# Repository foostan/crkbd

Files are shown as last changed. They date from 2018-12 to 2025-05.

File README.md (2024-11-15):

# Corne keyboard

The Corne keyboard is a split keyboard with 3x6 column staggered keys
and 3 thumb keys, based on [Helix](https://github.com/MakotoKurauchi/helix).
Crkbd stands for Corne Keyboard.

v4

## Latest versions
- corne-cherry: for Cherry MX compatible switches

  - v4 Hotswappable ([JP](docs/corne-cherry/v4/buildguide_jp.md)/[EN](docs/corne-cherry/v4/buildguide_en.md))
  - v4 Soldering (will be released)
- corne-chocolate: for Kailh choc v1 and v2 switches
  - v4 Hotswappable ([JP](docs/corne-chocolate/v4/buildguide_jp.md)/[EN](docs/corne-chocolate/v4/buildguide_en.md)):
  - v4 Soldering (will be released)

## Old versions

- corne-classic: for Cherry MX compatible switches 
  - v1 Soldering: ([JP](docs/corne-classic/buildguide_jp.md)/[EN](docs/corne-classic/buildguide_en.md))
- corne-cherry: for Cherry MX compatible switches
  - v2 Hotswappable: ([JP](docs/corne-cherry/v2/buildguide_jp.md)/[EN](docs/corne-cherry/v2/buildguide_en.md))
  - v2 Hotswappable tilting version: ([tilting, JP](docs/corne-cherry/v2/buildguide_tilting_tenting_plate_jp.md)/[tilting, EN](docs/corne-cherry/v2/buildguide_tilting_tenting_plate_en.md)):
  - v3 Hotswappable: ([JP](docs/corne-cherry/v3/buildguide_jp.md)/[EN](docs/corne-cherry/v3/buildguide_en.md))
- corne-chocolate: for Kailh choc v1 switches
  - v2 Hotswappable: ([JP](docs/corne-chocolate/v2/buildguide_jp.md)/[EN](docs/corne-chocolate/v2/buildguide_en.md)):
- corne-light: for easy build with a simple PCB
  - v1 Soldering: ([JP](docs/corne-light/v1/buildguide_jp.md)/[EN](docs/corne-light/v1/buildguide_en.md)):
  - v2 Soldering: ([JP](docs/corne-light/v2/buildguide_low_edition_jp.md)/[EN](docs/corne-light/v2/buildguide_low_edition_en.md)):

## Notice
There are currently reports of a bug in v4.* caused by electromagnetic interference. Depending on the environment, one or both of the left and right keyboards may stop working. It is known that this is often caused by EMI emitted by mobile phones. If you experience this kind of problem, reconnect the USB, move the EMI-generating device (probably a mobile phone) more than 30 cm away from the keyboard, and observe the situation.

For more details, please see this issue. We look forward to receiving any new information.
https://github.com/foostan/crkbd/issues/265

## Images

### Cherry
corne-cherry



### Chocolate
corne-chocolate



### Drawing
sketche

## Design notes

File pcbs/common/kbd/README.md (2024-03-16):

# KBD - for building keyboard libraries

## KiCad Footprint Libraries

This repository contains the KiCad footprint libraries for building keyboard.

**The libraries in this repository are intended to be used with KiCad version 5 or with a nightly that supports rounded rectangle and polygon pads.**

Each footprint library is stored as a directory with the `.pretty` suffix. The footprint files are `.kicad_mod` files within 

## KiCad Symbols

This repository contains the KiCad schematic symbol libraries for building keyboard.

**The libraries in this repositiory are intended for KiCad version 5.x**

Each symbol library is stored as a `.lib` and `.dcm` file pair.

## KiCad 3D Models
This repository contains 3D models for rendering and MCAD integration, for use with [KiCad EDA](http://www.kicad.org/) software.
The model needs a mechanical model source (a manually-modelled or script-generated file); its WRL counterpart file must be obtained as a conversion from the MCAD model

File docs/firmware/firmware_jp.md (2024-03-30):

# Firmware

バージョンによって使用するファームウェアのリビジョンが異なりますので下記よりお選びください。

- v1 - v3
  - [rev1](rev1/firmware_jp.md)
- v4
  - [rev4](rev4/firmware_jp.md)

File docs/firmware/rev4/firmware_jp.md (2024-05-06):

# ファームウェア
こちらは Corne v4向け(rev4) のファームウェアガイドになります。

## ファームウェアの書き込み
はじめにPCBのバージョンをご確認ください(v4.0.0 または v4.1.0)。\
そしてVIA/Vial用のファームウェアを下記からダウンロードします。

standard (3x6) v4.0.0

- [crkbd_rev4_0_standard_via.uf2](https://github.com/foostan/kbd_firmware/raw/main/keyboards/crkbd/qmk/qmk_firmware/.build/crkbd_rev4_0_standard_via.uf2)
- [crkbd_rev4_0_standard_vial.uf2](https://github.com/foostan/kbd_firmware/raw/main/keyboards/crkbd/vial-kb/vial-qmk/.build/crkbd_rev4_0_standard_vial.uf2)

mini (3x5) v4.0.0

- [crkbd_rev4_0_mini_via.uf2](https://github.com/foostan/kbd_firmware/raw/main/keyboards/crkbd/qmk/qmk_firmware/.build/crkbd_rev4_0_mini_via.uf2)
- [crkbd_rev4_0_mini_vial_mini.uf2](https://github.com/foostan/kbd_firmware/raw/main/keyboards/crkbd/vial-kb/vial-qmk/.build/crkbd_rev4_0_mini_vial_mini.uf2)

standard (3x6) v4.1.0

- [crkbd_rev4_1_standard_via.uf2](https://github.com/foostan/kbd_firmware/raw/main/keyboards/crkbd/qmk/qmk_firmware/.build/crkbd_rev4_1_standard_via.uf2)
- [crkbd_rev4_1_standard_vial.uf2](https://github.com/foostan/kbd_firmware/raw/main/keyboards/crkbd/vial-kb/vial-qmk/.build/crkbd_rev4_1_standard_vial.uf2)

mini (3x5) v4.1.0

- [crkbd_rev4_1_mini_via.uf2](https://github.com/foostan/kbd_firmware/raw/main/keyboards/crkbd/qmk/qmk_firmware/.build/crkbd_rev4_1_mini_via.uf2)
- [crkbd_rev4_1_mini_vial_mini.uf2](https://github.com/foostan/kbd_firmware/raw/main/keyboards/crkbd/vial-kb/vial-qmk/.build/crkbd_rev4_1_mini_vial_mini.uf2)

BOOTボタンを押しながらPCに接続するか、PCに接続した状態でBOOTボタンを押しながらリセットボタンを押します。
すると、RPI-PR2デバイスがマウントされます。

btn

ダウンロードしたuf2ファイルをRPI-PR2デバイスにドロップすると書き込みが完了します。

flash

片側にファームウェアの書き込みが完了したら、もう片方も同じ手順で書き込みを行います。

## (オプション) 自分でファームウェアをビルドする場合
こちらを参照してください。https://github.com/foostan/kbd_firmware

## キーマップの変更

### VIA

[VIA](https://usevia.app/) はVIA用のファームウェアを書き込むことで利用することできます。\
Corne v4を使う場合は、下記からjsonファイルをダウンロードし、VIAでロードしてください(設定画面のShow Design tabを有効にする必要があります)。

- [Corne v4](https://github.com/foostan/kbd_firmware/blob/main/keyboards/crkbd/the-via/crkbd_rev4.json)
- [Corne v4 mini](https://github.com/foostan/kbd_firmware/blob/main/keyboards/crkbd/the-via/crkbd_rev4_mini.json)

enable_design_tab
load_json
loaded_json

### Vial

[Vial](https://vial.rocks/) はVial用のファームウェアを書き込むことで利用することできます。

Vial

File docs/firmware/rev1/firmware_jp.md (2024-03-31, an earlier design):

# ファームウェア
こちらは Corne v1-v3向け(rev1) のファームウェアガイドになります。

## ファームウェアの書き込み

### [Remap](https://remap-keys.app/catalog/EfziB9K7ZcxLnIHXl5AQ/firmware) を使う
最も簡単で推奨する方法はRemapを使って crkbd:via を書き込む方法です。
Remapにアクセスし指示に従って書き込みを行ってください。
flash_by_remap

片側にファームウェアの書き込みが完了したら、もう片方も同じ手順で書き込みを行います。

### Flash the firmware by [QMK Toolbox](https://github.com/qmk/qmk_toolbox) を使う

VIA用のファームウェアを [crkbd_rev1_via.hex](https://github.com/foostan/kbd_firmware/blob/main/keyboards/crkbd/qmk/qmk_firmware/.build/crkbd_rev1_via.hex) からダウンロードします。

QMK Toolbox の 「Open」 からダウンロードしたファイルを指定します。
そしてキーボードをUSBで接続し、リセットボタンを押すとファームウェアの書き込みが始まります。
下記のように書き込みのメッセージが表示されれば完了です。

qmk_toolbox_flashed

片側にファームウェアの書き込みが完了したら、もう片方も同じ手順で書き込みを行います。

## (オプション) 自分でファームウェアをビルドする場合
こちらを参照してください。https://github.com/foostan/kbd_firmware

## キーマップの変更

[VIA](https://usevia.app/) はVIA用のファームウェアを書き込むことで利用することできます。

via_begin

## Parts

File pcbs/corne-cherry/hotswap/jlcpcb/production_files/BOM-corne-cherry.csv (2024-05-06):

Comment | Designator | Footprint | LCSC
W25Q128JVSIQ | U4,rU4 | SOIC-8_5.23x5.23mm_P1.27mm | C113767
1k | R3,R6,rR3,rR6 | R_0402_1005Metric | C11702
TRS | J2,rJ2 | PJ-398A-5A_PJ-399B-6A | C128994
TPD4E05U06DQAR | U3,rU3 | USON-10_2.5x1.0mm_P0.5mm | C138714
RB521S30T1G | ZD1,rZD1 | D_SOD-523 | C145179
NCP1117LPST33T3G | U2,rU2 | SOT-223-3_TabPin2 | C146799
100n | C10,C12,C13,C14,C15,C3,C4,C7,C9,rC10,rC12,rC13,rC14,rC15,rC3,rC4,rC7,rC9 | C_0402_1005Metric | C1525
10u | C11,C6,rC11,rC6 | C_0402_1005Metric | C15525
27p | C1,C2,rC1,rC2 | C_0402_1005Metric | C1557
RP2040 | U1,rU1 | QFN-56-1EP_7x7mm_P0.4mm_EP3.2x3.2mm | C2040
1N4148WT | D1,rD1 | D_SOD-523 | C232841
10k | R7,R9,rR7,rR9 | R_0402_1005Metric | C25744
5.1k | R1,R2,rR1,rR2 | R_0402_1005Metric | C25905
5.6k | R8,rR8 | R_0402_1005Metric | C25908
TYPE-C-31-M-13C | J1,rJ1 | TYPE-C-31-M-13C | C2848620
27 | R4,R5,rR4,rR5 | R_0402_1005Metric | C2909343
TS-1088R-02026 | SMDSW1,SMDSW2,rSMDSW1,rSMDSW2 | TS-1088R-02026 | C455280
YS-SK6812MINI-E | EXLED1,EXLED2,LED1,LED10,LED11,LED12,LED13,LED14,LED15,LED16,LED17,LED18,LED19,LED2,LED20,LED21,LED3,LED4,LED5,LED6,LED7,LED8,LED9,rEXLED1,rEXLED2,rLED1,rLED10,rLED11,rLED12,rLED13,rLED14,rLED15,rLED16,rLED17,rLED18,rLED19,rLED2,rLED20,rLED21,rLED3,rLED4,rLED5,rLED6,rLED7,rLED8,rLED9 | YS-SK6812MINI-E | C5149201
RotaryEncoder_Switch | EXSW1,EXSW2,SW1,SW10,SW11,SW12,SW13,SW14,SW15,SW16,SW17,SW18,SW19,SW2,SW20,SW21,SW3,SW4,SW5,SW6,SW7,SW8,SW9,rEXSW1,rEXSW2,rSW1,rSW10,rSW11,rSW12,rSW13,rSW14,rSW15,rSW16,rSW17,rSW18,rSW19,rSW2,rSW20,rSW21,rSW3,rSW4,rSW5,rSW6,rSW7,rSW8,rSW9 | keyswitch_cherrymx_hotswap_1u_rotary_encoder_ec12 | C5156480
1u | C16,C5,C8,rC16,rC5,rC8 | C_0402_1005Metric | C52923
12MHz 18pF | Y1,rY1 | Crystal_SMD_3225-4Pin_3.2x2.5mm | C91749

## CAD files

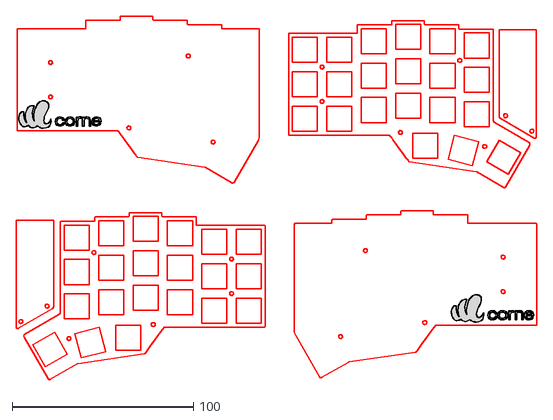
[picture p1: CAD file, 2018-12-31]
case/acrylic_plate/top-bottom.dxf
287.2 x 200.8

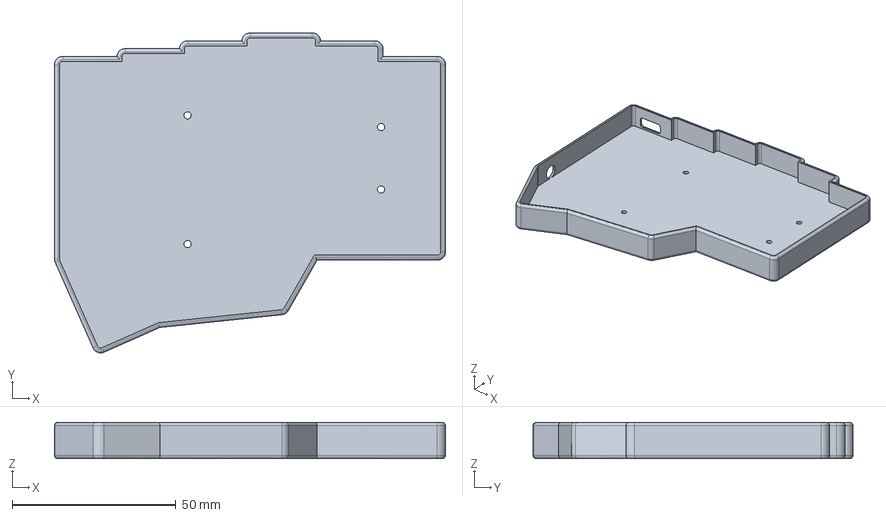
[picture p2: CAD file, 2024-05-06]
cases/3x5/right.step
119.3 x 97.6 x 11.1 mm

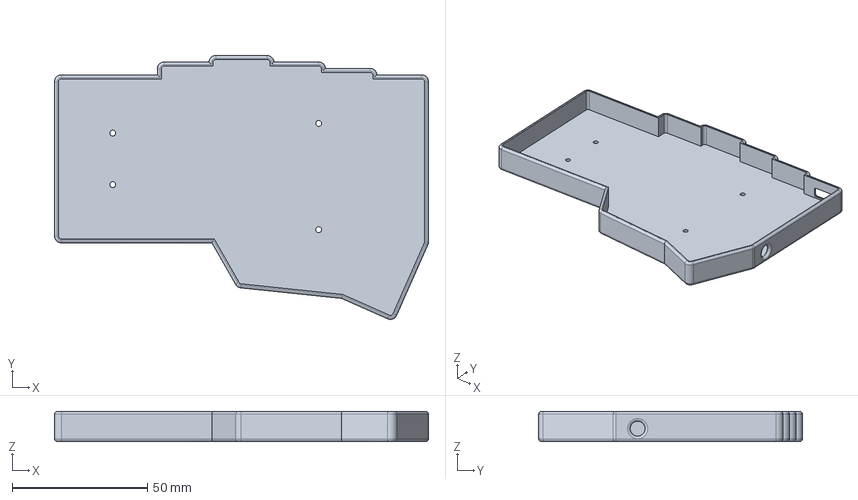
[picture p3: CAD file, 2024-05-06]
cases/3x6/left.step
138.3 x 97.6 x 11.1 mm

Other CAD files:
cases/3x5/left.step
cases/3x6/right.step

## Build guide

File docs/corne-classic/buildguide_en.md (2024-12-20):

# Build Guide

## Parts

### Required

| Name | Count | Remarks |
|:-|:-|:-|
| PCB | 2 | |
| Plate | 2 sets | |
| ProMicro | 2 | |
| TRRS Jack | 2 | |
| TRS(3 pole) cable | 1 | TRRS(4 pole) cable works too. |
| Tact switch | 2 | |
| Diode | 42 | You need SMD for low profile. |
| Key Switch | 42 | |
| Key Cap | 42 | 1u x 40,  1.5u x 2 |
| Spacer M2 7.5mm | 10 | use 3mm for low profile |
| Spacer M2 9mm or 11mm | 4 | |
| Screw M2 4mm | 28 | |
| Rubber foot | 10 | |

### Optional

| Name | Count | Remarks |
|:-|:-|:-|
| OLED Module | 1 or 2 | |
| 4x1 Pin Male Header | 2 | For OLED |
| 4x1 Pin Female Socket | 2 | For OLED |
| SK6812MINI | 54 | Front side x 42, back side x 12 |
| Addressable LED Strip | 2 | exclusive with SK6812MINI |



## Advance preparation

If you build the firmware yourself,
it will take some time to set up the environment,
so it's best to start at the beginning. \
For more information,
please see [docs/firmware/rev1](../firmware/rev1/firmware_en.md).

## Soldering

PCB is reversible; use one for the left hand side and the other for the right.

### Diodes

#### For non Low Profile keyswitches

Solder diodes as indicated in the picture.
You can place it on either side,
but front side is recommended if you implement under-glow LED.
You can use SMD diodes too.



Diode has polarity;
make sure to match the polarity with PCB silkscreen.

<- Before | After ->



#### For Low Profile Keyswitches

If you use low profile keyswitches,
you have to implement SMD diodes __on the back side__.
Otherwise, diodes will interfere with top plate.

As with normal diodes,
[SMD diodes have polarity](https://learn.sparkfun.com/tutorials/polarity/diode-and-led-polarity).
The lines on the SMD diode should be on the same side as the line on the PCB silkscreen.

### LEDs (Optional)

Implement LEDs under keyswitches (No. 7 through 27) upward facing,
and others (No. 1 through 6) on the back side(under-glow),
as indicated in the picture.



For No.7 to 27 LEDs, __Install LEDs from the back side__ as shown below.
Note the '**o**' silkscreen marking
and use them as a guide to implement LEDs in the direction.
On some versions  of the PCB (e.g. Corne-cherry v2),
the '**o**' silkscreen marking has been replaced by a white square
around one of the pads,
but the principle is still the same.



The LED has one pad that is shaped like a square.
That square should connect to the pad that has the '**o**' silkscreen marking:



There are many different techniques on how to solder the LEDs,
but [this video](https://twitter.com/foostan/status/1005656803818889216)
might give you an idea on how to do it.

For No. 1 to 6 LEDs, solder the pattern on the side of the device
(highlighted in pink on the picture) and the PCB pattern (blue on the picture).
Apply flux and take small amount of solder with a soldering iron
and press it on the edge of the patterns.



LEDs are connected in the order of the number on the picture above.
If it turns on only halfway,
it is likely that first LED that doesn't turn on
or the last LED that turns on is not implemented correctly.

__Note__ that the default Crkbd firmware has __LEDs turned off__,
so you'll have to turn them on before you can test
(see the firmware section for instructions how).

### Jumpers for OLED modules (optional)

To use OLED modules, short circuit the jumper patterns.
__Only short circuit the front side__



### TRRS socket, reset switch, OLED header sockets

Install TRRS sockets and reset switches as in the picture.
For OLEDs, also implement pin sockets.



### ProMicro

Before you start,
flash the Crkbd firmware to the ProMicros to make sure they are alright.

The ProMicro is then installed
__in the set of holes that has a white frame on the frontside of the PCB__.
Make sure you solder it in the right set of holes,
as desoldering the ProMicro is hard.
Implement pin headers in the white frame,
then install ProMicro with its __backside up__.



The picture is the right hand side, but it's the same for the left hand side -
pins into the through holes in the white frame as seen from the frontside,
placing the ProMicro with its backside up.

### OLED Module

Implement pin header onto the OLED modules,
then insert them into the pin sockets.



Adjust the height of the spacer accordingly to the height of pin header.
Most common pin header/socket and 11mm spacers are used in the picture.

### Use socket to Mount ProMicro

With using sockets for mounting ProMicro,
you can replace it easily when it breaks.
Two methods are introduced here.

#### Using Spring Loaded Header

Refer to the [Helix build guide](
https://github.com/MakotoKurauchi/helix/blob/master/Doc/buildguide_en.md#pro-micro)

ProMicro kit with spring loaded headers is available at Yusha-Kobo

<https://yushakobo.jp/shop/promicro-spring-pinheader/>

Using OLEDs available at Yusha-Kobo which come with low profile header,
together with and 9mm spacers, you can build them thin and gap-less.



#### Using Pin Sockets

Low profile pin sockets are available from Akizuki Denshi etc. Requires some work.

<http://akizukidenshi.com/catalog/g/gC-03138/>

Install a couple of 12x1 pin sockets on a breadboard.



Using male 12x1 pin headers, fixate ProMicro onto the pin sockets.



Remove plastic pin holders, solder the pins to ProMicro,
and then cut extra pins.



#### Comparison

Spring loaded headers can make the height lower.



Comparing pin-headers in the picture.
Headers come with OLED available at Yusha-Kobo are lower.



### Testing

It is recommended to test the ProMicro and OLED modules
before installing keyswitches,
because rework would be difficult after that.

First, build QMK Firmware for built for Crkbd
and install on ProMicro (if you haven't already done so).



Using the default keymap,
OLED will show information on the keyswitches being pressed.
Check the connections by short-circuiting keyswitch soldering pads
with tweezers or a bit of soldering wire.
Check all of them.

If you have OLED displays,
you can verify that all keys are responding
by looking at the log information showed there.
It will say which row and column was pressed,
e.g. `1x5` or `0x2`. Using the tweezers or wire,
connect each buttons soldering pads and make sure the display changes.
If something isn't working,
take note of the which row x column it is that isn't working,
as it can help when troubleshooting.

If you have mounted LEDs,
also make sure all of them are turned on.
As note before, the default firmware has LEDs __turned off__,
so you have to turn them on in the firmware before you test.



### Keyswitches and Top Plate

Sandwich top-plate with PCB and key-switches.



### Bottom Plate

Use 3mm spacers for low-profile,
Attach bottom plate to the PCB using 7.5mm (3mm for low-profile) spacers.
Then attach six rubber feet.



### Keycaps

Lastly install keycaps.

lrg_dsc03895

## Firmware

See below to flash the firmware to the ProMicro. \
[docs/firmware/rev1](../../firmware/rev1/firmware_en.md)

### Turning LEDS on

To turn the LEDs on, you have to edit the `rules.mk` file.
If you use the default layout,
it can be found here `keyboards/crkbd/keymaps/default/rules.mk`.
Add the following line to the top of the file:

```
RGBLIGHT_ENABLE = yes
```

Compile and flash to both sides and all LEDs should turn on
and __glow red__ if you have soldered everything correctly.
If you run the default firmware and the LEDs turn a differrent color,
the data to the LEDs is probably corrupted somewhere along the way.
Check the LED before the first one
turning a different color using the troubleshooting guide below.

## Troubleshooting

Here are some tips and tricks on how to troubleshot a board that is not working.

### No LEDs turn on

There are a number of things that might be wrong.
First of all, make sure you have __turned on LED lighting in the firmware__.
If that is the case, then chances are there might be a problem with the first LED.
Try the suggestions in the next section.

### Some LEDs not turning on

If some LEDs aren't turning on,
check the first LED not turning on __or__ the one before it.

LED numbering on the PCB

Here are some things to try out:

- Make sure the LED is soldered correctly.
  Check the pads to see if it looks like they have a proper connection.
- Check the LED orientation.
  Use the pictures above the see the correct orientation.
  Since the first LED is soldered with its back against the PCB,
  you might have to determinewhat the orientation should look like from the front
  using LEDs 7-27 (just double check that they are oriented correctly first).
- If both of the above looks good, chances are the LED was damaged during soldering.
  Either replace it directly or use the diod mode of a multimeter to test the connectivity.
  One way to do this is by simply comparing to some of the other LEDs you have soldered.
  Choose two of the LED's pads (out of the four available)
  and compare the reading to that of some of the other LEDs
  (taking care to measure the same pads with the same needles of your multimeter).
  Work your way through all combinations of pads and needles.
  If the differ, you either have a broken LED or bad connectivity.
  Or simply desolder the LED directly, might be quicker. :)

### A full row/column of keys not working

If a full row or column of keys is not working,
then the culprit is most likely the connection between the PCB and the ProMicro.
Check your soldering and make sure there's a proper connection
and that you have soldered the ProMicro in the right set of holes.
If soldering looks okay, then your ProMicro might be damaged.
You can exclude the possibility of problems with the PCB,
paths and diodes by short circuiting the pins on the ProMicro directly,
using a bit of wire.
Connecting one row pin with one column pin should result in the corresponding key.
Some PCBs have silkscreen print indicating which pin is which row or column,
to make this process easier.

### Random key(s) not working

If it is not a full row or column of keys that are not working,
the issue is most likely that there's no connection between the key and the ProMicro.
There are multiple places where the connection can get interupted:

- between keyswitch and PCB (if you have installed the switches)
- between keyswitch and hotswap socket (if you use them)
- between hotswap socket and PCB (again, if you use hotswap sockets)
- in the diodes between the key and the ProMicro
- in the paths inside the PCB

If you have installed the keyswitches already,
then check the soldering on the keyswitch.
if you use hotswap sockets,
check that you didn't accidentally bend one of the legs of the switch
when inserting into the socket and that the socket soldering is alright.

Next, visually inspect the PCB.
If it looks scratched or damaged anywhere along the path
from ProMicro to diode to keyswitch, the path might be interrupted.
If you find a spot that looks damaged,
you can use some wire to bypass the section that is damaged
(e.g. connecting the ProMicro directly to the first pad of the diode).
If this fixes the key, then you can either opt to keep the wire permanently,
or you can try to repair the path.
The path can be repaired by carefully scraping off the paint
from a section of the path that is okay on either side of the damaged part
(use a small flat head screwdriver intended for electronics).
Then clean carefully with alcohol and solder a new connection.
Youtube might have some guides on how to do this.

If the PCB looks okay, then the diode would be the next thing to check.
Begin by checking the soldering.
If it looks okay, then the diode itself might be damaged.
If you have a multimeter, use it to check the diode.
The reading should be the same as for diodes connected to keys that are working
(when measuring, remember that diodes have polarity).
You can also use tweezers or a bit of soldering wire
to connect the soldering pads on each side of the diode if you don't have a multimeter.
Pressing the key (or short circuiting the pads where the key would go)
after connecting the pads should make a key press being registered.
If this is the case, or if you used the multimeter
and got a different reading from the diode,
then check your soldering and replace the diode if necessary.

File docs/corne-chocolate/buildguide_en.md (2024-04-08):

# Build Guide

This is the Corne Chocolate build guide.
The build guide differs depending on the version of your board,
so please choose your own from the following.

- [v2 build guide](https://github.com/foostan/crkbd/blob/main/docs/corne-chocolate/v2/buildguide_en.md)
- [v4 build guide](https://github.com/foostan/crkbd/blob/main/docs/corne-chocolate/v4/buildguide_en.md)

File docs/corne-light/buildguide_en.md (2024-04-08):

# Build Guide

This is the Corne Light build guide.
The build guide differs depending on the version of your board,
so please choose your own from the following.

- [v1 build guide](https://github.com/foostan/crkbd/blob/main/docs/corne-light/v1/buildguide_en.md)
- [v2 low-edition build guide](https://github.com/foostan/crkbd/blob/main/docs/corne-light/v2/buildguide_low_edition_en.md)

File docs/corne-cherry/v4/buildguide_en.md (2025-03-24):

# Build Guide
This is the build guide for Corne Cherry v4.

corne-v4-cherry

## Parts

### Required

| Name | Count | Remarks |
|:---|:---|:---|
| PCB | 1 set | |
| Case | 1 set | |
| Switch plate | 1 set | FR4 1.6mm thick |
| Key switches | 42 - 46 | Only Cherry MX compatible |
| Keycaps | 42 - 46 | 1u 40 pcs, 1.5u 2 pcs |
| Spacer M2 | 8 | 7.5 mm For Case assembly |
| Screw M2 | 16 | 5 mm For Case assembly |
| Rubber cushion | 8 | |
| TRRS (4 poles) cable | 1 | v4.0.0: TRS (3 poles) cable is not compatible<br/>v4.1.0: TRS (3 poles) cable is compatible |
| Type-C cable | 1 | |

### Optional

| Name | Count | Remarks |
|:---|:---|:---|
| Rotary Encoder | 0 - 4 pieces | compatible product of the rotary encoder EC12 |

## Firmware preparation
please see [docs/firmware/rev4](../../firmware/rev4/firmware_en.md).

## Build
This is the build guide for the left hand side. The right side is the same procedure.

### 1: Attach switches to PCB
plate
plate-side

### Option: Solder rotary encoders instead of switches
If a rotary encoder is used, it can be attached instead of a switch at the position shown in the figure below. In that case, soldering from the back side is required.

rotary-encoder

### 2: Attach spacers to Case
case

### 3: Mount 1 to 2
switch+case

### 4: Attach rubber cushions
rubber-cushion

### 5: Attach keycaps
keycap

## Note
If the TRRS cable is plugged or unplugged while the USB cable is connected, the keyboard's microcontroller may be damaged.  
Before plugging or unplugging the TRRS cable, always ensure that the USB cable is disconnected.

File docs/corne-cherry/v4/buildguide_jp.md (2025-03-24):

# Build Guide
こちらは Corne Cherry v4 のビルドガイドになります。

corne-v4-cherry

## Parts

### Required

| Name | Count | Remarks |
|:---|:---|:---|
| PCB | 1 set | |
| Case | 1 set | |
| Switch plate | 1 set | FR4 厚さ 1.6mm |
| Key switches | 42 - 46 | Cherry MX 互換のみ |
| Keycaps | 42 - 46 | 1u 40 pcs, 1.5u 2 pcs |
| Spacer M2 | 8 | 長さ 7.5 mm |
| Screw M2 | 16 | 長さ 5 mm |
| Rubber cushion | 8 | |
| TRRS (4 poles) cable | 1 | v4.0.0: TRS (3 poles) は非対応<br/> v4.1.0: TRS (3 poles) に対応 |
| Type-C cable | 1 | |

### Optional

| Name | Count | Remarks |
|:---|:---|:---|
| Rotary Encoder | 0 - 4 pieces | EC12互換  |

## Firmware preparation
[docs/firmware/rev4](../../firmware/rev4/firmware_jp.md) を参照してください。

## Build
これは左手側のビルドガイドですが、右手側も手順は同じです。

### 1: キースイッチを取り付ける
plate
plate-side

### オプション: キースイッチの代わりにロータリーエンコーダをはんだ付けする
ロータリーエンコーダを使う場合、下記の図の位置にキースイッチの代わりにロータリーエンコーダを付けることができます。その場合は、裏側からはんだ付けが必要です。

rotary-encoder

### 2: ケースにスペーサーを付ける
case

### 3: 1と2を組み合わせる
switch+case

### 4: ラバークッションを取り付ける
rubber-cushion

### 5: キーキャップを取り付ける
keycap

## 注意
USBケーブルが刺さっている状態でTRRSケーブルの抜き差しが行われると、キーボードのマイコンが破壊されることがあります。  
TRRSケーブルを抜き差しする際は、USBケーブルが外れていることを確認してから行うようにしてください。

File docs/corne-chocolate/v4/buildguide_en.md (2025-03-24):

# Build Guide
This is the build guide for Corne Chocolate v4.

corne-v4-chocolate

## Parts

### Required

| Name | Count | Remarks |
|:---|:---|:---|
| PCB | 1 set | |
| Case | 1 set | |
| Switch plate | 1 set | FR4 1.6mm thick |
| Key switches | 42 - 46 | Only Kailh choc v1 and v2 switches |
| Keycaps | 42 - 46 | 1u 40 pcs, 1.5u 2 pcs |
| Spacer M2 | 8 | 5 mm For Case assembly |
| Screw M2 | 16 | 4.5 mm For Case assembly |
| Rubber cushion | 8 | |
| TRRS (4 poles) cable | 1 | TRS (3 poles) cable is not compatible |
| Type-C cable | 1 | |

### Optional

| Name | Count | Remarks |
|:---|:---|:---|
| Rotary Encoder | 0 - 4 pieces | compatible product of the rotary encoder EC12 |

## Firmware preparation
please see [docs/firmware/rev4](../../firmware/rev4/firmware_en.md).

## Build
This is the build guide for the left hand side. The right side is the same procedure.

### 1: Attach switches to PCB
plate
plate-side

### 2: Attach spacers to Case
case

### 3: Mount 1 to 2
switch+case

### 4: Attach rubber cushions
rubber-cushion

### 5: Attach keycaps
keycap

## Note
If the TRRS cable is plugged or unplugged while the USB cable is connected, the keyboard's microcontroller may be damaged.  
Before plugging or unplugging the TRRS cable, always ensure that the USB cable is disconnected.

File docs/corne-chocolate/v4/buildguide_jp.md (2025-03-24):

# Build Guide
こちらは Corne Chocolate v4 のビルドガイドになります。

corne-v4-chocolate

## Parts

### Required

| Name | Count | Remarks |
|:---|:---|:---|
| PCB | 1 set | |
| Case | 1 set | |
| Switch plate | 1 set | FR4 厚さ 1.6mm |
| Key switches | 42 - 46 | Kailh choc v1 and v2 スイッチのみ |
| Keycaps | 42 - 46 | 1u 40 pcs, 1.5u 2 pcs |
| Spacer M2 | 8 | 長さ 5.5 mm |
| Screw M2 | 16 | 長さ 4.5 mm |
| Rubber cushion | 8 | |
| TRRS (4 poles) cable | 1 | TRS (3 poles) は非対応 |
| Type-C cable | 1 | |

### Optional

| Name | Count | Remarks |
|:---|:---|:---|
| Rotary Encoder | 0 - 4 pieces | EC12互換  |

## Firmware preparation
[docs/firmware/rev4](../../firmware/rev4/firmware_jp.md) を参照してください。

## Build
これは左手側のビルドガイドですが、右手側も手順は同じです。

### 1: キースイッチを取り付ける
plate
plate-side

### 2: ケースにスペーサーを付ける
case

### 3: 1と2を組み合わせる
switch+case

### 4: ラバークッションを取り付ける
rubber-cushion

### 5: キーキャップを取り付ける
keycap

## 注意
USBケーブルが刺さっている状態でTRRSケーブルの抜き差しが行われると、キーボードのマイコンが破壊されることがあります。  
TRRSケーブルを抜き差しする際は、USBケーブルが外れていることを確認してから行うようにしてください。

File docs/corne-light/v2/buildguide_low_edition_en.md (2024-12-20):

# Build Guide

This is the build guide for Corne Light v2 Low edition.

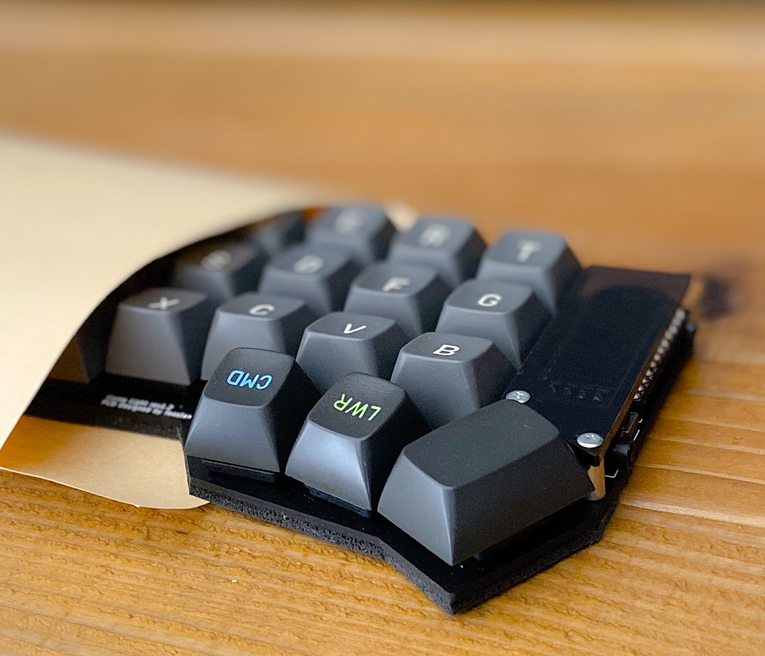
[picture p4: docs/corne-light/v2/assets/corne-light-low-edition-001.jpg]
corne-light-low-edition-001

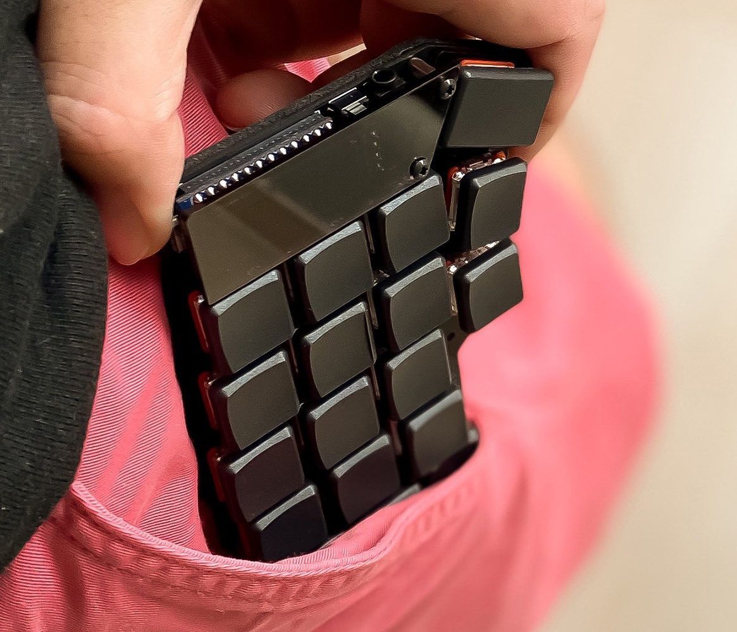
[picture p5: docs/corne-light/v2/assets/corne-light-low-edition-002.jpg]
corne-light-low-edition-002

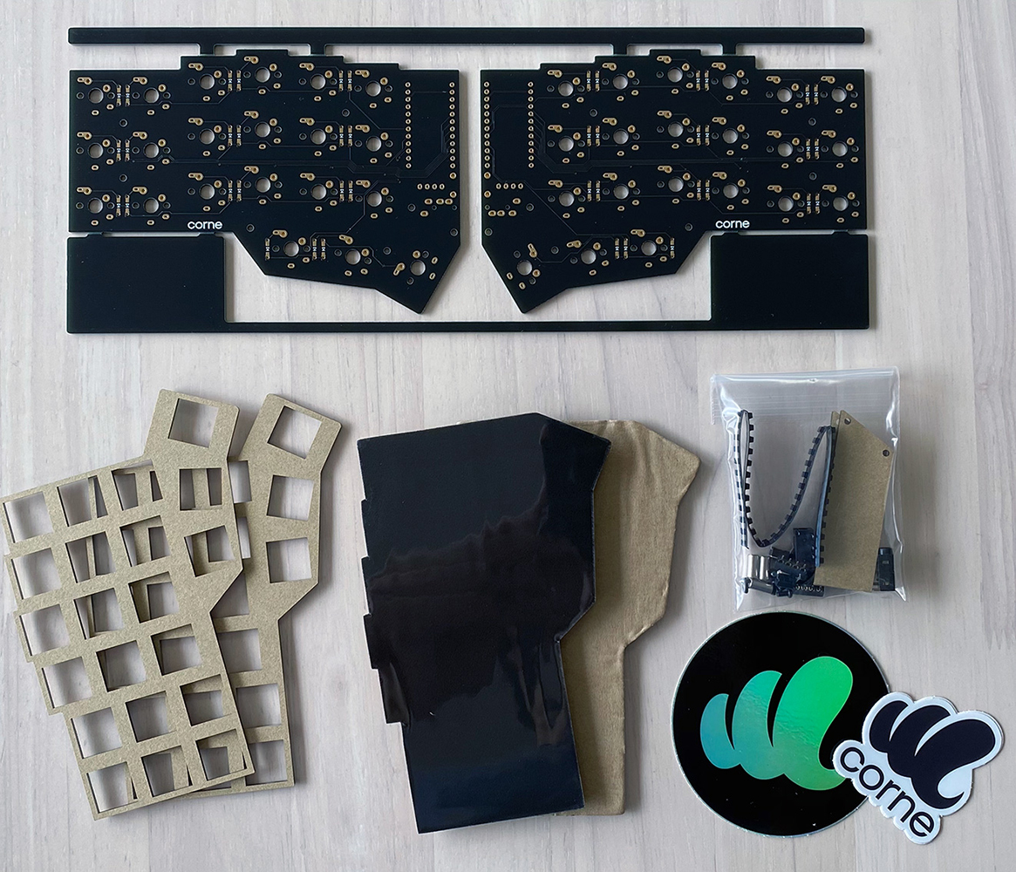
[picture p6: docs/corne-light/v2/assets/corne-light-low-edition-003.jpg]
corne-light-low-edition-003


## Parts

### Required

| Name | Count | Remarks |
|:-|:-|:-|
| PCB | 1 set | |
| Top plate (acrylic) 2mm | 2 sheets | |
| Bottom foam | 2 sheets | Special foam is cut out with a special mold |
| OLED protective plate | 2 sheets | |
| ProMicro | 2 sheets | |
| TRRS jack | 2 | |
| Tact switch | 2 | |
| Diodes | 42 | Recommended SMD Parts |
| Key switches | 42 | Kailh Choc v1 or v2 recommended |
| Keycaps | 42 pcs | 1u 40 pcs, 1.5u 2 pcs |
| Spacer M2 9mm | 4 pieces | |
| Screw M2 4mm | 8 screws | |
| TRRS (4 poles) cable | 1 | TRS (3 poles) cable is also acceptable |
| Micro USB cable | 1 | |

### Optional

| Name | Count | Remarks |
|:-|:-|:-|
| OLED module | 2 sheets | |
| Pin header for OLED module 4 series 1.5mm | 2 | |
| 4 pin sockets for OLED module 2.5mm | 2 | |

## Advance preparation

If you build the firmware yourself,
it takes time to prepare the environment,
so it is recommended to start first. \
See [docs/firmware/rev1](../../firmware/rev1/firmware_en.md)
for more information.

## Verification

The PCB for Corne Light v2 is as follows.
Make sure it is the same as your PCB.

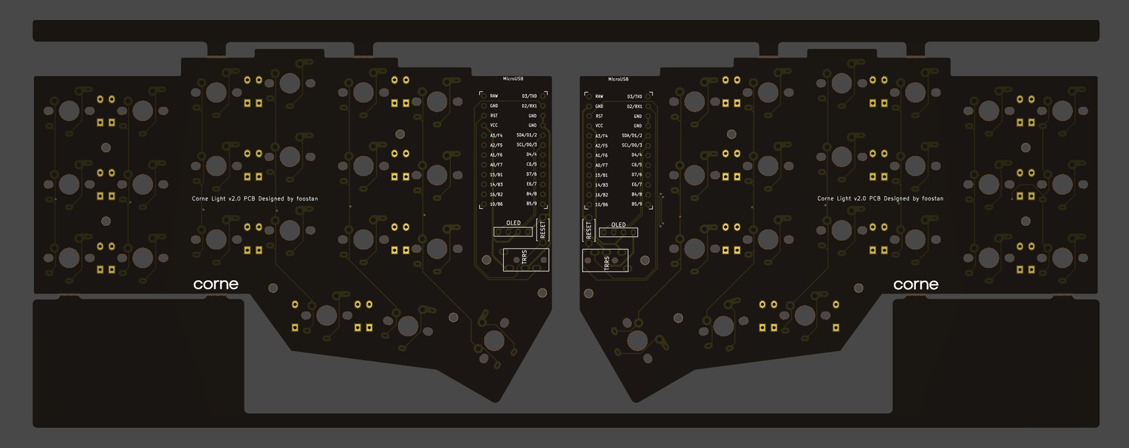
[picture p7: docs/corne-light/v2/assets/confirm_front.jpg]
confirm_front


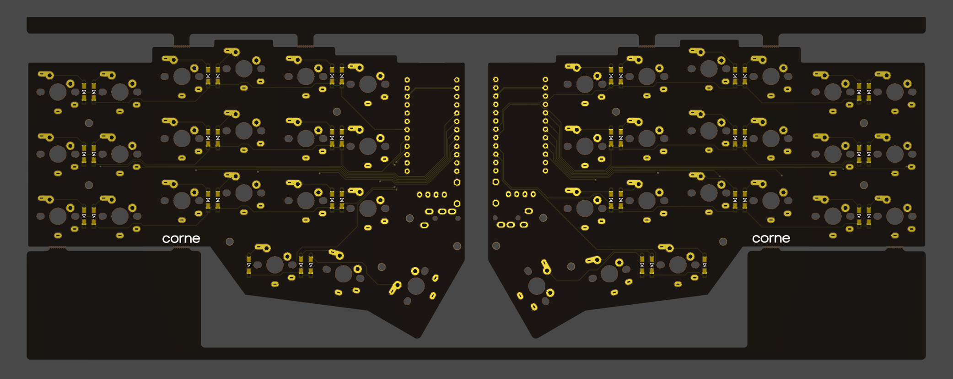
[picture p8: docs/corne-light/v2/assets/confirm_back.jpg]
confirm_back


The PCB comes with a frame for manufacturing reasons.
You can fold it by hand to remove it, but if it is difficult,
make a cut in the joint \* with a cutter or similar,
to make it easier to remove.
In addition, the joint can be cleaned with a file.

\* *Joint part: There are a total of 8 parts,
which are marked in red in the image below.*

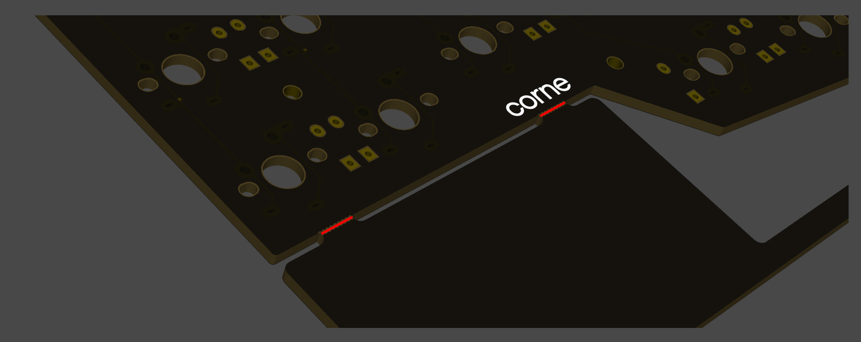
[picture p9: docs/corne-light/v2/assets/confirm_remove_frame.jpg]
confirm_remove_frame


## Assembly

### Diodes

Solder diodes for SMD components.
Since SMD parts are very small,
it is convenient to have tweezers and counter-acting tweezers.

**The diode has a fixed mounting direction**,
so solder it so that the "|" mark on the part faces the "|" on the diode mark "|◁".
In addition, Corne's PCB has all the same diode mounting orientations.

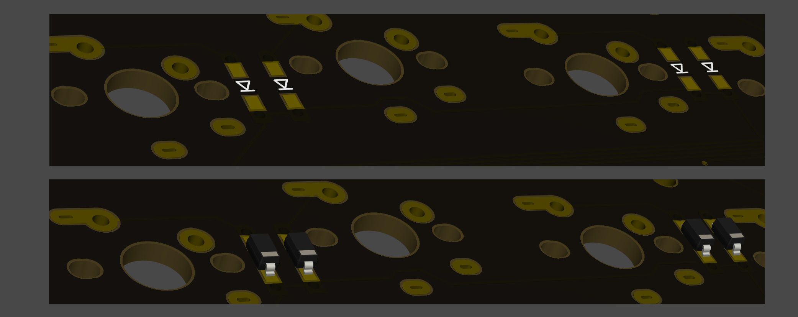
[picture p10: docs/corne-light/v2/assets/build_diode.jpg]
build_diode


<details>
<summary>TIPS: Tips for installing SMD parts</summary>

The trick is to attach the SMD parts, but first, as a spare solder,
put the solder on only one side of the pad.

tips_building_smd_01

Next, solder one leg of the diode so that the spare solder melts.
At this time, it is recommended to use reverse-action tweezers,
because you can hold the chip parts firmly without exerting force
and you can concentrate on alignment and soldering.
Also, if the soldering iron is too hot or the solder is touched too much,
the flux contained in the solder may evaporate and form a clean pile of solder,
but it can be repaired later,
so at this point you should only care about attaching parts.
It's okay.

tips_building_smd_02

It is okay if the diode does not float when viewed from the side
when one foot is attached.
If it floats, press the diode with tweezers or your fingers
and reheat the soldered part with a soldering iron to clean it.

tips_building_smd_03

Then solder the other one.
Be careful not to apply too much,
as a small amount of solder is sufficient.
If you apply too much, you can remove it with a blotting wire
or by scooping it with a soldering iron.

If the amount of solder on the preliminary solder side is small,
additional soldering is performed, and if it is a mountain,
apply flux from above and heat it to clean it.

tips_building_smd_04

</details>

The diode is completed by soldering 42 pieces in total on the left and right.

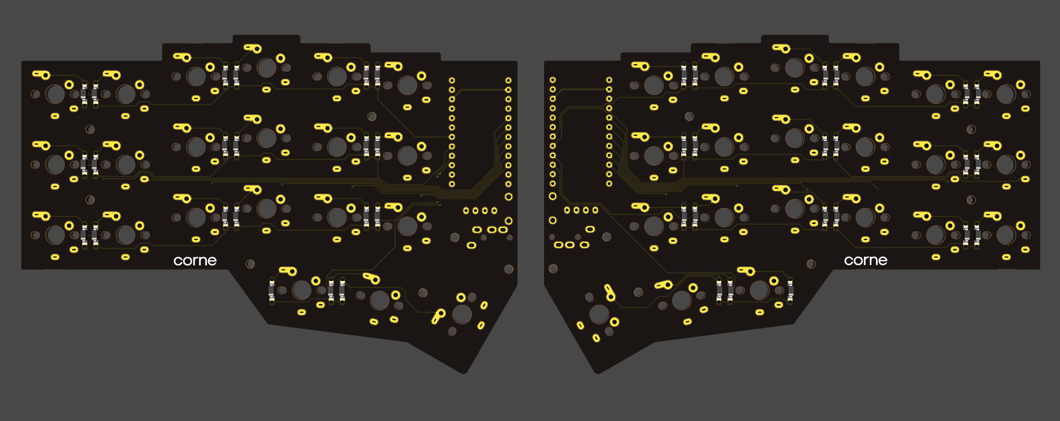
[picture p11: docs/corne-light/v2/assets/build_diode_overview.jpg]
build_diode_overview


### TRRS jack, reset switch, pin socket for OLED

Solder the TRRS jack, reset switch (tact switch),
and OLED pin socket as shown in the picture below.

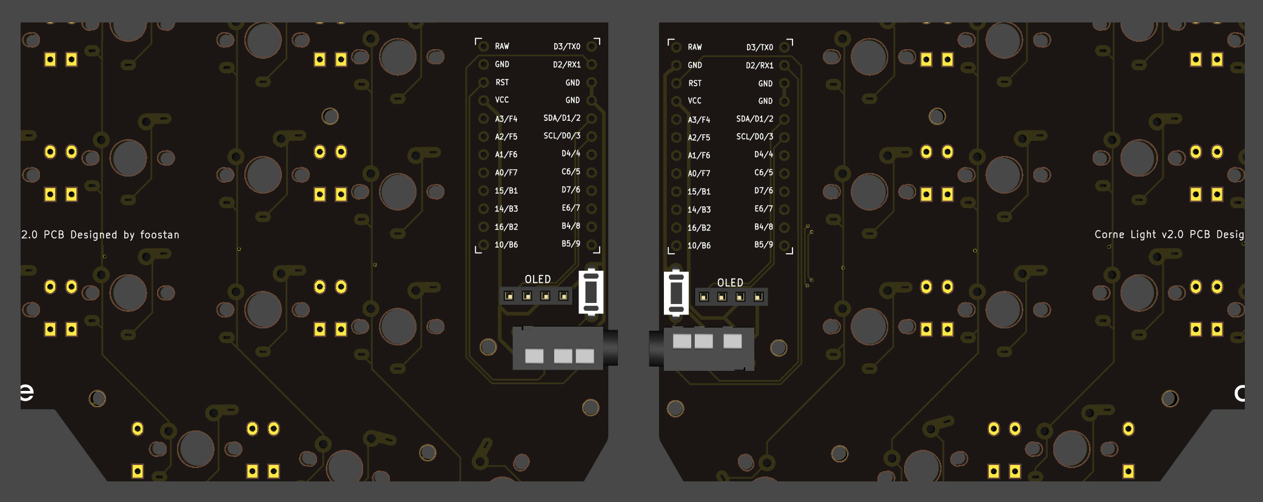
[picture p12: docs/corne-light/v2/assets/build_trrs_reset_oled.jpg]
build_trrs_reset_oled


Since it is a part that easily slips off,
you can solder it while holding the part by hand,
or fix it with masking tape and then solder it.

### ProMicro

Solder ProMicro in the following orientation

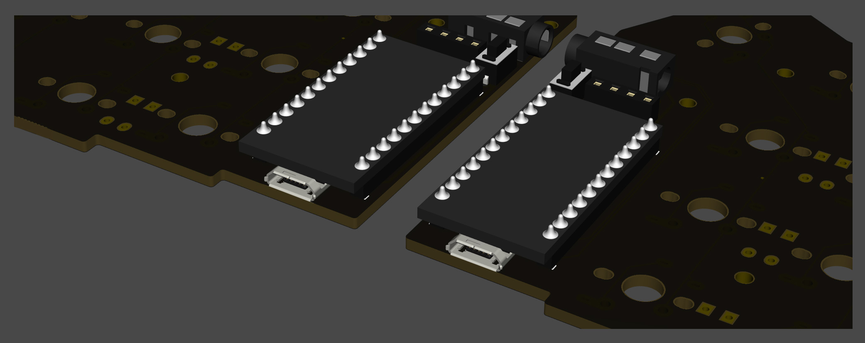
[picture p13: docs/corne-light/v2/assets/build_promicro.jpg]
build_promicro


If you use spring-loaded pin headers (e.g. Conthrough),
you do not need to solder the back side.
Please refer to the [Helix Build Guide](
https://github.com/MakotoKurauchi/helix/blob/master/Doc/buildguide_en.md#pro-micro)
for details on how to use spring-loaded pin headers.

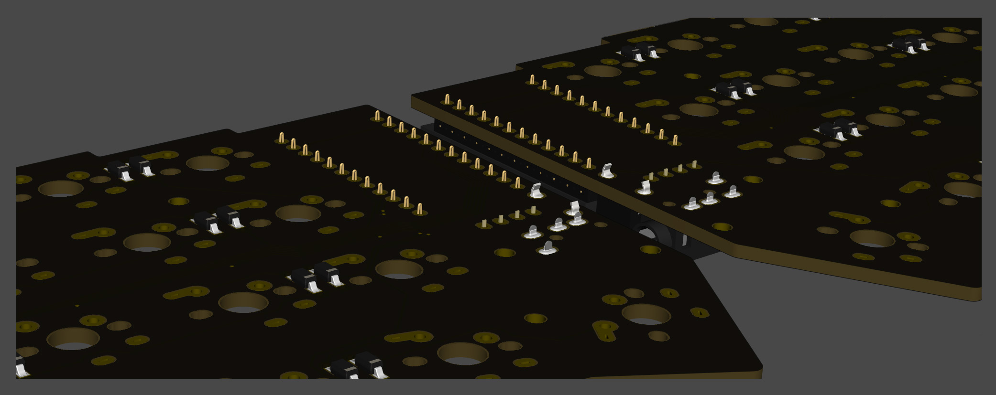
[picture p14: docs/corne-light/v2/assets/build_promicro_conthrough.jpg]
build_promicro_conthrough


### OLED module

Insert the pin header into the pin socket for OLED first,
and then solder the pin header and OLED module.
At this time, the OLED module is easy to float,
so be careful not to float it while pressing it with your finger.

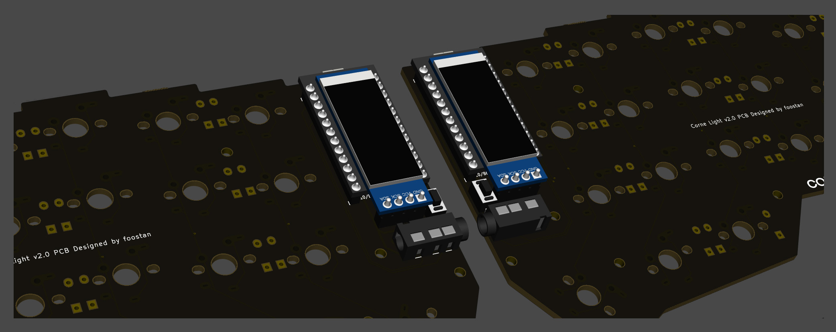
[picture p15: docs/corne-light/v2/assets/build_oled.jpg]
build_oled


### Firmware

Write the firmware to ProMicro by referring to the following. \
[docs/firmware/rev1](../../firmware/rev1/firmware_en.md)

### Operation check

We recommend that you check the operation when the ProMicro and OLED module are attached.
If you do it at the very end, it will be difficult to isolate the problem.

To check the operation,
connect the left hand side to the PC with MicroUSB,
and connect the left hand side and the right hand side with the TRRS cable.
Since there may be defects such as jacks,
be sure to connect the left and right instead of one by one
before checking the operation.
If it is done correctly so far,
if you short the pad to attach the PCB socket with tweezers etc.,
the key pressed on the OLED module will be displayed.

### Top plate, switch

After attaching the key switch to the top plate, solder the key switch.
If you attach all the key switches to the top plate first,
it will be more difficult to attach the switches to the board,
so it is easier to attach only the end key switches first.
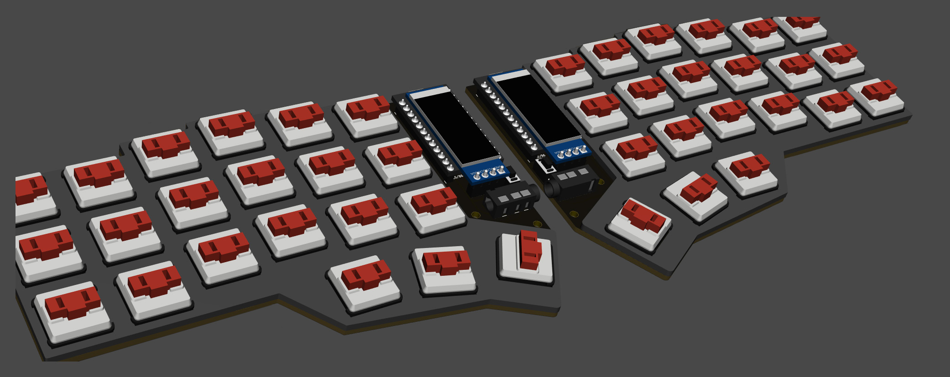
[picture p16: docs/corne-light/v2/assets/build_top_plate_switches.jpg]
build_top_plate_switches


### OLED protective plate

Attach the OLED protective plate with M2 9mm spacers and M2 screws.

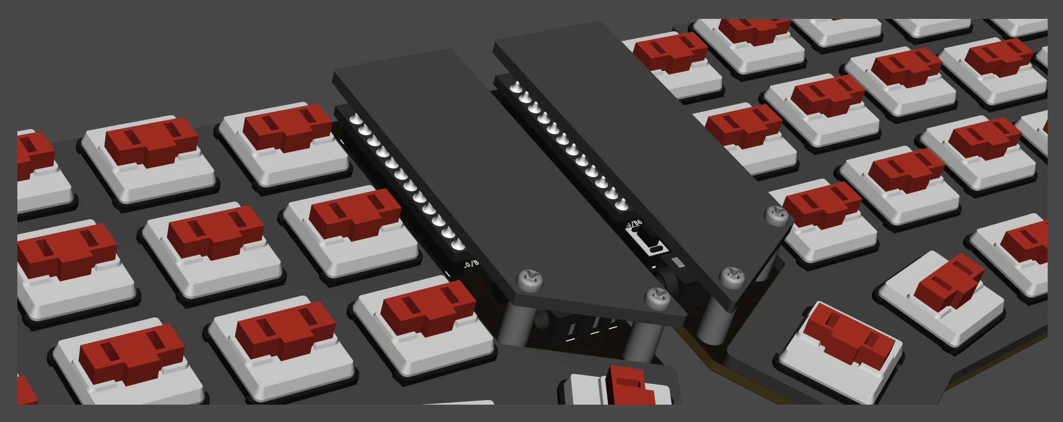
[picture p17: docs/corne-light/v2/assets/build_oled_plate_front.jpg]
build_oled_plate_front

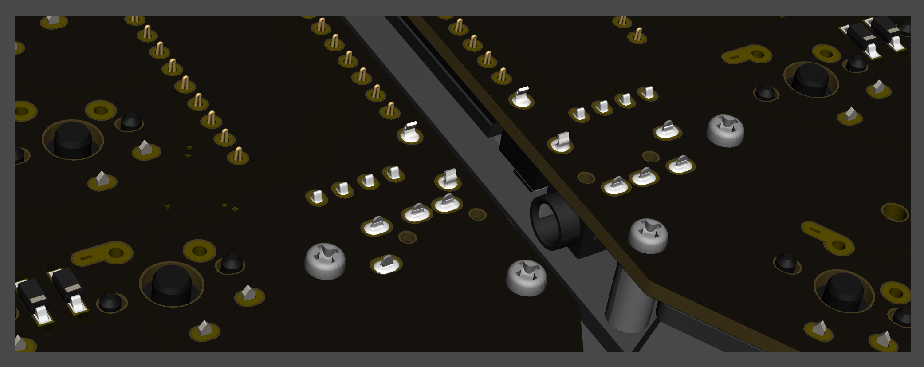
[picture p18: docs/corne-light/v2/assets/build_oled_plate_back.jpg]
build_oled_plate_back


Especially for the screws on the back side,
tighten them firmly to attach the bottom foam after this.

### Bottom form

Finally, paste the bottom form.
This foam has an adhesive surface on one side
and a non-slip surface on the other side.
Stick the adhesive side firmly to the PCB.

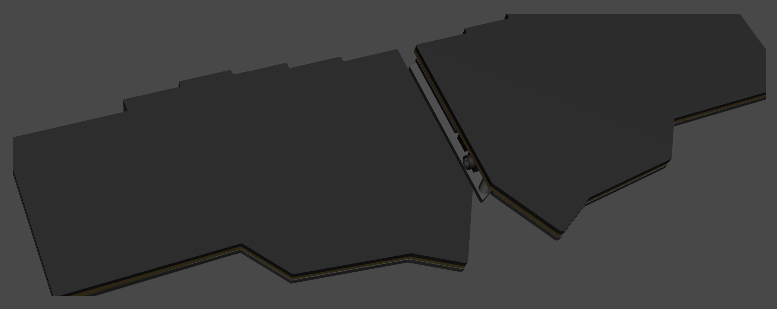
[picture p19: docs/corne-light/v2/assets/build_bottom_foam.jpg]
build_bottom_foam


That's it.

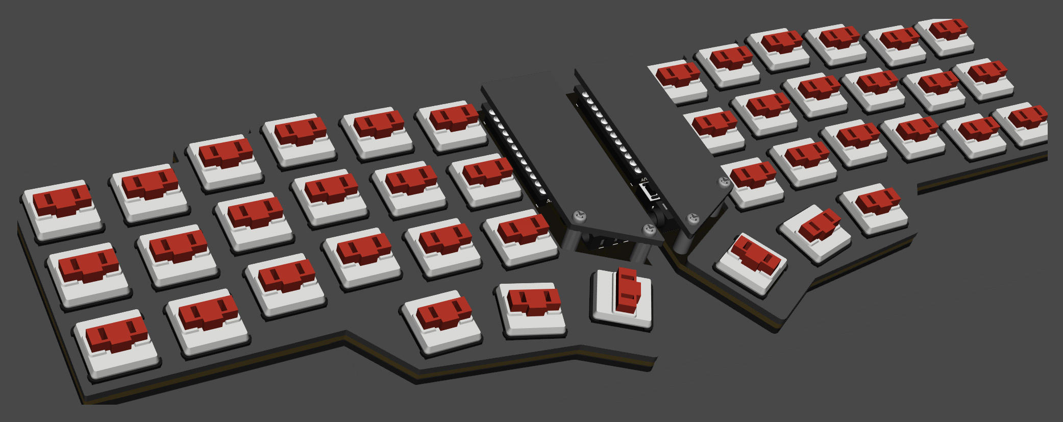
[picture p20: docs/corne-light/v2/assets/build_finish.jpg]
build_finish


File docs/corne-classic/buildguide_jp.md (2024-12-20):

# Build Guide

## 部品

### 必須

| 名前 | 数 | 備考 |
|:-|:-|:-|
| PCB | 2枚 | |
| プレート | 2セット | |
| ProMicro | 2枚 | |
| TRRSジャック | 2個 | |
| TRS(3極)ケーブル | 1本 | TRRS(4極)ケーブルでも可 |
| タクトスイッチ | 2個 | |
| ダイオード | 42本 | ロープロの場合は表面実装のみ可 |
| キースイッチ | 42個 | |
| キーキャップ | 42個 | 1u 40個、1.5u 2個 |
| スペーサー M2 7.5mm | 10本 | ロープロの場合は 4.5mm |
| スペーサー M2 9mm or 11mm | 4本 | |
| ネジ M2 | 28本 | |
| クッションゴム | 10個 | |

### オプション

| 名前 | 数 | 備考 |
|:-|:-|:-|
| OLEDモジュール | 1 ~ 2枚 | |
| ピンヘッダ 4連 | 2つ | OLEDモジュールを使用する場合 |
| ピンソケット4連 | 2つ | OLEDモジュールを使用する場合 |
| SK6812MINI | 54個 | 上向き実装 42個、下向き実装 12個 |
| シリアルLEDテープ | 2本 | SK6812MINI との併用は想定していません |



## 事前準備

ファームウェアを自分でビルドする場合は環境を整備するのに時間がかかるのではじめに取り掛かっておくことをおすすめします。\
詳しくは [docs/firmware/rev1](../firmware/rev1/firmware_jp.md) を参照してください。

## 実装

PCBはリバーシブルになっているので、最初にどちらを左用/右用にするか決めます。

### ダイオード

#### ロープロファイルのキースイッチを使わない場合

写真の位置にダイオードを実装します。
どちらの面に実装するかは好みですが、Undergrow LEDを実装する場合は、干渉をさけるため表面に実装することをおすすめします。
なお、ロープロファイルのキースイッチを使う場合と同様に表面実装タイプを利用しても問題ありません。



ダイオードには向きがあるので注意してください。

<- 実装前 | 実装後 ->



#### ロープロファイルのキースイッチを使う場合

ロープロファイルスイッチを利用する場合は、表面実装タイプのダイオードを利用し、必ず __裏面に実装してください__ 。表面に実装してしまうとトッププレートがダイオードと干渉してしまいます。

### LED(オプション)

キースイッチ裏のLED(7 ~ 27)は表面側が光るように実装し、その他(1 ~ 6)は裏面側が光るようにします。
下記がLEDを実装する位置です。



下記のように __裏面から各LEDを実装します__ 。○印を基準としLEDの向きに注意して実装してください。



1 ~ 6のLEDは側面のわずかに出ているパターン(写真上のピンク色)とPCBのパターン(写真上の青色)をはんだ付けします。
フラックスを塗った上で少量のはんだを半田ごてで取ってパターンの境目に押し付けるとうまくいきます。



LEDの点灯チェックを行う場合は、上記写真の番号どおりにつながっているため、途中までしか点灯しない場合は点灯しないLEDか、その一つ手前のLEDの実装ミスの可能性が高いので確認してみてください。

### OLEDモジュールのためのジャンパ(オプション)

OLEDモジュールを利用する場合は下記のようにジャンパします。
なお __表面のみジャンパしてください__ 。



### TRRSジャック、リセットスイッチ、OLEDピンソケット(オプション)

下記の写真通りにTRRSジャック、リセットスイッチを実装します。
またOLEDモジュールを使用する場合は、ピンソケットを実装します。



### ProMicro

ピンヘッダを白い枠に当てはめるように実装し、そこにProMicroの裏面を上にして実装します。
なお下記の写真は右手用ですが、左手用も同様に白枠にピンヘッダを実装し、ProMicroの裏面を上にして実装します。



### OLEDモジュール

OLEDモジュールにピンヘッダを実装し、ピンソケットに差し込みます。



ピンソケットとピンヘッダの高さによって利用するスペーサーの高さを調節してください。
写真では電子部品店で入手可能な一般的なピンソケットとピンヘッダと11mmのスペーサーを利用した例となります。

### ProMicroのソケット化

ProMicroをソケット化をすることでProMicroが故障してしまった場合に容易に取り替えが可能になります。
2パターンのソケット化を紹介します。

#### スプリングヘッダを利用したソケット化

ソケット化を可能とする特殊なピンヘッダを利用する方法です。
利用方法はHelixのビルドガイドを参考にしてください。
<https://github.com/MakotoKurauchi/helix/blob/master/Doc/buildguide_jp.md#pro-micro>

スプリングヘッダとProMicroのセットは遊舎工房にて購入することが可能です。

<https://yushakobo.jp/shop/promicro-spring-pinheader/>

同じく遊舎工房で購入可能なOLEDについてくるピンヘッダを利用すると以下のように隙間なくきれいに収まります。また9mmのスペーサーを利用することができるのでより薄い仕上がりとなります。



#### ピンソケットを利用したソケット化

秋月電子等で購入可能な背の低いピンソケットを利用した方法です。
多少の工作が必要となります。

<http://akizukidenshi.com/catalog/g/gC-03138/>

12個連結ピンソケット2つ用意し、ブレッドボード等に固定します。



ProMicroに付属しているピンヘッダProMicroを挟むようにして上からしっかりと差し込みます。



ピンヘッダとProMicroをはんだ付けした後に余分なピンヘッダを切り取れば完了です。



#### 比較

下記はスプリングヘッダを利用した場合とピンソケットを利用した場合の比較になります。
スプリングヘッダを利用したほうが高さを抑えることができます。



下記はOLEDに利用するピンヘッダの比較となります。遊舎工房で購入可能なOLEDは左のように若干低くなっています。



### 動作確認

キースイッチを付けると何か問題があった場合に修正が難しくなるため、ProMicroとOLEDモジュールを付けた段階で動作確認をすることをおすすめします。

動作確認をする場合は先に下記の「ファームウェア」の章を参考にしてcrkbd用のファームウェアをProMicroに入れてください。



デフォルトのキーマップを適用するとOLEDに押したキーに関する情報が表示されます。ピンセット等でスイッチ部分をショートさせることで動作確認ができます。

LEDを実装した場合はすべて点灯することを確認します。



### キースイッチおよびトッププレート

キースイッチとPCBの間にトッププレートを挟んで表面に実装します。



### ボトムプレート

ロープロの場合は4.5mmのスペーサー、それ以外は7.5mmのスペーサーを取り付けたあとにボトムプレートを取り付けます。
またクッションゴムを6つ付けます。



### キーキャップ

最後にキーキャップを付けて実装は完了です。

lrg_dsc03895

## ファームウェア

下記を参照しファームウェアをProMicroに書き込みます。\
[docs/firmware/rev1](../../firmware/rev1/firmware_jp.md)

以上で完成です。

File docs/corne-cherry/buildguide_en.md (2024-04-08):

# Build Guide

This is the Corne Cherry build guide.
The build guide differs depending on the version of your board,
so please choose your own from the following.

- [v2 build guide](https://github.com/foostan/crkbd/blob/main/docs/corne-cherry/v2/buildguide_en.md)
- [v3 build guide](https://github.com/foostan/crkbd/blob/main/docs/corne-cherry/v3/buildguide_en.md)
- [v4 build guide](https://github.com/foostan/crkbd/blob/main/docs/corne-cherry/v4/buildguide_en.md)

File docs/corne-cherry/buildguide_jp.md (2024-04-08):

# Build Guide

こちらは Corne Cherry のビルドガイドになります。
バージョンによってビルドガイドは異なりますので、以下よりご自身のものをお選びください。

- [v2 のビルドガイドはこちら](https://github.com/foostan/crkbd/blob/main/docs/corne-cherry/v2/buildguide_jp.md)
- [v3 のビルドガイドはこちら](https://github.com/foostan/crkbd/blob/main/docs/corne-cherry/v3/buildguide_jp.md)
- [v4 のビルドガイドはこちら](https://github.com/foostan/crkbd/blob/main/docs/corne-cherry/v4/buildguide_jp.md)

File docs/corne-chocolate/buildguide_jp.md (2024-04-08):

# Build Guide

こちらは Corne Chocolate のビルドガイドになります。
バージョンによってビルドガイドは異なりますので、以下よりご自身のものをお選びください。

- [v2 のビルドガイドはこちら](https://github.com/foostan/crkbd/blob/main/docs/corne-chocolate/v2/buildguide_jp.md)
- [v4 のビルドガイドはこちら](https://github.com/foostan/crkbd/blob/main/docs/corne-chocolate/v4/buildguide_jp.md)

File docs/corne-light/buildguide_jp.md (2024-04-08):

# Build Guide

こちらは Corne Light のビルドガイドになります。
バージョンによってビルドガイドは異なりますので、以下よりご自身のものをお選びください。

- [v1 のビルドガイドはこちら](https://github.com/foostan/crkbd/blob/main/docs/corne-light/v1/buildguide_jp.md)
- [v2 low-edition のビルドガイドはこちら](https://github.com/foostan/crkbd/blob/main/docs/corne-light/v2/buildguide_low_edition_jp.md)

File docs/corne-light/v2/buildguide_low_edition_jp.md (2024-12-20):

# Build Guide

こちらは Corne Light v2 Low edition のビルドガイドになります。

corne-light-low-edition-001
corne-light-low-edition-002
corne-light-low-edition-003

## 部品

### 必須

| 名前 | 数 | 備考 |
|:-|:-|:-|
| PCB | 1セット | |
| トッププレート(アクリル) 2mm | 2枚 | |
| ボトムフォーム | 2枚 | 特殊なフォームを専用の型で切り出しています |
| OLED保護プレート | 2枚 | |
| ProMicro | 2枚 | |
| TRRSジャック | 2個 | |
| タクトスイッチ | 2個 | |
| ダイオード | 42本 | SMD部品推奨 |
| キースイッチ | 42個 | Kailh Choc v1 or v2 推奨 |
| キーキャップ | 42個 | 1u 40個、1.5u 2個 |
| スペーサー M2 9mm | 4本 | |
| ネジ M2 4mm | 8本 | |
| TRRS(4極)ケーブル | 1本 | TRS(3極)ケーブルでも可 |
| Micro USBケーブル | 1本 | |

### オプション

| 名前 | 数 | 備考 |
|:-|:-|:-|
| OLEDモジュール | 2枚 | |
| OLEDモジュール用ピンヘッダ 4連 1.5mm | 2つ | |
| OLEDモジュール用ピンソケット 4連 2.5mm | 2つ | |

## 事前準備

ファームウェアを自分でビルドする場合は環境を整備するのに時間がかかるのではじめに取り掛かっておくことをおすすめします。\
詳しくは [docs/firmware/rev1](../../firmware/rev1/firmware_jp.md) を参照してください。

## 確認

Corne Light v2 のPCBは以下のものになります。お手持ちのPCBと同一のものかご確認ください。

confirm_front

confirm_back

PCBは製造の都合上フレームが付いた状態となっています。
手で折って外すことができますが、難しい場合は接合部分※にカッター等で切り込みを入れると外しやすくなります。
また、接合部分はヤスリ等できれいにすることができます。

※ 接合部分: 下記画像の赤で記した部分のこと、計8箇所あります

confirm_remove_frame

## 組み立て

### ダイオード

SMD部品のダイオードのはんだづけを行います。
SMD部品は非常に小さいためピンセット及び逆作用ピンセットがあると便利です。

**ダイオードは取り付ける向きが決まっていて**、部品の「|」印が、ダイオードマーク「|◁」の「|」の方に向けるようにはんだづけを行います。
なお、Corne の PCB はダイオードの取り付け向きがすべて統一されています。

build_diode

<details>
<summary>TIPS: SMD部品を取り付けるコツ</summary>

SMD部品を取り付けるコツですが、まずは予備ハンダとしてパットの片側のみにハンダを盛ります。

tips_building_smd_01

次に予備ハンダを溶かすようにしてダイオードの片足をはんだ付けします。
このとき、逆作用ピンセットを利用すると力を入れずともチップ部品をしっかりと持つことができ、位置合わせとはんだづけに集中できるのでおすすめです。
またはんだごてがあつすぎたり、はんだを触りすぎたりするとはんだに含まれるフラックスが気化してきれいにはんだの山ができることがありますが、あとで修復できるのでこの時点ではパーツを付けることだけを意識すれば大丈夫です。

tips_building_smd_02

片足をつけた段階で横から見てダイオードが浮いていなければ大丈夫です。浮いてしまった場合はダイオードをピンセットや指で押さえつけながらはんだごてではんだづけした部分を再度熱すればきれいになります。

tips_building_smd_03

次にもう片方をはんだづけします。少量のはんだで十分なのでつけすぎに注意します。
つけすぎてしまった場合は吸い取り線で取るか、はんだごてですくうようにすれば取れます。

また予備はんだ側のはんだの量が少ない場合は追加ではんだづけを重ねて行い、山になっている場合はフラックスを上から塗って熱すればきれいになります。

tips_building_smd_04

</details>

左右合わせて42個をはんだづけしてダイオードは完了です。

build_diode_overview

### TRRSジャック、リセットスイッチ、OLED用ピンソケット

下記の写真通りにTRRSジャック、リセットスイッチ(タクトスイッチ)、OLED用ピンソケットをはんだづけします。

build_trrs_reset_oled

ずれやすい部品なので、手で部品を抑えながらはんだづけするか、マスキングテープ等で固定してからはんだづけするときれいに付きます。

### ProMicro

ProMicroを下記のような向きではんだ付けします

build_promicro

なお、コンスルーを利用する場合は裏側のはんだ付けをする必要はありません。
コンスルーの詳しい利用方法は [Helix のビルドガイド](https://github.com/MakotoKurauchi/helix/blob/master/Doc/buildguide_jp.md#pro-micro)をご参照ください。

build_promicro_conthrough

### OLEDモジュール

OLED用のピンソケットにピンヘッダを先に差し込み、その後からピンヘッダとOLEDモジュールをはんだづけします。
このときOLEDモジュールが浮きやすいので指で押さえつけながら浮かないように気をつけます。

build_oled

### ファームウェア

下記を参照しファームウェアをProMicroに書き込みます。\
[docs/firmware/rev1](../../firmware/rev1/firmware_jp.md)

### 動作確認

ProMicroとOLEDモジュールを付けた段階で動作確認をすることをおすすめします。
一番最後にやると問題の切り分けが難しくなります。

動作確認は左手側はMicroUSBでPCとつなぎ、左手側と右手側をTRRSケーブルで接続させて行います。ジャック等の不良等もありえるので、片方ずつではなく必ず左右を接続させてから動作確認をしてください。ここまで正しくできていれば、PCBソケットを取り付けるパットをピンセット等でショートさせるとOLEDモジュールに押されたキーが表示されます。

### トッププレート、スイッチ

トッププレートにキースイッチに取り付けた後、キースイッチをはんだ付けします。
先にすべてのキースイッチをトッププレートに取り付けてしまうと、スイッチを基板にはめる難易度が上がってしまうため、先に端のキースイッチのみを取り付ける方が簡単です。
build_top_plate_switches

### OLED保護プレート

M2 9mm のスペーサーと M2 ネジで OLED 保護プレートを取り付けます。

build_oled_plate_front
build_oled_plate_back

特に裏側のネジについては、このあとボトムフォームを貼り付けるためしっかりと締めてください。

### ボトムフォーム

最後にボトムフォームを貼り付けます。
このフォームは片側が粘着面、もう片側が滑り止め面になっています。
粘着面をPCBにしっかいと貼り付けてください。

build_bottom_foam

以上で完成です。

build_finish

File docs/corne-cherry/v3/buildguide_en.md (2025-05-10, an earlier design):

# Build Guide

This is the build guide for Corne Cherry v3.
[Click here for the Corne Cherry v2 build guide](
https://github.com/foostan/crkbd/blob/master/docs/corne-cherry/v2/buildguide_en.md).

## Parts

### Required

| Name | Count | Remarks |
|:-|:-|:-|
| PCB | 1 set | |
| Top plate | 2 sheets | 1.5mm-3mm thick |
| Bottom plate | 2 sheets | |
| OLED cover | 2 sheets | |
| ProMicro | 2 | Alternative: [Elite-C](https://deskthority.net/wiki/Elite-C) |
| TRRS jack | 2 | |
| Reset switch | 2 | |
| Diodes | 42 | SMD Only (SOD-123 Package) |
| PCB sockets | 42 | Compatible with Kailh and Gateron |
| Key switches | 42 | Only compatible with MX style |
| Keycaps | 42 pieces | 1u 40 pcs, 1.5u 2 pcs |
| Spacer M2 7.5mm | 10 pieces | For Case assembly |
| Spacer M2 9mm | 4 pieces | For OLED cover |
| Screw M2 4mm | 28 screws | |
| Rubber feet | 8 pieces | |
| TRRS (4 poles) cable | 1 | TRS (3 poles) cable is also compatible |
| Micro USB cable | 1 | Avoid charge-only cables |

### Optional

| Name | Count | Remarks |
|:-|:-|:-|
| OLED module | 2 | |
| SK6812MINI-E | 42 | LEDs for Backlight |
| WS2812B | 12 | LEDs for Underglow |
| [Microcontroller/OLED Sockets](https://www.digikey.com/en/products/detail/315-43-112-41-003000/ED4764-12-ND/4455232) | 1 | Alternative: [2.54 1row femal sliv](https://www.aliexpress.com/item/4001122376295.html) option |
| [Microcontroller Pins](https://www.digikey.com/en/products/detail/mill-max-manufacturing-corp/3320-0-00-15-00-00-03-0/4147392) | 48 | Alternative: Diode/Resistor legs |
| [OLED Headers](https://www.digikey.com/en/products/detail/mill-max-manufacturing-corp/350-10-164-00-006000/357045) | 1 | Soldered to OLED module |

## Firmware preparation

If you build the firmware yourself, it will take some time to set up the environment,
so it's best to start at the beginning.\
It is recommended to flash ProMicro's prior to soldering.\
For more information,
please see [docs/firmware/rev1](../../firmware/rev1/firmware_en.md).

## Verification

The PCB for Corne Cherry v3 is as follows.
Make sure it is the same as your PCB.

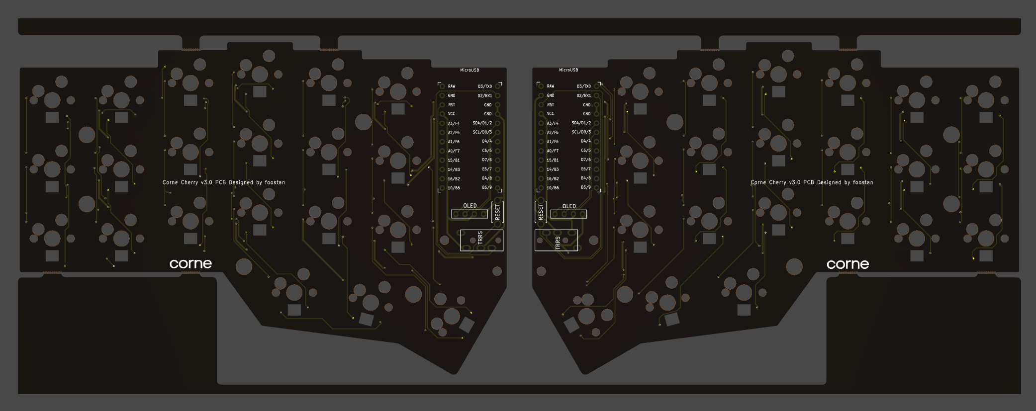
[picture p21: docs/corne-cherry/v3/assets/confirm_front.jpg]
confirm_front


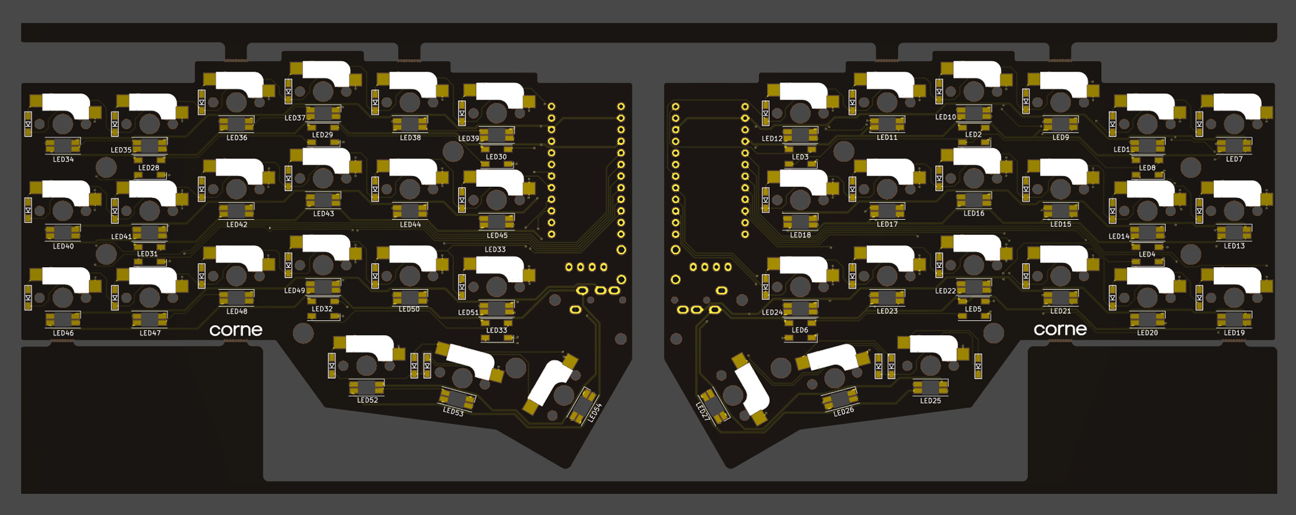
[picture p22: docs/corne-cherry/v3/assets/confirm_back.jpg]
confirm_back


The PCB comes with a frame for manufacturing reasons.
You can fold it by hand to remove it, but if it is difficult,
make a cut in the joint\* with a cutter or similar,
to make it easier to remove.
In addition, the joint can be cleaned with a file.

\**Joint part: There are a total of 8 parts,
which are marked in red in the image below.*

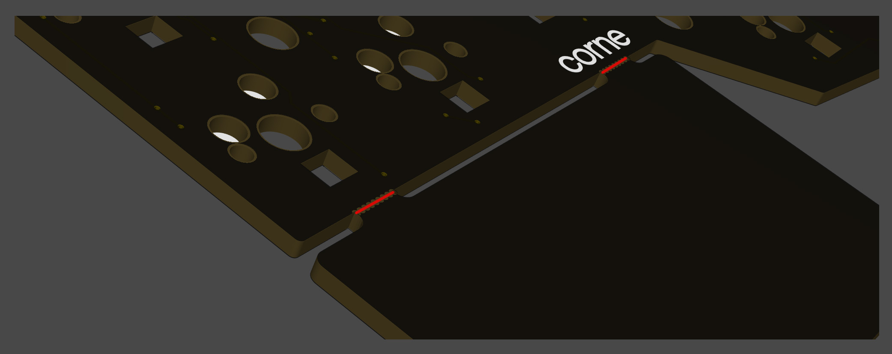
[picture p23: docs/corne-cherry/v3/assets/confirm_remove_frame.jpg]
confirm_remove_frame


## Assembly

### Diodes

Since SMD parts are very small, fine-tip/reverse-action tweezers are recommended.

**The diodes have a specific orientation**, so install with "|" marking on the diode
facing the "|" on the PCB marking: "|◁"

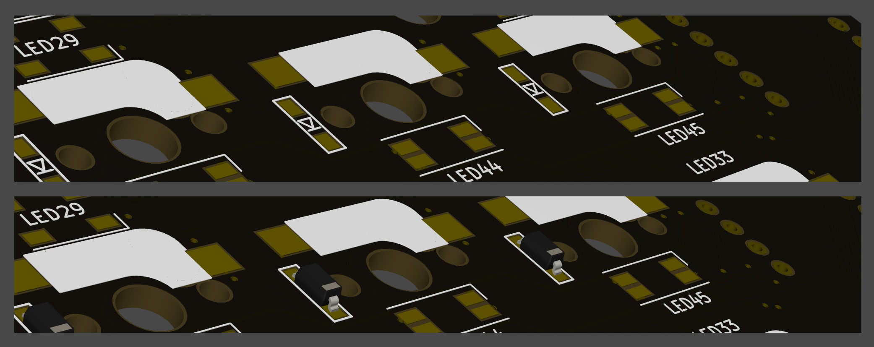
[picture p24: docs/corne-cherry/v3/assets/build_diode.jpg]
build_diode


<details>
<summary>TIPS: Tips for installing SMD parts</summary>

Begin with applying solder to only one pad.

tips_building_smd_01

Next, place SMD component while heating solder. At this time,
it is recommended to use [reverse-action tweezers](https://www.alimed.com/_resources/cache/images/product/70895A_850x480-pad.jpg),
so that you can hold the SMD part firmly without applying force,
and concentrate on alignment and soldering instead.
Also, if the soldering iron is too hot or the solder is touched too long,
the flux contained in the solder may evaporate and form a poor solder joint,
but it can be repaired later,
so at this point you should only care about attaching parts.
It's okay.

tips_building_smd_02

It is okay if the SMD component is not flush with the PCB when viewed from the side.
If it is floating, press the SMD component down with tweezers or your finger and reheat the solder.

tips_building_smd_03

Then solder the other contacts.
Be careful not to apply too much solder,
as a small amount is sufficient.
If you have applied too much,
you can remove it with a suction pump, solder wick,
or by picking it up with a soldering iron.

If the amount of solder on the preliminary solder side is small,
additional soldering is performed, and if it is a heap,
apply flux from above and heat it to clean it.

tips_building_smd_04

</details>

The diode is completed by soldering 42 pieces in total on the left and right.

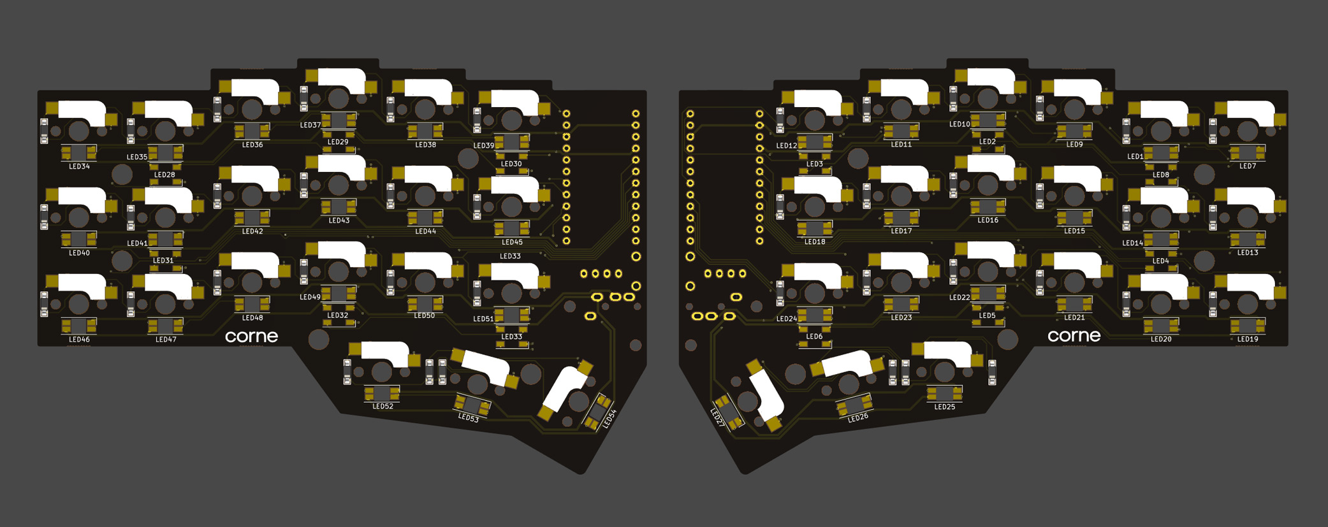
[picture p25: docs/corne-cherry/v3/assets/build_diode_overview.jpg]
build_diode_overview


### LED (optional)

Solder the SK6812MINI-E and WS2812B.

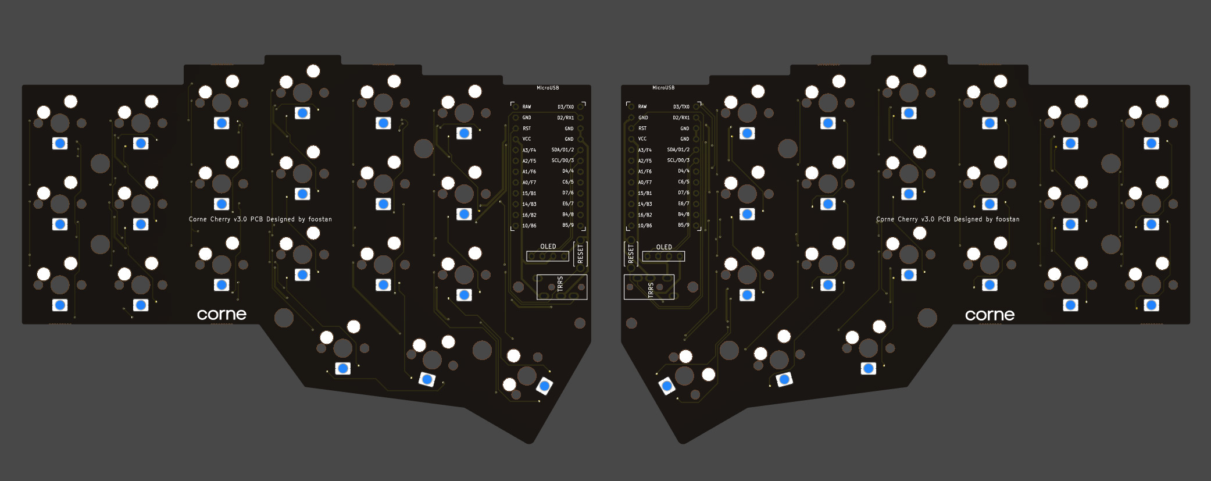
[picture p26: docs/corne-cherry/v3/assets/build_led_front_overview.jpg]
build_led_front_overview


All soldering is done from the back side, but the SK6812MINI-E is for Backlight
(the front side is shining) and the WS2812B is for Underglow (the back side is shining).

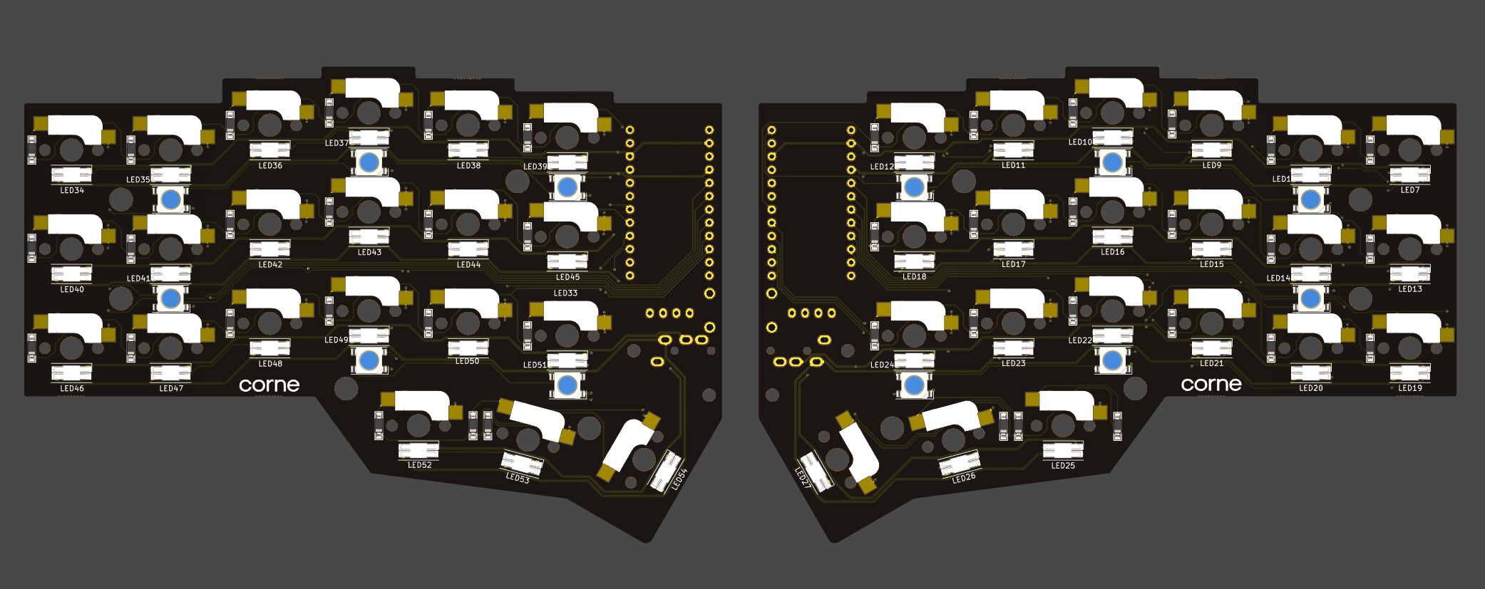
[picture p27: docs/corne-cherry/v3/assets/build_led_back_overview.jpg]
build_led_back_overview


#### WS2812B (Underglow)

First, solder the WS2812B.

Match recessed corner of the LED with marked corner on the PCB as shown below.
Refer to **TIPS: Tips for installing SMD parts** section above as similar soldering
procedure is followed. 

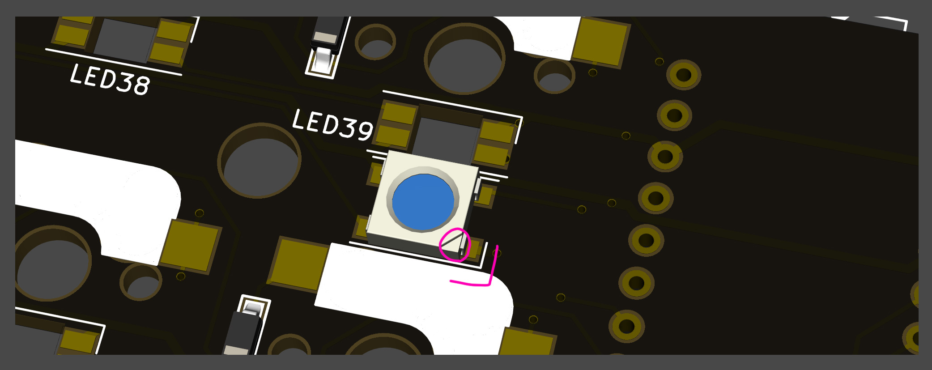
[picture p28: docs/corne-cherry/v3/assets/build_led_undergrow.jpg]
build_led_undergrow


WS2812B LED soldering is completed after 12 are installed on left and right.

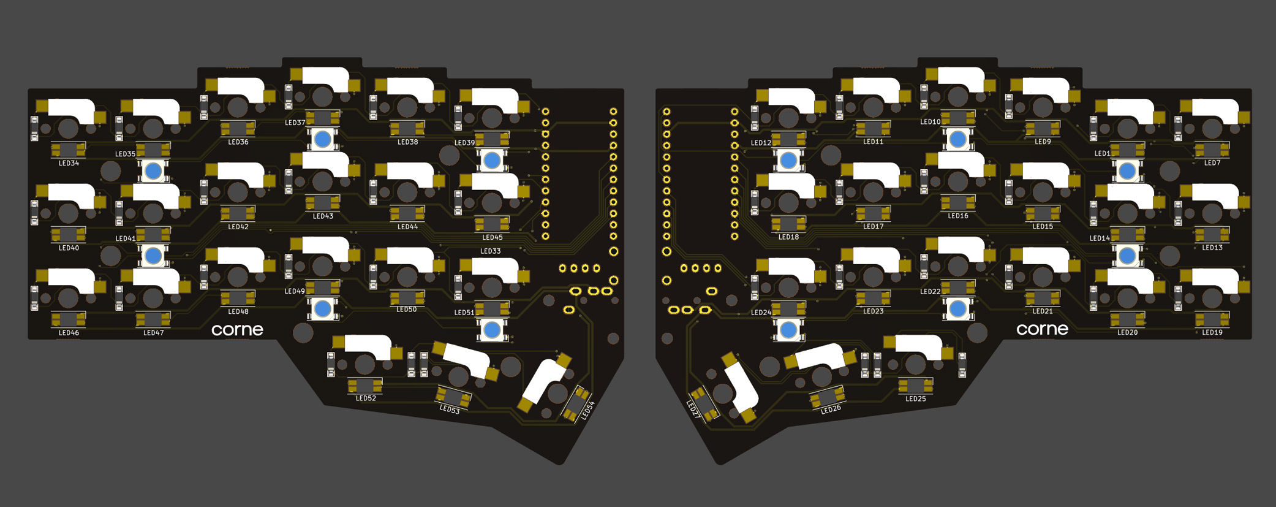
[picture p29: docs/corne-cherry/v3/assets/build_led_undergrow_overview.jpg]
build_led_undergrow_overview


#### SK6812MINI-E (Backlight)

Then solder the SK6812MINI-E.

Match the notched corner of the LED with the marked corner on the PCB as show below.
Refer to **TIPS: Tips for installing SMD parts** section above as similar soldering
procedure is followed. 
These are more resilient than the SK6812MINI LEDs,
but still may be damaged if directly exposed to the heat of a soldering iron.
~320°C seems to be an ok temperature, evne if all four legs are soldered 
one after another.

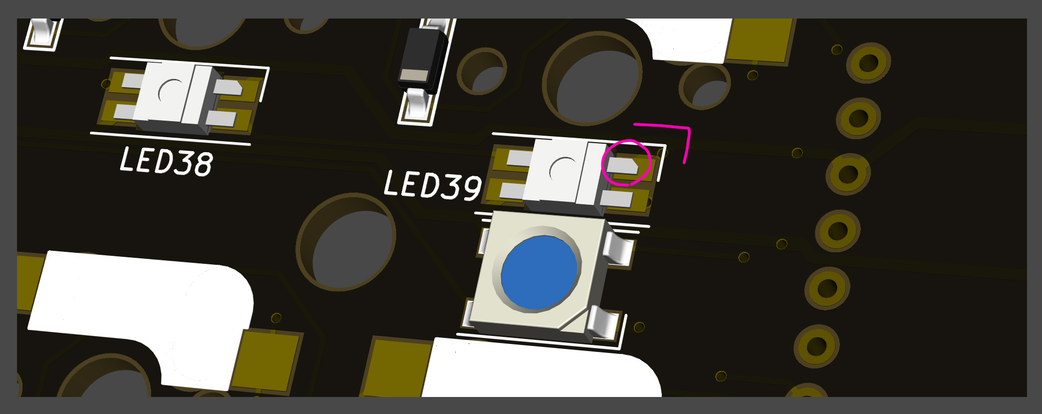
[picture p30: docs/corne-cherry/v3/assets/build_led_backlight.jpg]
build_led_backlight


SK6812MINI-E LED soldering is completed after 42 are installed on left and right.

build_led_back_overview

### TRRS jack, reset switch, pin socket for OLED

Solder the TRRS jack, reset switch (tact switch),
and OLED pin socket as shown in the picture below.

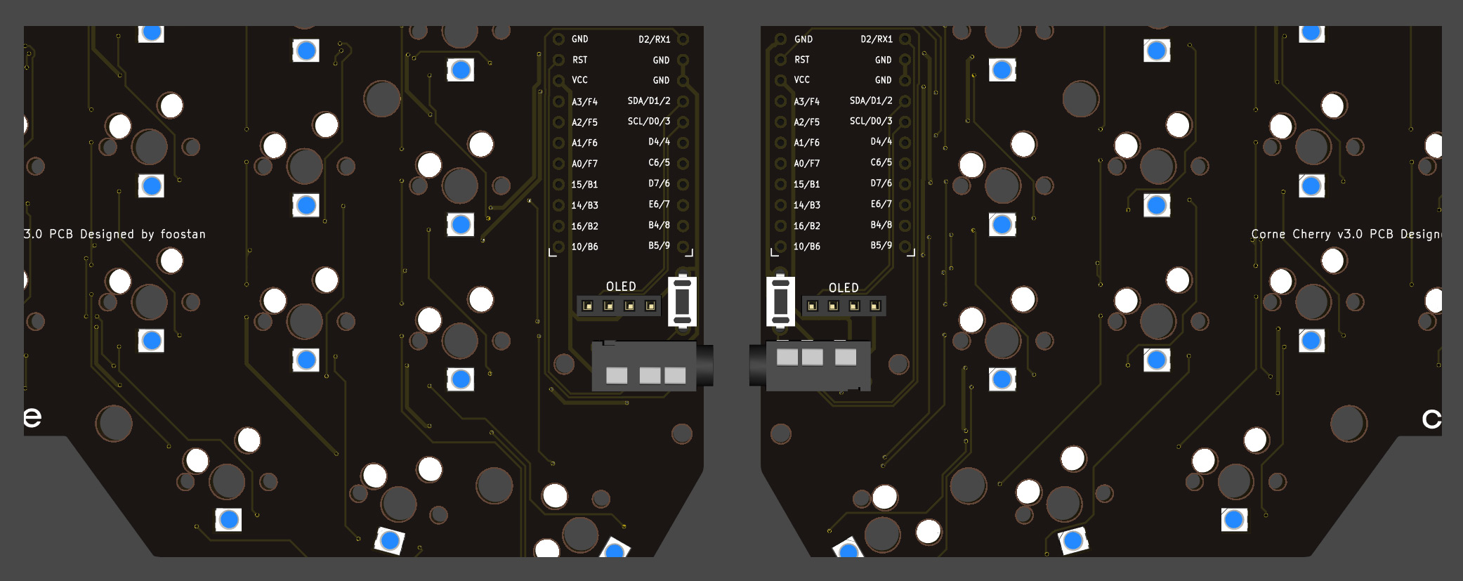
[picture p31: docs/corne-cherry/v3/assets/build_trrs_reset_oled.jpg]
build_trrs_reset_oled


Since these parts may fall off when soldering, you can affix them with masking tape.

### ProMicro

Solder headers to PCB. Then solder ProMicro to headers, with components facing PCB as shown below.

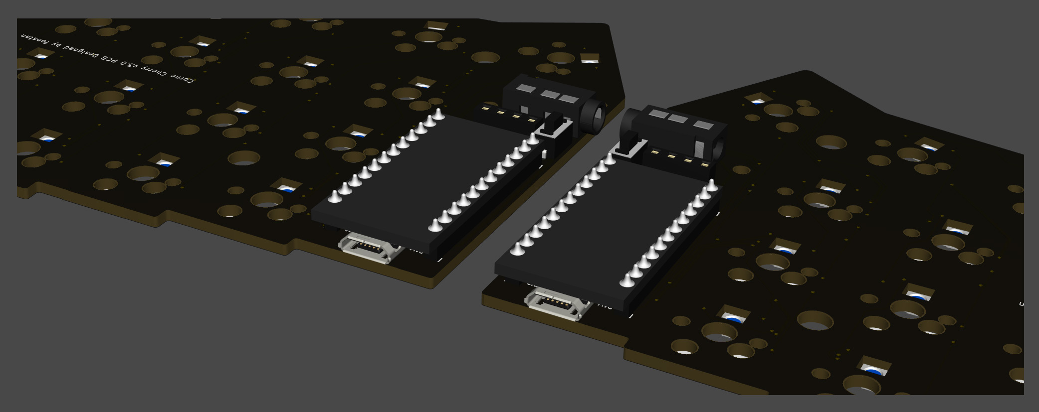
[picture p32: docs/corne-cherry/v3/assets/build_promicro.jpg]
build_promicro


If you use [spring-loaded pin headers](https://shop.yushakobo.jp/collections/all-keyboard-parts/products/31),
you do not need to solder the back side.
Please refer to the [Helix Build Guide](
https://github.com/MakotoKurauchi/helix/blob/master/Doc/buildguide_en.md#pro-micro)
for details on how to use spring-loaded pin headers.

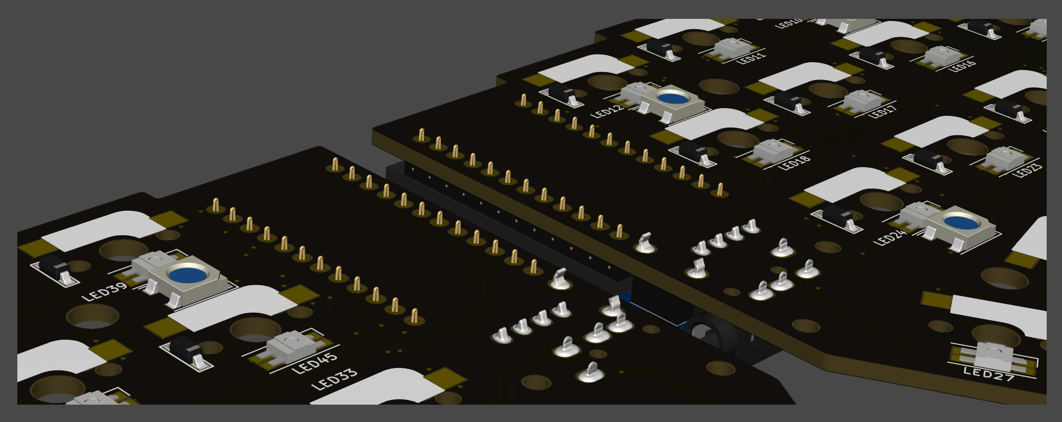
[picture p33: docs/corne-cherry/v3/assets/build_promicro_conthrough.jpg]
build_promicro_conthrough


### OLED module

Insert the pin header into the socket first, then solder the OLED module
to the pin header.
Note: Solder one pin to OLED module, then reheat solder to confirm OLED module is level,
then solder remaining pins.

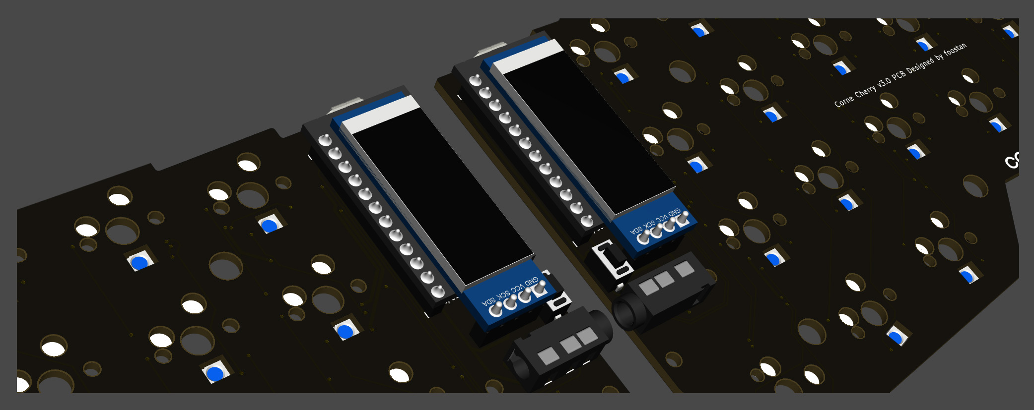
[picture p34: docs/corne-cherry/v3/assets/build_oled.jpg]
build_oled


### Operation check

Now is a good time to test your keyboard to help isolate potential problems.

To check the operation, connect left and right sides with TRRS cable,
then connect left side to the computer with USB cable.
If it is done correctly so far, shorting a hotswap socket pad with tweezers will 
output out a keypress and it will be displayed on the OLED module.

### Switch Sockets

Solder hotswap sockets according to mark on PCB as shown below.
Refer to **TIPS: Tips for installing SMD parts** section above as similar soldering
procedure is followed. 

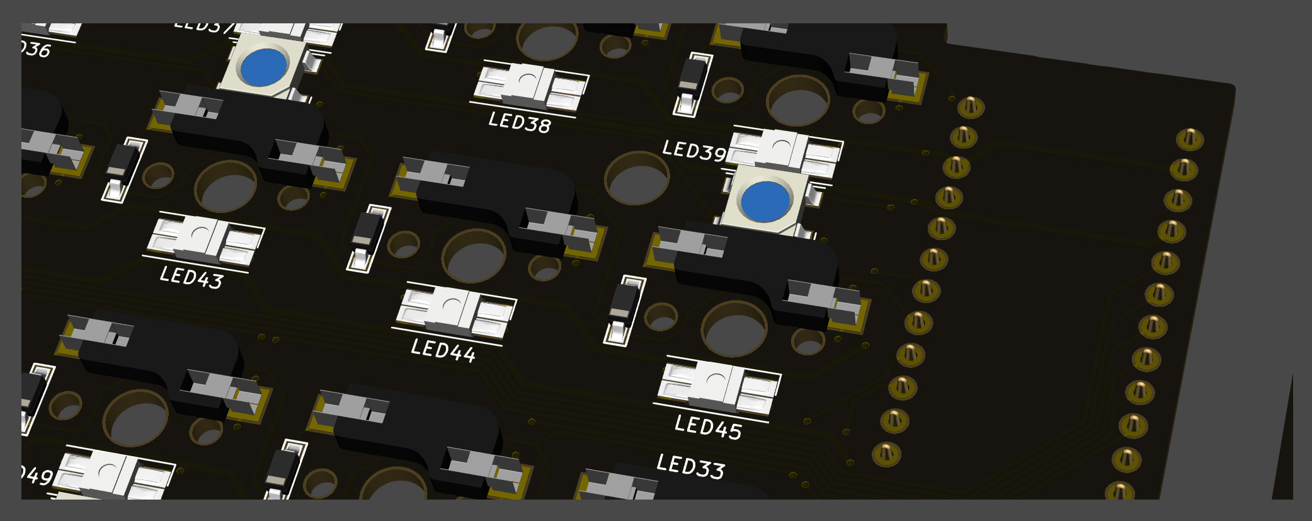
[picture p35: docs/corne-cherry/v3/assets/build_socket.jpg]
build_socket


Switch Socket soldering is completed after 42 are installed on left and right.

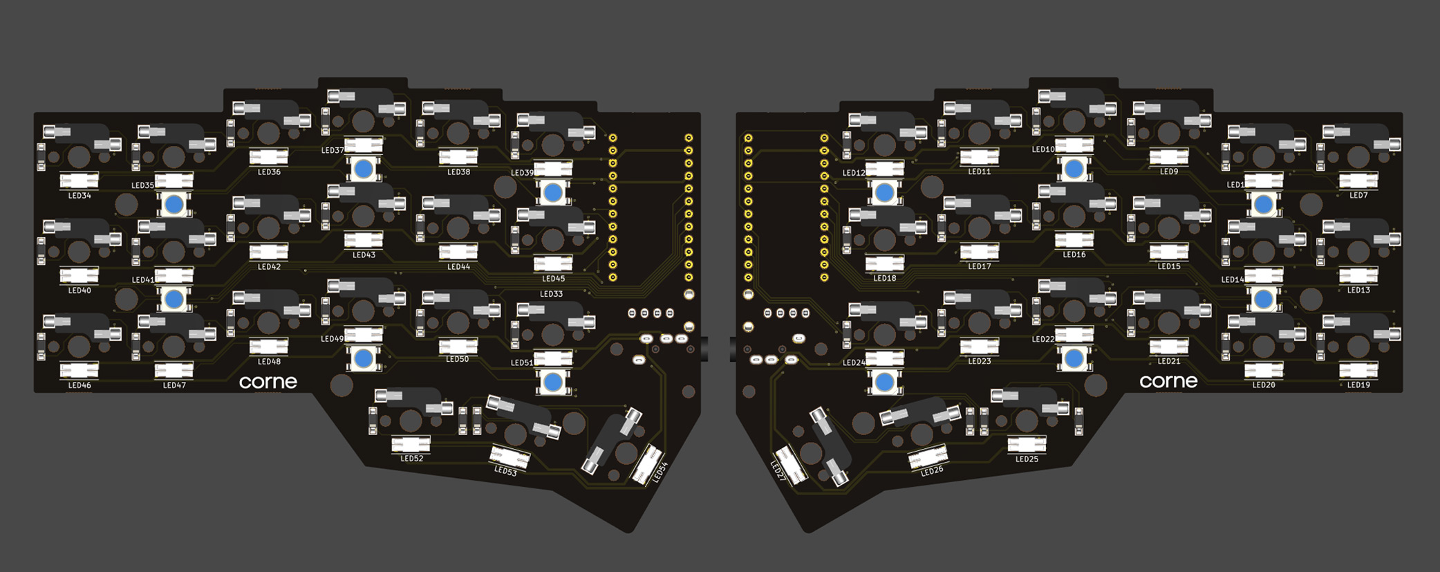
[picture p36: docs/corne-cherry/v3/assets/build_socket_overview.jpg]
build_socket_overview


### OLED protective cover

Attach the OLED protective cover with M2 9mm spacers and M2 screws.

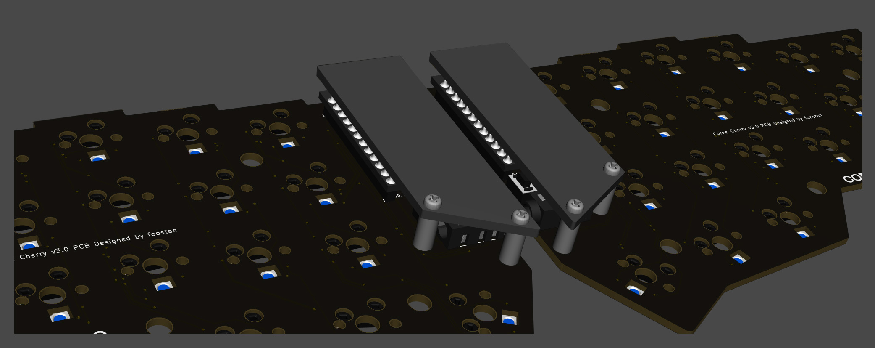
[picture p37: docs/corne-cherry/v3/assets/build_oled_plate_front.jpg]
build_oled_plate_front

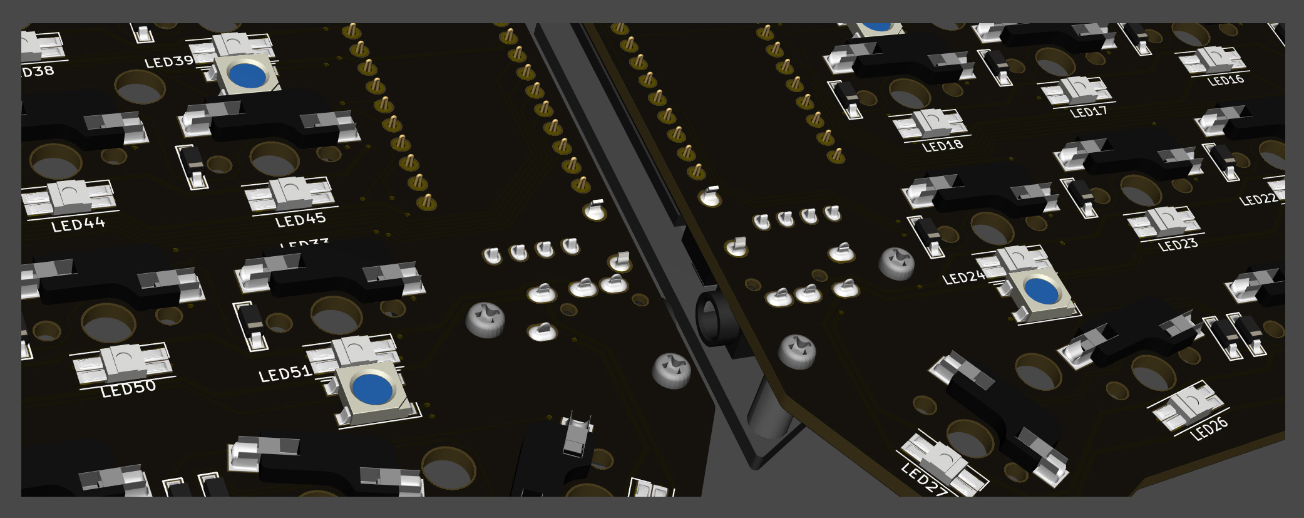
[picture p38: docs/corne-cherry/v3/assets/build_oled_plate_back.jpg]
build_oled_plate_back


### Plates & Switches

Place a few key switches into the top plate, then line up and press into PCB socket.
If you attach all the key switches to the top plate first,
it will be more difficult to fit them in the PCB sockets all at once.
So it is recommended to do a few to begin with. 

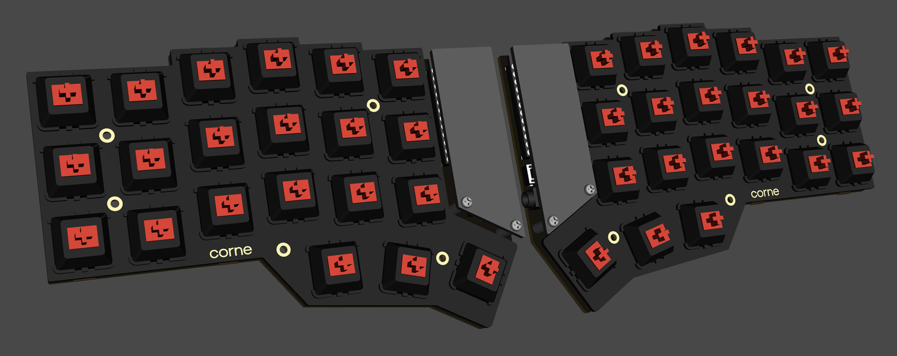
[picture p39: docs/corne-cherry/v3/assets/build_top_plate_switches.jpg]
build_top_plate_switches


Install the M2 7.5mm spacer and M2 screws on the top plate.

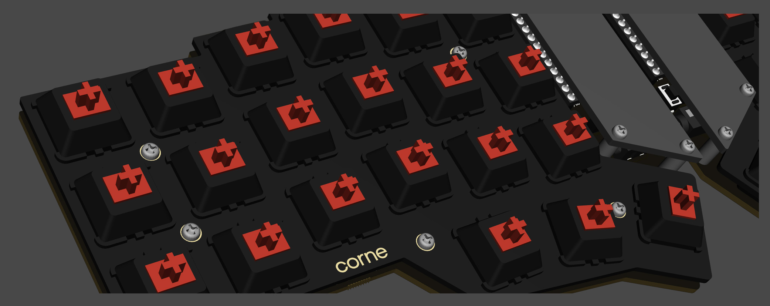
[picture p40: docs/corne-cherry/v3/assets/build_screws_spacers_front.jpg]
build_screws_spacers_front


It is easy to screw the spacer in after inserting it into the hole from the back side.

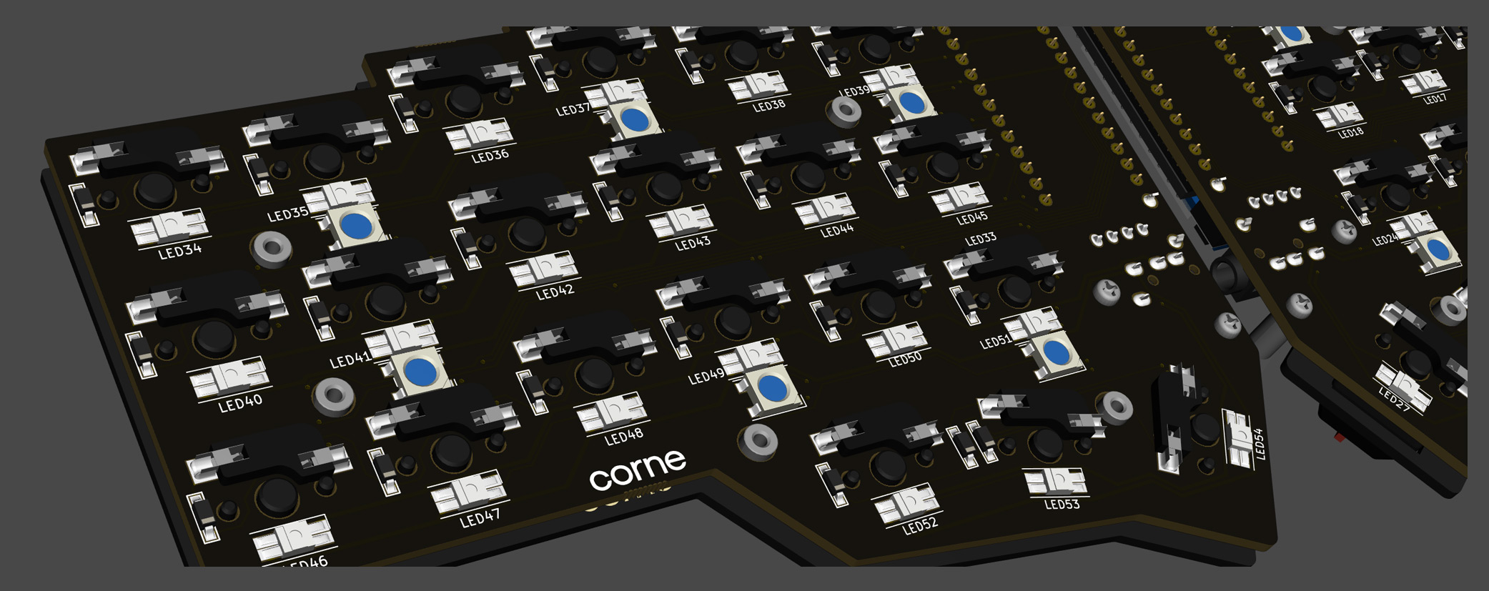
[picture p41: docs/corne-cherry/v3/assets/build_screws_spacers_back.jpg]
build_screws_spacers_back


Attach the bottom plate with M2 screws.

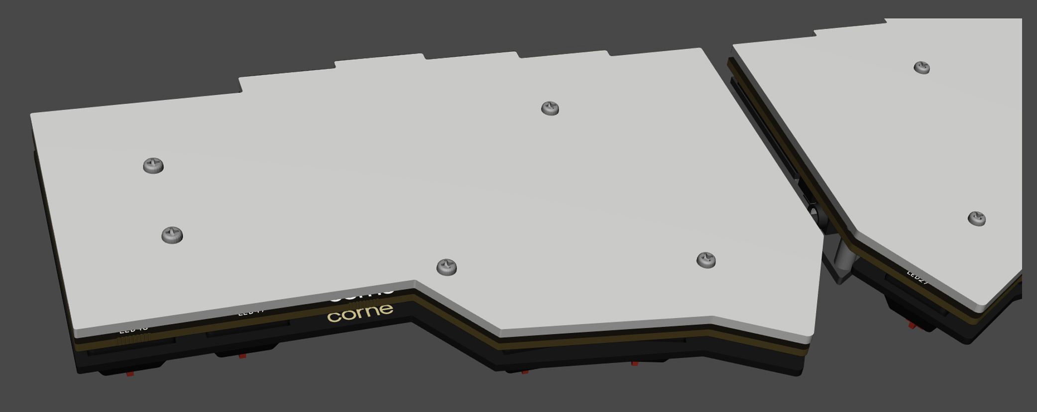
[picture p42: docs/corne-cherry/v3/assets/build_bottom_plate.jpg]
build_bottom_plate


Install the rubber feet in the following positions.

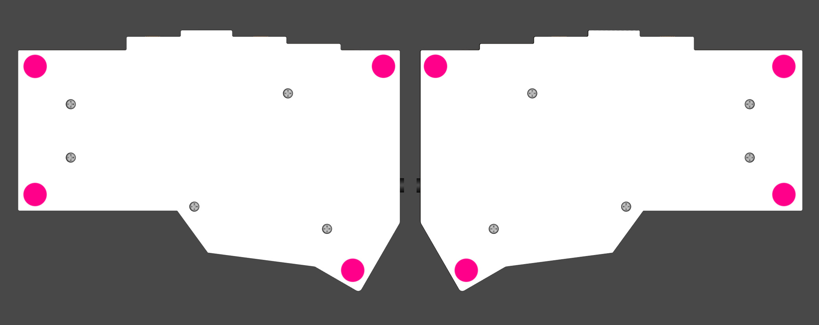
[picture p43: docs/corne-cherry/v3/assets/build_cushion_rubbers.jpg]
build_cushion_rubbers


That's it!

build_finish

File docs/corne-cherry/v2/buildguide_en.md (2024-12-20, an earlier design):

# Build Guide

This is the build guide for Corne Cherry v2.
[Click here for the Corne Cherry v3 build guide](
https://github.com/foostan/crkbd/blob/master/docs/corne-cherry/v3/buildguide_en.md).

## Parts

### Required

| Name | Count | Remarks |
|:-|:-|:-|
| PCB | 2 sheets | |
| Top plate | 2 sheets | |
| Bottom plate | 2 sheets | PCB type and acrylic type can be selected |
| ProMicro protective plate | 2 sheets | |
| ProMicro | 2 sheets | |
| TRRS jack | 2 | |
| Tact switch | 2 | |
| Diodes | 42 | Only chip parts |
| Kailh PCB Sockets | 42 | |
| Key switches | 42 | Only compatible with CherryMX |
| Keycaps | 42 pcs | 1u 40 pcs, 1.5u 2 pcs |
| OLED module | 2 sheets | |
| 4 pin headers | 2 | |
| 4 pin sockets | 2 | |
| Spacer M2 7.5mm | 10 pieces | |
| Spacer M2 9mm | 4 pieces | |
| Screw M2 4mm | 28 screws | |
| Cushion rubber | 8 pieces | |
| TRS (3-pole) cable | 1 | TRRS (4-pole) cable is also acceptable |
| Micro USB cable | 1 | |

### Optional

| Name | Count | Remarks |
|:-|:-|:-|
| SK6812MINI | 54 pcs | Upward mounting 42 pcs, Downward mounting 12 pcs |



## Advance preparation

If you build the firmware yourself,
it takes time to prepare the environment,
so it is recommended to start first. \
See [docs/firmware/rev1](../../firmware/rev1/firmware_en.md)
for more information.

## Implementation

The PCB is reversible, so first decide which one to use,
left or right.



### Diodes

Solder the diode of the chip part.
You can attach it to either side, but in this build guide,
we will attach it to the back side.
When using [Tilting / Tenting plate](
https://github.com/foostan/crkbd/blob/master/docs/corne-cherry/v2/buildguide_tilting_tenting_plate_en.md),
be sure to attach it to the back side \_\_.

Since the chip parts are very small,
it is easier to work with tweezers and counter-acting tweezers.
**The diode is installed in a fixed direction **,
so if you arrange the diode in the same row and row as shown in the photo below,
it will proceed smoothly.



The orientation of the diode is as follows:
Install so that the "|||" mark on the chip part faces the "|" of the diode mark "|◁".



The trick is to attach the chip parts, but first, as a spare solder,
put the solder only on the right side of the pad.



Next, solder one leg of the diode so that the spare solder melts.
At this time, it is recommended to use reverse-action tweezers,
because you can hold the chip parts firmly without exerting force
and you can concentrate on alignment and soldering.
Also, if the soldering iron is too hot or the solder is touched too much,
the flux contained in the solder may evaporate and form a clean pile of solder,
but it can be repaired later,
so at this point you should only care about attaching parts.
It's okay.



It is okay if the diode does not float when viewed from the side
when one foot is attached.
If it floats, press the diode with tweezers or your fingers
and reheat the soldered part with a soldering iron to clean it.



Then solder the other one.
Be careful not to apply too much,
as a small amount of solder is sufficient.
If you apply too much, you can remove it with a blotting wire
or by scooping it with a soldering iron.

If the amount of solder on the preliminary solder side is small,
additional soldering is performed, and if it is a mountain,
apply flux from above and heat it to clean it.



### TRRS jack, reset switch

Solder the TRRS jack and reset switch to the surface of the PCB
as shown in the picture below.
In this build guide, the diode is attached to the back side,
so it is the opposite side.



### Jumpers and pin sockets for OLED modules

When using the OLED module, jumper as shown below.
Please note that **only the surface should be jumpered**.

Solder the pin socket to the same surface.



If the jumper doesn't work, the amount of solder is probably too low
or the flux in the solder has vaporized.
In that case, you can fix a jumper by using a large amount of solder
or applying a separate flux.

### ProMicro

Solder the pin header so that it fits into the white frame,
and then solder it with the back side of the Pro Micro facing up.




If you want to use spring-loaded pin headers,
please refer to the [Helix Build Guide](
https://github.com/MakotoKurauchi/helix/blob/master/Doc/buildguide_en.md#pro-micro).

### OLED module

Insert the pin header into the pin socket for OLED first,
and then solder the pin header and OLED module.
At this time, the OLED module is easy to float,
so be careful not to float it while pressing it with your finger.




### Operation check

It is recommended to check the operation when ProMicro and OLED module are attached
(it will be difficult to isolate the problem if you do it at the very end).

To check the operation, first insert the firmware for crkbd into ProMicro
by referring to the "Firmware" chapter below (be sure to insert it on both sides).

To check the operation,
connect the left hand side to the PC with MicroUSB,
and connect the left hand side and the right hand side with the TRS cable.
Since there may be defects such as jacks,
be sure to connect the left and right instead of one by one
before checking the operation.
If it is done correctly so far,
if you short the pad to attach the PCB socket with tweezers etc.,
the key pressed on the OLED module will be displayed.



### Kailh PCB Socket

Fill the pads on both sides of the back with solder.
It is difficult to add it later, so please add more in advance.



Insert the socket and attach it by melting the solder you have.
At this time, hold it down with tweezers or your fingers
so that the socket does not float.



Soldering is now complete.
If you want to add an LED as an option,
refer to the "LED" chapter below
(it can be attached even after installing the socket).



### Plates, switches

First, insert the switch into the top plate.
It's okay to do it later, but it's easier to put it in first,
because it's necessary to insert the switch from a little bit.



Finally, attach the spacers with screws so that the top plate, PCB,
and bottom plate are in that order,
and attach the cushion rubber to the four corners to complete the process.



## Firmware

Write the firmware to ProMicro by referring to the following. \
[docs/firmware/rev1](../../firmware/rev1/firmware_en.md)

## LED (optional)

I will install the SK6812 MINI.

The SK6812MINI is extremely heat sensitive and breaks easily.
We recommend using a soldering iron with a temperature control function
and working at a temperature of 220°C to 270°C.
Even if the temperature is adjusted,
it will be damaged if the iron is applied to the LED for a long time,
so try to solder as quickly as possible.
The LEDs are soldered four by four,
but it is recommended that you do not do four at a time,
but two at a time to prevent the LED temperature from rising,
as it will be less likely to break.

First, check the mounting position.

Solder 1 to 6 so that the back side (Undergrow) shines,
and 7 to 27 so that the front side (Backlight) shines.
Below is the position to install the LED.




Solder 1 to 6 so that the black part circled as shown below is on the bottom
and the silk mark indicated by the arrow is on the top.
Please note that the orientation changes between 1 ~ 3 and 4 ~ 5.



Solder 7 to 27 so that the largest pad circled
and the silk mark indicated by the arrow are adjacent to each other,
as shown below.



If everything can be soldered normally, it will shine as shown below.
If it shines only halfway, the LEDs are connected in numerical order,
so suspect that the LED that does not shine
or the LED in front of it is soldered incorrectly or that the LED is damaged.



That's all there is to it.



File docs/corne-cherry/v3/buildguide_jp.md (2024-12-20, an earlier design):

# Build Guide

こちらは Corne Cherry v3 のビルドガイドになります。
[Corne Cherry v2 はこちら](https://github.com/foostan/crkbd/blob/master/docs/corne-cherry/v2/buildguide_jp.md)。

## 部品

### 必須

| 名前 | 数 | 備考 |
|:-|:-|:-|
| PCB | 1セット | |
| トッププレート | 2枚 | |
| ボトムプレート | 2枚 | |
| OLED保護プレート | 2枚 | |
| ProMicro | 2枚 | |
| TRRSジャック | 2個 | |
| タクトスイッチ | 2個 | |
| ダイオード | 42本 | SMD部品のみ対応 |
| PCBソケット | 42個 | Kailh および Gateron に対応 |
| キースイッチ | 42個 | CherryMX互換のみ対応 |
| キーキャップ | 42個 | 1u 40個、1.5u 2個 |
| スペーサー M2 7.5mm | 10本 | |
| スペーサー M2 9mm | 4本 | |
| ネジ M2 4mm | 28本 | |
| クッションゴム | 8個 | |
| TRRS(4極)ケーブル | 1本 | TRS(3極)ケーブルでも可 |
| Micro USBケーブル | 1本 | |

### オプション

| 名前 | 数 | 備考 |
|:-|:-|:-|
| OLEDモジュール | 2枚 | |
| OLEDモジュール用ピンヘッダ 4連 1.5mm | 2つ | |
| OLEDモジュール用ピンソケット 4連 2.5mm | 2つ | |
| SK6812MINI-E | 42個 | Back light用 LEDs |
| WS2812B | 12個 | Undergrow 用 LEDs |

## 事前準備

ファームウェアを自分でビルドする場合は環境を整備するのに時間がかかるのではじめに取り掛かっておくことをおすすめします。\
詳しくは [docs/firmware/rev1](../../firmware/rev1/firmware_jp.md) を参照してください。

## 確認

Corne Cherry v3 のPCBは以下のものになります。お手持ちのPCBと同一のものかご確認ください。

confirm_front

confirm_back

PCBは製造の都合上フレームが付いた状態となっています。
手で折って外すことができますが、難しい場合は接合部分※にカッター等で切り込みを入れると外しやすくなります。
また、接合部分はヤスリ等できれいにすることができます。

※ 接合部分: 下記画像の赤で記した部分のこと、計8箇所あります

confirm_remove_frame

## 組み立て

### ダイオード

SMD部品のダイオードのはんだづけを行います。
SMD部品は非常に小さいためピンセット及び逆作用ピンセットがあると便利です。

**ダイオードは取り付ける向きが決まっていて**、部品の「|」印が、ダイオードマーク「|◁」の「|」の方に向けるようにはんだづけを行います。
なお、Corne の PCB はダイオードの取り付け向きがすべて統一されています。

build_diode

<details>
<summary>TIPS: SMD部品を取り付けるコツ</summary>

SMD部品を取り付けるコツですが、まずは予備ハンダとしてパットの片側のみにハンダを盛ります。

tips_building_smd_01

次に予備ハンダを溶かすようにしてダイオードの片足をはんだ付けします。
このとき、逆作用ピンセットを利用すると力を入れずともチップ部品をしっかりと持つことができ、位置合わせとはんだづけに集中できるのでおすすめです。
またはんだごてがあつすぎたり、はんだを触りすぎたりするとはんだに含まれるフラックスが気化してきれいにはんだの山ができることがありますが、あとで修復できるのでこの時点ではパーツを付けることだけを意識すれば大丈夫です。

tips_building_smd_02

片足をつけた段階で横から見てダイオードが浮いていなければ大丈夫です。浮いてしまった場合はダイオードをピンセットや指で押さえつけながらはんだごてではんだづけした部分を再度熱すればきれいになります。

tips_building_smd_03

次にもう片方をはんだづけします。少量のはんだで十分なのでつけすぎに注意します。
つけすぎてしまった場合は吸い取り線で取るか、はんだごてですくうようにすれば取れます。

また予備はんだ側のはんだの量が少ない場合は追加ではんだづけを重ねて行い、山になっている場合はフラックスを上から塗って熱すればきれいになります。

tips_building_smd_04

</details>

左右合わせて42個をはんだづけしてダイオードは完了です。

build_diode_overview

### LED（オプション）

SK6812MINI-E と WS2812B をはんだづけします。

先に取り付け後の様子を確認しておきます。

build_led_front_overview

はんだづけはすべて裏側から行いますが、SK6812MINI-E は Backlight (表側を光らせる)用、WS2812B は Undergrow (裏側を光らせる)用になっています。
build_led_back_overview

#### WS2812B (Undergrow)

まずは WS2812B をはんだづけします。

下記のように WS2812B の凹みの角とPCBの角印が合う向きにしてはんだづけを行います。
__TIPS: SMD部品を取り付けるコツ__ で紹介したように、予備ハンダをするとうまくつけられると思います。

なお、Corne の PCB は WS2812B の取り付け向きがすべて統一されています。

build_led_undergrow

左右合わせて計12個はんだづけして WS2812B は完了です。

build_led_undergrow_overview

#### SK6812MINI-E (Backlight)

続いて SK6812MINI-E をはんだづけします。

下記のように SK6812MINI-E の角が欠けた足とPCBの角印が合う向きにしてはんだづけを行います。
__TIPS: SMD部品を取り付けるコツ__ で紹介したように、予備ハンダをするとうまくつけられると思います。
SK6812MINI に比べて壊れにくいですが、はんだごての熱を直接受けると破損する可能性があります。温調機能のついたはんだごてで 320℃ ほどであれば、4つの足を連続にはんだづけしても問題なさそうでした。

なお、Corne の PCB は SK6812MINI-E の取り付け向きがすべて統一されています。

build_led_backlight

左右合わせて計42個はんだづけして SK6812MINI-E は完了です。

build_led_back_overview

### TRRSジャック、リセットスイッチ、OLED用ピンソケット

下記の写真通りにTRRSジャック、リセットスイッチ(タクトスイッチ)、OLED用ピンソケットをはんだづけします。

build_trrs_reset_oled

ずれやすい部品なので、手で部品を抑えながらはんだづけするか、マスキングテープ等で固定してからはんだづけするときれいに付きます。

### ProMicro

ProMicroを下記のような向きではんだ付けします

build_promicro

なお、コンスルーを利用する場合は裏側のはんだ付けをする必要はありません。
コンスルーの詳しい利用方法は [Helix のビルドガイド](https://github.com/MakotoKurauchi/helix/blob/master/Doc/buildguide_jp.md#pro-micro)をご参照ください。

build_promicro_conthrough

### OLEDモジュール

OLED用のピンソケットにピンヘッダを先に差し込み、その後からピンヘッダとOLEDモジュールをはんだづけします。
このときOLEDモジュールが浮きやすいので指で押さえつけながら浮かないように気をつけます。

build_oled

## ファームウェア

下記を参照しファームウェアをProMicroに書き込みます。\
[docs/firmware/rev1](../../firmware/rev1/firmware_jp.md)

### 動作確認

ProMicroとOLEDモジュールを付けた段階で動作確認をすることをおすすめします。
一番最後にやると問題の切り分けが難しくなります。

動作確認は左手側はMicroUSBでPCとつなぎ、左手側と右手側をTRRSケーブルで接続させて行います。ジャック等の不良等もありえるので、片方ずつではなく必ず左右を接続させてから動作確認をしてください。ここまで正しくできていれば、PCBソケットを取り付けるパットをピンセット等でショートさせるとOLEDモジュールに押されたキーが表示されます。

### PCBソケット

PCBソケットを下記のようにマークに合わせてはんだづけします。
下記ではすべてのPCBソケットが並んでいますが、しっかりハマるものではないので、1つずつ付けてください。
__TIPS: SMD部品を取り付けるコツ__ で紹介したように、予備ハンダをするとうまくつけられると思います。

build_socket

左右合わせて計42個はんだづけしてPCBソケットは完了です。

build_socket_overview

### OLED保護プレート

M2 9mm のスペーサーと M2 ネジで OLED 保護プレートを取り付けます。

build_oled_plate_front
build_oled_plate_back

### プレート、スイッチ

トッププレートにキースイッチに取り付けた後、キースイッチをソケットにはめ込みます。
先にすべてのキースイッチをトッププレートに取り付けてしまうと、ソケットにはめ込む難易度が上がってしまうため、先に端のキースイッチのみを取り付ける方が簡単です。
build_top_plate_switches

M2 7.5mm のスペーサーと M2 ネジ をトッププレートに取り付けます。

build_screws_spacers_front

裏側からスペーサーを穴に入れた後、ネジ止めをすると簡単です。

build_screws_spacers_back

ボトムプレートを M2 ネジで取り付けます。

build_bottom_plate

クッションゴムを以下の位置に取り付けます。

build_cushion_rubbers

以上で完成です。

build_finish

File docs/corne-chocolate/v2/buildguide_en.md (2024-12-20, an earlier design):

# Build Guide

This is the build guide for Corne Chocolate.
[Click here for the Corne Cherry build guide](
https://github.com/foostan/crkbd/blob/master/docs/corne-cherry/v2/buildguide_en.md).

## Parts

### Required

| Name | Count | Remarks |
|:-|:-|:-|
| PCB | 2 pieces | |
| Top plate | 2 pieces | |
| Bottom plate | Two pieces | PCB type and acrylic type are available |
| Pro Micro protection plate | 2 pieces | |
| Pro Micro | 2 | |
| TRRS Jack | 2 | |
| Tactile switch | 2 pieces | |
| Diode | 42 pieces | Compatible with chip components only
| Kailh PCB Socket (for Choc) | 42 | |
| Key switch | 42 pieces | Compatible with Choc (low profile) only |
| Key-caps | 42 | 1u 40, 1.5u 2 |
| OLED module | 2 pieces | |
| 4 pin headers | 2 | |
| 4 pin sockets | 2 | |
| Spacer M2 4.5mm | 10 | |
| Spacer M2 9mm | Four | |
| Screw M2 4mm | 28 | |
| Cushion rubber | 8 pieces | |
| TRS (3 pole) cable | 1 | TRRS (4 pole) cable also available |
| Micro USB Cable | 1 | |

### Optional

| Name | Count | Remarks |
|:-|:-|:-|
| SK6812MINI | 54 | 42 for backlight, 12 for under-glow |

## Advance preparation

If you build the firmware yourself,
it will take some time to set up the environment,
so it's best to start at the beginning. \
For more information,
please see [docs/firmware/rev1](../../firmware/rev1/firmware_en.md).

## Building

Since the PCB is reversible,
you first have to decide which one to use for the left side.



### Diodes

Solder the diodes to the PCB.

On Corne Cherry, it is up to you to choose which side to attach,
but with Corne Chocolate you must **be sure to attach it to the back**.
Mounting on the front will interfere with the top plate.

Since the diodes are very small,
it is easier to work with tweezers and inverted tweezers.
Since the **mounting orientation of the diode is crucial**,
it is possible to proceed smoothly
if you arrange the columns and rows to be mounted in advance,
as shown in the following photo.



The orientation of the diode is as follows.
Attach the chip component so that the "|||" mark on the diode is facing the "|"
of the diode mark "|◁" on the PCB (image from Corne Cherry).



Tip for soldering on SMD parts:
First put solder only on the right side of the pad.



Next, solder one of the diodes by melting the solder you already put on the board.
At this time,
it is recommended to use [reverse-action tweezers](https://www.alimed.com/_resources/cache/images/product/70895A_850x480-pad.jpg),
so that you can hold the SMD part firmly without applying force,
and concentrate on alignment and soldering instead.
Also, if the soldering iron is too hot or the solder is touched too long,
the flux contained in the solder may evaporate and form an undesirable pile solder,
but since it can be repaired later,
so at this point you should only care about attaching parts.
It's okay.



Then solder the other pin.
Be careful not to apply too much solder,
as a small amount is sufficient.
If you have applied too much,
you can remove it with a suction pump, blotting wire
or by scooping it with a soldering iron.



If the amount of solder on the pre-soldering side is too small,
add more soldering,
and if it is pilled up,
apply flux from above and heat to clean.



### TRRS jack, reset switch, pin socket



Solder the TRRS jack, reset switch and pin socket to the **front of the PCB**
as shown in the picture below.
Since the diode is attached on the back side,
it will be on the opposite side.



### Jumpers for OLED modules

When using an OLED module, use solder as jumpers (4 times per side) as follows.
**Please jumper only on the surface**.



If the jumper doesn't work,
you probably have a small amount of solder,
or the flux has vaporized.
If so, you can fix the jumper by applying more solder or separate flux.

### Pro Micro



Solder the pin headers to the white frame
and solder the Pro Micro with back side up.




When using the spring-loaded pin headers,
please refer to the [Helix Build Guide](
https://github.com/MakotoKurauchi/helix/blob/master/Doc/buildguide_en.md#pro-micro).

### OLED module



Insert the pin header into the OLED pin socket first,
then solder the pin header and the OLED module.
At this time,
make sure that the OLED module sits tightly on the socket
while holding it down with your finger,
because it tends to stick out easily.




### Operation check

We recommend that you check the operation at the stage
where the Pro Micro and OLED modules are attached
(it is difficult to isolate the problem at the end).

Before checking the correct operation,
flash the crkbd firmware to the Pro Micro
by referring to the [Firmware](#firmware) section below
(be sure to insert it on both sides).

Operation confirmation is performed
by connecting the left hand side to a PC with Micro USB
and connecting the left hand side and the right hand side with a TRS cable.
Since there may be a defect such as a jack,
make sure to connect the left and right
instead of one by one before checking the operation.
If you have done this correctly,
short-circuit the pad to attach the PCB socket with tweezers,
and the key pressed on the OLED module will be displayed.



## LED (optional)



I will install SK6812MINI.
The LED can be mounted even after completion,
so if you are worried about mounting it,
we recommend that you skip this chapter and complete it first.

SK6812MINI is very heat sensitive and breaks easily.
We recommend using a soldering iron with a temperature control function
and operating at a temperature of about 220°C to 270°C.
Even if the temperature is set that low,
the LED will be damaged if the iron is left on it for a long time,
so try to solder as quickly as possible.
Solder four LEDs at a time,
but we recommend soldering two at a time instead of four at a time
to prevent the LED temperature from rising,
as this will make it less likely to overheat.

First, check the mounting position.

Solder 1 - 6 so that the back side (under-glow) shines,
7 - 27 so that the front side (back-light) shines.
Below is the location to attach the LED (image from Corne Cherry).




For LEDs 1 to 6,
solder the part so that the black part circled below is on the bottom
and the silk mark indicated by the arrow is on the top.
Note that the direction changes between 1 - 3 and 4 - 5.



For 7 - 27,
perform soldering so that the largest pad surrounded by a circle
and the silk mark indicated by an arrow are adjacent to each other,
as shown below.



If everything was successfully soldered,
it will glow as follows.
If the LED lights only halfway,
the LEDs are connected in the order of the numbers.
Therefore, it is likely that the LED that does not emit light
or the previous LED are incorrectly soldered or damaged.





### Kailh PCB Socket



Apply solder to the pads on both sides on the back.
It is difficult to add it later,
so please fill it up beforehand.



Insert the socket and melt the solder.
At this time,
hold the socket with tweezers or your fingers so that the socket sticks to the board.



The soldering is now complete.




### Plate, switch



Use 4.5mm spacers for the top and bottom plates
and 9mm spacers for the OLED.



In addition,
it is recommended to paint the side of the plate with a black marker
because it looks better.



## Firmware

See below to flash the firmware to the ProMicro. \
[docs/firmware/rev1](../../firmware/rev1/firmware_en.md)

This is the end.



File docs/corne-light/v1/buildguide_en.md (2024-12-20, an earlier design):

# Build Guide

This is the Corne Light v1 build guide.

## Parts

<table>
<thead>
  <tr> <td width = "30%"> Name </td> <td width = "15%"> Count </td> <td> Remarks </td> </tr>
</header>
<tbody>
  <tr>
    <td> PCB </td>
    <td> 1 set </td>
    <td>
      PCB
    </td>
  </tr>
  <tr>
    <td> Top plate </td>
    <td> 2 sheets </td>
    <td>
      top-plates
    </td>
  </tr>
  <tr>
    <td> Bottom plate </td>
    <td> 2 sheets </td>
    <td rowspan = "2">
      bottom-plates
    </td>
  </tr>
  <tr>
    <td> ProMicro protective plate </td>
    <td> 2 sheets </td>
  </tr>
  <tr>
    <td> diode </td>
    <td> 42 </td>
    <td>
      diodes
    </td>
  </tr>
  <tr>
    <td> Spacer M2 7.5mm </td>
    <td> 10 </td>
    <td rowspan = "3">
      screws
    </td>
  </tr>
  <tr>
    <td> Spacer M2 9mm </td>
    <td> 4 </td>
  </tr>
  <tr>
    <td> Screw M2 4mm </td>
    <td> 28 </td>
  </tr>
  <tr>
    <td> TRRS jack </td>
    <td> 2 </td>
    <td rowspan = "3">
      jacks
    </td>
  </tr>
  <tr>
    <td> Reset switch </td>
    <td> 2 </td>
  </tr>
  <tr>
    <td> Rubber feet </td>
    <td> 8 </td>
  </tr>
  <tr>
    <td> ProMicro (with conthrough) </td>
    <td> 2 </td>
    <td>
      <a href="https://yushakobo.jp/shop/promicro-spring-pinheader/"> https://yushakobo.jp/shop/promicro-spring-pinheader/ </a>
    </td>
  </tr>
  <tr>
    <td> OLED module (with pin socket) </td>
    <td> 2 </td>
    <td>
      <a href="https://yushakobo.jp/shop/oled/"> https://yushakobo.jp/shop/oled/ </a>
    </td>
  </tr>
  <tr>
    <td> key switch </td>
    <td> 42 </td>
    <td> </td>
  </tr>
  <tr>
    <td> keycap </td>
    <td> 42 </td>
    <td> </td>
  </tr>
  <tr>
    <td> TRRS cable </td>
    <td> 1 </td>
    <td> TRS cable is also acceptable </td>
  </tr>
  <tr>
    <td> USB cable </td>
    <td> 1 </td>
    <td> </td>
  </tr>
</tbody>
</table>

## Advance preparation

If you build the firmware yourself,
it takes time to prepare the environment,
so it is recommended to start first. \
See [docs/firmware/rev1](../../firmware/rev1/firmware_en.md)
for more information.

## Implementation

### PCB disconnection

Check the front and back and separate the left and right PCBs
(the photo is the front).

assembly-pcb

This is a jig for bending the legs of a diode.
Separate it if necessary.

assembly-tool-of-diodes

* Some versions do not have a jig.

### Diodes

First, bend the legs of the reed type diode.

* You can clean it by bending it one by one as shown in the picture,
  but it is more efficient to bend multiple pieces at the same time
  while connected to the tape.

assembly-diodes-1

Attach the diode with the bent leg to the specified position.

assembly-diodes-2

The diode has an orientation and is installed as shown in the photo.

* All the diodes to be attached are in the same orientation.

assembly-diodes-3

You can attach it neatly by fixing it with masking tape.

assembly-diodes-4

Solder from the back side.

assembly-diodes-5

If you are fixing with masking tape,
cutting your legs to the limit like this will make soldering easier.

assembly-diodes-6

With 21 one-handed and two-handed he installs 42 diodes.

assembly-diodes-7

### TRRS jack, reset switch, pin socket

Install in the specified position.

* Install the right hand side in the same position
  (be careful of mistakes on the front and back).

assembly-jacks-resets-pinsockets-1

### ProMicro, OLED module

Install his ProMicro and his OLED module by referring to the [Helix Build Guide](
https://github.com/MakotoKurauchi/helix/blob/master/Doc/buildguide_en.md#pro-micro).

assembly-promicro-oled

### Firmware

Write the firmware to ProMicro by referring to the following. \
[docs/firmware/rev1](../../firmware/rev1/firmware_en.md)

### Operation check

To check the operation,
connect the left hand side to the PC with a USB cable,
and connect the left hand side and the right hand side with the TRRS cable.
Since there may be defects such as jacks,
be sure to connect the left and right instead of one by one
before checking the operation.

* Since the switch is not attached,
  check the operation with tweezers as shown in the photo.

check

### Top plate, key switch

Attach the key switch to the top plate as shown in the picture.

* Be careful of the direction of the key switch.

assembly-keyswitches-1

We recommend using a 3-pin key switch.

* Even when using 5 pins, the plastic legs can be separated to make 3 pins.

assembly-keyswitches-2

Solder so that there is no gap between the switch and the PCB.

assembly-keyswitches-3
assembly-keyswitches-4

### ProMicro Protective Plate, Bottom Plate

Attach his ProMicro protective plate using an M2 9mm spacer.

assembly-plates-1

Install the bottom plate using the M2 7.5mm spacer.

assembly-plates-2

Attach the rubber feet to the four corners.

assembly-plates-3

## Complete

Attach the keycap and you're done.

assembly-finished-1
assembly-finished-2

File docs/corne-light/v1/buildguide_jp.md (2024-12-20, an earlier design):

# Build Guide

こちらは Corne Light のビルドガイドになります。

## 部品

<table>
<thead>
  <tr><td width="30%">名前</td><td width="15%">数</td><td>備考</td></tr>
</thead>
<tbody>
  <tr>
    <td>PCB</td>
    <td>1セット</td>
    <td>
      PCB
    </td>
  </tr>
  <tr>
    <td>トッププレート</td>
    <td>2枚</td>
    <td>
      top-plates
    </td>
  </tr>
  <tr>
    <td>ボトムプレート</td>
    <td>2枚</td>
    <td rowspan="2">
      bottom-plates
    </td>
  </tr>
  <tr>
    <td>ProMicro保護プレート</td>
    <td>2枚</td>
  </tr>
  <tr>
    <td>ダイオード</td>
    <td>42本</td>
    <td>
      diodes
    </td>
  </tr>
  <tr>
    <td>スペーサー M2 7.5mm</td>
    <td>10本</td>
    <td rowspan="3">
      screws
    </td>
  </tr>
  <tr>
    <td>スペーサー M2 9mm</td>
    <td>4本</td>
  </tr>
  <tr>
    <td>ネジ M2 4mm</td>
    <td>28本</td>
  </tr>
  <tr>
    <td>TRRSジャック</td>
    <td>2つ</td>
    <td rowspan="3">
      jacks
    </td>
  </tr>
  <tr>
    <td>リセットスイッチ</td>
    <td>2つ</td>
  </tr>
  <tr>
    <td>ゴム足</td>
    <td>8つ</td>
  </tr>
  <tr>
    <td>ProMicro(コンスルー付き)</td>
    <td>2つ</td>
    <td>
      <a href="https://yushakobo.jp/shop/promicro-spring-pinheader/">https://yushakobo.jp/shop/promicro-spring-pinheader/</a>
    </td>
  </tr>
  <tr>
    <td>OLEDモジュール(ピンソケット付き)</td>
    <td>2つ</td>
    <td>
      <a href="https://yushakobo.jp/shop/oled/">https://yushakobo.jp/shop/oled/</a>
    </td>
  </tr>
  <tr>
    <td>キースイッチ</td>
    <td>42個</td>
    <td></td>
  </tr>
  <tr>
    <td>キーキャップ</td>
    <td>42個</td>
    <td></td>
  </tr>
  <tr>
    <td>TRRSケーブル</td>
    <td>1本</td>
    <td>TRSケーブルでも可</td>
  </tr>
  <tr>
    <td>USBケーブル</td>
    <td>1本</td>
    <td></td>
  </tr>
</tbody>
</table>

## 事前準備

ファームウェアを自分でビルドする場合は環境を整備するのに時間がかかるのではじめに取り掛かっておくことをおすすめします。\
詳しくは [docs/firmware/rev1](../../firmware/rev1/firmware_jp.md) を参照してください。

## 実装

### PCBの切り離し

裏表を確認して左右のPCBを切り離します(写真は表です)。

assembly-pcb

こちらはダイオードの足を曲げるための治具です。
必要に応じて切り離しておきます。

assembly-tool-of-diodes

※　バージョンによって治具が付いていないものもあります。

### ダイオード

まずはリードタイプのダイオードの足を曲げていきます。
※ 写真のように一本ずつ曲げるときれいにできますが、テープに繋がれたまま複数本を同時に曲げたほうが効率的です。

assembly-diodes-1

足を曲げたダイオードを指定の位置に付けていきます。

assembly-diodes-2

ダイオードには向きがあり、写真のように取り付けます。
※ 取り付けるダイオードはすべて同じ向きです。

assembly-diodes-3

マスキングテープで固定するときれいに付けることができます。

assembly-diodes-4

裏面からはんだ付けを行います。

assembly-diodes-5

マスキングテープで固定している場合はこのようにギリギリまで足を切るとはんだ付けがやりやすくなります。

assembly-diodes-6

片手21個、両手分で 42 個のダイオードを取り付けます。

assembly-diodes-7

### TRRSジャック、リセットスイッチ、ピンソケット

指定の位置に取り付けます。
※ 右手側も同じ位置に取り付けます(表裏の間違いに気を付けてください)。

assembly-jacks-resets-pinsockets-1

### ProMicro、OLEDモジュール

[Helix のビルドガイド](https://github.com/MakotoKurauchi/helix/blob/master/Doc/buildguide_jp.md#pro-micro)を参考にして ProMicro および OLED モジュールを取り付けます。

assembly-promicro-oled

### ファームウェアの書き込み

下記を参照しファームウェアをProMicroに書き込みます。\
[docs/firmware/rev1](../../firmware/rev1/firmware_jp.md)

### 動作確認

動作確認は左手側を USB ケーブルで PC とつなぎ、左手側と右手側を TRRS ケーブルで接続して行います。ジャック等の不良もありえるので、片方ずつではなく必ず左右を接続させてから動作確認をしてください。
※ スイッチを付けてないので写真のようにピンセット等で動作確認を行います。

check

### トッププレート、キースイッチ

写真のようにトッププレートにキースイッチをはめます。
※ キースイッチの向きに気を付けてください。

assembly-keyswitches-1

キースイッチは3ピンのものをおすすめします。
※ 5ピンを使用する場合でもプラスチックの足を切り離して3ピンにすることができます。

assembly-keyswitches-2

スイッチとPCBの間に隙間ができないようにしてはんだ付けを行います。

assembly-keyswitches-3
assembly-keyswitches-4

### ProMicro 保護プレート、ボトムプレート

M2 9mm スペーサーを用いて ProMicro 保護プレートを取り付けます。

assembly-plates-1

M2 7.5mm スペーサーを用いてボトムプレートを取り付けます。

assembly-plates-2

4つ角にゴム足を取り付けます。

assembly-plates-3

## 完成

キーキャップを取り付けて完成です。

assembly-finished-1
assembly-finished-2

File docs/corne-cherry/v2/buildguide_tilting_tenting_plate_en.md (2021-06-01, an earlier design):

# Build Guide Tilting / Tenting plate

## Parts

| Name | Count | Remarks |
|:-|:-|:-|
| Completed Corne Cherry | 1 set | Corne Chocolate / 3mm top plate is not supported |
| Middle plate 3mm | 2 sheets | |
| Bottom plate 3mm | 2 sheets | |
| Bolt M5 15mm ~ 50mm | 8 bolts | |
| Nut M5 | 16 pieces | |
| Screw M2 6mm | 10 screws | |
| Screw M2 4mm | 10 screws | |
| Spacer M2 3.5mm | 10 pieces | |
| Cushion rubber | 8 pieces | |

## Advance preparation

lrg_dsc05736

Remove the key switch from the finished Corne Cherry
to separate the body from the top plate.
No other parts are needed.

## Assembly

lrg_dsc05737
lrg_dsc05739

Check the required parts.
Check the dedicated middle plate and bottom plate, and bolts of various lengths.
In addition, use screws, nuts, spacers, etc. (see the parts section for details).

lrg_dsc05742

Secure the middle plate to the top plate with 6mm screws and 3.5mm spacers.

lrg_dsc05744
Secure the OLED display protection plate with 4mm screws.

lrg_dsc05745

Secure the body and bottom plate with 4mm screws.

lrg_dsc05747

Insert an acrylic spacer between the middle plate
and the bottom plate and attach the bolts.

lrg_dsc05748

It is recommended to temporarily assemble the bolts
and adjust the height before completely fixing them with nuts.
Temporary assembly can be done easily by passing only one nut through the bolt.

lrg_dsc05749
lrg_dsc05750

It is completed by firmly fixing it so that it is sandwiched between nuts.

lrg_dsc05761

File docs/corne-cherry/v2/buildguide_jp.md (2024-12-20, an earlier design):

# Build Guide

こちらは Corne Cherry v2 のビルドガイドになります。
[Corne Cherry v3 はこちら](https://github.com/foostan/crkbd/blob/master/docs/corne-cherry/v3/buildguide_jp.md)。

## 部品

### 必須

| 名前 | 数 | 備考 |
|:-|:-|:-|
| PCB | 2枚 | |
| トッププレート | 2枚 | |
| ボトムプレート | 2枚 | PCBタイプとアクリルタイプが選べます |
| ProMicro保護プレート | 2枚 | |
| ProMicro | 2枚 | |
| TRRSジャック | 2個 | |
| タクトスイッチ | 2個 | |
| ダイオード | 42本 | チップ部品のみに対応 |
| Kailh PCBソケット | 42個 | |
| キースイッチ | 42個 | CherryMX互換にのみ対応 |
| キーキャップ | 42個 | 1u 40個、1.5u 2個 |
| OLEDモジュール | 2枚 | |
| ピンヘッダ 4連 | 2つ | |
| ピンソケット4連 | 2つ | |
| スペーサー M2 7.5mm | 10本 | |
| スペーサー M2 9mm | 4本 | |
| ネジ M2 4mm | 28本 | |
| クッションゴム | 8個 | |
| TRS(3極)ケーブル | 1本 | TRRS(4極)ケーブルでも可 |
| Micro USBケーブル | 1本 | |

### オプション

| 名前 | 数 | 備考 |
|:-|:-|:-|
| SK6812MINI | 54個 | 上向き実装 42個、下向き実装 12個 |



## 事前準備

ファームウェアを自分でビルドする場合は環境を整備するのに時間がかかるのではじめに取り掛かっておくことをおすすめします。\
詳しくは [docs/firmware/rev1](../../firmware/rev1/firmware_jp.md) を参照してください。

## 実装

PCBはリバーシブルになっているので、最初にどちらを左用/右用にするか決めます。



### ダイオード

チップ部品のダイオードのはんだづけを行います。
どちらの面に取り付けるかは自由ですが、このビルドガイドでは裏面に取り付けていきます。
なお、[Tilting/Tenting plate](https://github.com/foostan/crkbd/blob/master/docs/corne-cherry/v2/buildguide_tilting_tenting_plate_jp.md)を利用する場合は __必ず裏面につけてください__。

チップ部品は非常に小さいためピンセット及び逆作用ピンセットがあると作業がしやすくなります。
**ダイオードは取り付ける向きが決まっている**ので、次の写真のように予め取り付ける列と行、ダイオードの向きを揃えて配置しておくとスムーズに進められます。



ダイオードの向きは次のとおりです。チップ部品の「|||」印が、ダイオードマーク「|◁」の「|」の方に向けるように取り付けます。



チップ部品を取り付けるコツですが、まずは予備ハンダとしてパッドの右側のみにハンダを盛ります。



次に予備ハンダを溶かすようにしてダイオードの片足をはんだ付けします。
このとき、逆作用ピンセットを利用すると力を入れずともチップ部品をしっかりと持つことができ、位置合わせとはんだづけに集中できるのでおすすめです。
またはんだごてがあつすぎたり、はんだを触りすぎたりするとはんだに含まれるフラックスが気化してきれいにはんだの山ができることがありますが、あとで修復できるのでこの時点ではパーツを付けることだけを意識すれば大丈夫です。



片足をつけた段階で横から見てダイオードが浮いていなければ大丈夫です。浮いてしまった場合はダイオードをピンセットや指で押さえつけながらはんだごてではんだづけした部分を再度熱すればきれいになります。



次にもう片方をはんだづけします。少量のはんだで十分なのでつけすぎに注意します。
つけすぎてしまった場合は吸い取り線で取るか、はんだごてですくうようにすれば取れます。

また予備はんだ側のはんだの量が少ない場合は追加ではんだづけを重ねて行い、山になっている場合はフラックスを上から塗って熱すればきれいになります。



### TRRSジャック、リセットスイッチ

下記の写真通りにTRRSジャック、リセットスイッチをPCBの表面にはんだづけします。
このビルドガイドではダイオードを裏側につけているので、その反対側の面になります。



### OLEDモジュールのためのジャンパとピンソケット

OLEDモジュールを利用する場合は下記のようにジャンパします。
なお**表面のみジャンパしてください**。

ピンソケットも同じ面にはんだづけします。



ジャンパがうまくいかない場合はおそらくはんだの量が少ないか、はんだに含まれるフラックスが気化してしまっています。
その場合は、はんだを多めに使うか、別途フラックスを塗るとうまくジャンパができます。

### ProMicro

ピンヘッダを白い枠に当てはめるようにはんだづけし、そこにProMicroの裏面を上にしてはんだづけします。




なおスプリングピンヘッダを利用する場合は [Helix のビルドガイド](https://github.com/MakotoKurauchi/helix/blob/master/Doc/buildguide_jp.md#pro-micro)を参考にしてください。

### OLEDモジュール

OLED用のピンソケットにピンヘッダを先に差し込み、その後からピンヘッダとOLEDモジュールをはんだづけします。
このときOLEDモジュールが浮きやすいので指で押さえつけながら浮かないように気をつけます。




### 動作確認

ProMicroとOLEDモジュールを付けた段階で動作確認をすることをおすすめします(一番最後にやると問題の切り分けが難しくなる)。

動作確認をする場合は先に下記の「ファームウェア」の章を参考にしてcrkbd用のファームウェアをProMicroに入れてください（必ず両側に入れてください）。

動作確認は左手側はMicroUSBでPCとつなぎ、左手側と右手側をTRSケーブルで接続させて行います。ジャック等の不良等もありえるので、片方ずつではなく必ず左右を接続させてから動作確認をしてください。ここまで正しくできていれば、PCBソケットを取り付けるパッドをピンセット等でショートさせるとOLEDモジュールに押されたキーが表示されます。



### Kailh PCBソケット

裏面の両側のパッドにはんだを盛ります。後から追加するのが難しいので予め多めに盛ってください。



ソケットをはめこみ、持ったはんだを溶かすようにして取り付けます。
このときソケットが浮かないようにピンセットや指で押さえつけながら行います。



はんだづけはこれで完了です。
オプションでLEDを付ける場合は下記の「LED」の章を参照してください（ソケットを取り付けた後でも付けれられます）。



### プレート、スイッチ

先にスイッチをトッププレートにはめこみます。
あとからでもいいですが、スイッチのはめこみは多少ちからを入れる必要があるので、先にはめておいたほうが楽です。



最後にトッププレート、PCB、ボトムプレートの順になるように、ネジでスペーサを取り付けて、四隅にクッションゴムを取り付ければ完成です。



## ファームウェア

下記を参照しファームウェアをProMicroに書き込みます。\
[docs/firmware/rev1](../../firmware/rev1/firmware_jp.md)

## LED（オプション）

SK6812MINIを取り付けていきます。

SK6812MINIは非常に熱に弱く、簡単に壊れます。
温調機能がついたはんだごてを利用し、220℃ ~ 270℃ぐらいの温度で作業することをおすすめします。
また温度を調整しても長い時間コテをLEDに当てていると破損するので、なるべくすばやくはんだづけすることを心がけます。
LEDは４つずつはんだづけを行いますが、一度に４つ行わず、２つずつ行ってLEDの温度の上昇を防ぐと破損しづらくなるのでおすすめです。

まずは取り付ける位置の確認です。

1 ~ 6は裏面側(Undergrow)が光るようにし、7 ~ 27は表側（Backlight）が光るようにはんだづけを行います。下記がLEDを取り付ける位置です。




1 ~ 6 は下記のように丸印で囲った黒い部分を下にしたとき、矢印で示したシルクの目印が上になるようにはんだづけを行います。
1 ~ 3 と 4 ~ 5 で向きが変わるので注意してください。



7 ~ 27 は下記のように、丸印で囲った一番大きなパッドと、矢印で示したシルクの目印が隣り合うようにはんだづけを行います。



すべて正常にはんだづけができれば下記のように光ります。
もし途中までしか光らない場合は数字の順番でLEDがつながっているので、光らないLEDもしくはその前のLEDのはんだづけミスやLEDの破損を疑ってください。



これで完成です。



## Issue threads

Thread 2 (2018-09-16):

Documentation not readily accessible

cschmautz, 2018-09-16:
## Issue
Documentation for assembly is only in Japanese, which is fine if using Google Chrome which can do translations to English; however, the documentation is still very sparse, leaving first-time-user of both the LED display and SMD LEDs kind of in the dark about debugging the assembly of the board.

### Symptoms
My board, assembled, works just fine for key presses, but the LED screen and LEDs do not illuminate. Nowhere in the documentation really lists how to go about fixing / debugging these issues, just 'solder it in and it'll be good to go'. This is my first rodeo with these components and I'm a bit at a loss quite frankly.

### Proposed solution
Please give some English documentation, as well as possibly expand on troubleshooting steps to follow when these devices fail to respond. This can be housed in this repository, or if there is some other 'source of truth', please link to those documents for us newbs of the truly custom keyboard.

Looking forward to hearing back with more information - have enjoyed the build so far!

jeffreykxiao, 2018-09-16:
I am assuming you're coming from /u/network_operations / keyhive's group buy? I feel like the support for the GB should really be from him, and the translation as well. Aside from that, you'll definitely get more support from posting to /r/olkb or /r/mechanicalkeyboards, especially if you include pics of your build and a link to the keymap you're using. I know it's linked in the crkbd documentation, but have you taken a look at the [Helix](https://github.com/MakotoKurauchi/helix/tree/master/Doc) docs? They're not the same board, but Helix has a lot of the same information. Maybe it can answer some of your questions.

Regarding the OLED screens - after looking at the default keymap from CRKBD, as long as you flashed it without any changes, it really should just 'be good to go'. There's a define in the config.h and some other stuff going on in the keymap so it shouldn't be an issue of `OLED_ENABLE = false` or anything. The only thing I would make sure is that you soldered the OLED jumpers on both halves of the keyboard (but not both sides of each pcb!)

As for the RGB LEDs, those SK6812minis are super finicky, as in they have a high failure rate if exposed to heat over 240(?)C and as a side note they don't respond well to isopropyl alcohol or deionized water. I think those are enabled in the default keymap, but I'm not super sure. If the first (closest to the pro micro) LED is dead, then then none of the other LEDs would work. Best to use a multimeter to check em out. I also dug up an old tweet from mtei / MakotoKurauchi, creator of the helix, regarding testing of those LEDs, hope it can be useful to you: https://twitter.com/mtei/status/970334819400888321

foostan, 2018-09-18:
Thank you to your feedbacks.

> Documentation for assembly is only in Japanese

I will plan to translation in english, but I should development new pcb and more.
Please wait the moment.

heinrisch, 2018-12-08:
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

How is the translation going?

foostan, 2018-12-11:
@ryo1kato Thank you so much, You've been very helpful.

Closed 2018-12-11.

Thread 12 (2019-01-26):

Wondering about QMK Proton C

leotumwattana, 2019-01-26:
The QMK Proton C seems like a great new controller with more flash and faster ARM based chip. Was wondering if anyone tried using it with Corne?

leotumwattana, 2019-01-30:
Yeah. I know about the Elite-C. I personally don't care that much about the connector. That's because I use magnetic connectors. So whether the connector is USB-C or Micro doesn't matter to me too much.

I'm more interested in the ARM based chip. Which has more flash so that I can turn on more features. For example, right now, I have to turn some QMK features off so that I can fit in Dynamic Macros. Would be nice if I can basically turn everything on. 😆

I also don't mind breaking off extra pins from the Proton C. I would rather keep the beautiful profile of the Corne over having sound (personal preference). Of course, if @foostan figures something out that looks nice, I'm game for it.

jeffreykxiao, 2019-01-31:
@leotumwattana The current version of the QMK firmware has no support for ARM-based chips on split keyboards. You can check out `split_common` in the QMK firmware and you'll see everything there is for AVR. Unfortunately, I don't think that @foostan can really do anything about this; IIRC the effort for getting ARM support for splits hasn't started yet and it might be a long way off. I'd like to use the Proton C myself, but at this point it's either wait or contribute to QMK.

leotumwattana, 2019-01-31:
@jeffreykxiao Ah, ic. Thanks for explaining the situation. I guess it's a waiting game for now. Look forward to it though.

snowe2010, 2019-04-09:
@kmanwar89 do you have some pictures and maybe a tutorial of your Elite-C on your crkbd? I would like to use usb-c with my incoming crkbd if possible.

kmanwar89, 2019-04-18:
>
>
> @kmanwar89 do you have some pictures and maybe a tutorial of your Elite-C on your crkbd? I would like to use usb-c with my incoming crkbd if possible.

Apologies @snowe2010, the notification for this comment went to an email I almost never check.  I can take some pictures and unicast them to you when I get a free chance this evening/this weekend?  I honestly built the board and don't use it, but that's mostly because I'm putting off having to program it and learn QMK....

I will say I really enjoy the USB-C connector, since most phones have USB-C now and the cables are far more prevalent.

snowe2010, 2019-04-18:
That would be awesome. Thanks!

danielo515, 2019-05-03:
> That's because I use magnetic connectors. So whether the connector is USB-C or Micro doesn't matter to me too much.

Would you mind sharing your magnetic conector?

leotumwattana, 2019-05-03:
Sure. I use this one from XPower: http://www.xpower.com.hk/magnetic-cable

kmanwar89, 2019-06-02:
>
>
> That would be awesome. Thanks!

@snowe2010 I am the worst -- I told you I'd take a screenshot and never did. If you still need them, I can take some and upload them.  Honestly though, I just followed the build guide and just used an Elite-C instead of a Pro Micro. Wired and soldered it the exact same way, since it's the same board. The CRKBD doesn't have room for the extra breakout pins (which can be used to control a speaker, how cool!), so make sure you only buy the version without it (or break it off if you do get it on your controller).

Other than that, it's just a drop-in replacement for the ProMicro from my experience. This is my first ever board I've built and first time ever doing anything with soldering or small electronics, so take my advice with a heavy dab of salt!

snowe2010, 2019-06-03:
@kmanwar89 	ok, no worries. As long as it's drop in it should be fine.

kmanwar89, 2019-06-10:
@snowe2010  yup. drop-in replacement for Pro Micro.

joric, 2019-08-04:
You could use this https://github.com/joric/nrfmicro/wiki/Corne-BLE

Closed 2019-09-30.

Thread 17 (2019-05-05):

Purpose of extra breakout pins

filoxo, 2019-05-05:
Hi! I had a question about the extra pins that are broken out just below the pins for the OLED screen, labelled P1, P2, R1, and R2.

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

Typically I would expect R to mean resistor. I have no idea what P could mean here.

I've typically seen the need for 2 resistors to enable [i<sup>2</sup>c](https://github.com/qmk/qmk_firmware/tree/master/keyboards/lets_split#wiring) which I have not seen that mentioned in any of the documentation; but [i<sup>2</sup>c seems to be enabled by default in QMK](https://github.com/qmk/qmk_firmware/blob/master/keyboards/crkbd/rules.mk#L70) for this keyboard. Any info would be appreciated! Thank you in advance!

filoxo, 2019-05-05:
Was examining the traces, and the P holes seem to just be breakouts for those wires, nothing more, and they lead to the TRRS jack. The Rs are for resistors, and that indicates to me that these are for enabling i2c proper. Interesting that the build guide does not mention these and i2c is enabled by default. It should probably be defined to use serial instead. I wonder if this is the reason I'm having issues with the RGB_MATRIX stuff right now.

foostan, 2019-06-03:
> Was examining the traces, and the P holes seem to just be breakouts for those wires

That's right!

> Interesting that the build guide does not mention these and i2c is enabled by default.

It's for i2c but the firmware of  crkbd is not compatible yet.

> It should probably be defined to use serial instead.

The crkbd use serial by default, but i2c used by OLED display.

Thanks.

filoxo, 2019-06-03:
Thanks for the info!

dsanchezseco, 2019-08-21:
Hi!! I follow this road to and ended here(sorry for the message in the closed "issue")

So I guess that breaking the data trace and adding the 4.7k resistors in R1-P1 and R2-P2 would do the trick to enable I2C in the board although the software is not ready.

Are you working on it? I maybe give it a try as I was working on my keymap and saw that the oled config is outdated and there's a new lib for it.

just two quick questions, y suppose that the data trace has to be broken only in one half as well as only two resistors are required, right?

also thank for this board, is the second day I'm  using it and I love it!!

grant-park, 2019-12-23:
Hi @dsanchezseco

Can you share a picture of the part of your PCB that has the changes necessary for i2c? I have no idea how to follow steps 1-3 without risking ruining my PCB, especially since you mentioned breaking the data trace.

dsanchezseco, 2019-12-29:
Hi! @grant-park i didn't do it, i was just asking as you how to do it and thinking about the procedure looking at other keebs and the qmk docs. Sorry

Closed 2019-06-03.

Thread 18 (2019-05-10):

TRS Cable is Insufficient

cgrange, 2019-05-10:
The build guide says that TRS or TRRS cables can be used. I tried mine initially with a TRS cable and whatever side was plugged into the usb cable worked but the other would not. Once I replaced the TRS cable with a TRRS cable both halves worked perfectly. I could be the exception to the rule but I doubt it since most split keyboards require TRRS. I wonder if the build guides are wrong in stating that either TRS or TRRS cables will work.

foostan, 2019-06-03:
The Crkbd can use TRS cable.

Please check kicad data.
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

vxid, 2019-07-01:
I had the same issue as @cgrange. TRS did not work, TRRS did.

gelpicr, 2019-07-13:
I actually had the same issue with my build, but I was able to get it running by plugging in the TRS cable then connecting both sides to USB. It's obviously not ideal, but i'm still waiting on my TRRS cable to come in the mail. Glad to know I wasn't the only one and that TRRS should fix my problem as well.

note: I'm using the cherry hotswap version rather than the classic corne if that makes any difference.

tominabox1, 2019-08-21:
I have also tried using a TRS cable with no success - Power was provided but appeared to be no data.

foostan, 2019-09-30:
How long your TRS cable?
I saw an issue where left and right communication fails when using a cable that is too long.

tominabox1, 2019-09-30:
I'm using rev 1.1 boards if that has anything to do with it. The cable I
used is only 3 feet I think.

On Sun, Sep 29, 2019, 8:17 PM Kosuke Adachi <notifications@github.com>
wrote:

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

foostan, 2019-10-02:
https://github.com/qmk/qmk_firmware/blob/master/keyboards/crkbd/serial.c#L137

Please try changing `SELECT_SOFT_SERIAL_SPEED` value.

tominabox1, 2019-10-03:
Trying on my dual pro-micro board now and it is actually working with a short cable... I'll have to check on my other one!  I didn't change any config options.

tominabox1, 2019-10-14:
Confirmed TRS works on both of my cornes without changing any settings. I believe I had a bad solder joint on the one board I was having issues with.

foostan, 2019-10-18:
I’m glad working your corne. Thanks.

BeaRRRRR, 2020-03-06:
I got my hotswap cherry corne working with a 3 meter TRS cable, so I think that cable length isn't really important.

Brammm, 2020-09-08:
@cgrange did you ever get TRS working? I have a high quality Rode TRS cable but experiencing the same issue.

vguerci, 2020-09-08:
After diagnosing a similar issue, I can confirm that `TRS` should work. Thus there is an issue that happens easily, if you short the TRRS Socket pads there: 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

When A-D are shorted, this is not an issue with TRRS cables but is one with TRS cables that short B-D pads. VCC and data are then shorted.

I hope that helps.

Brammm, 2020-09-08:
Hmm, I'm using a Corne Cherry PCB but with some slight modifications (among which to use RGB LEDs with legs that solder more easily) and on mine, those 4 connections of the TRRS jack are in one line... I'll get in touch with the dude that modified the PCB's.

vguerci, 2020-09-08:
The Worldspawn's "easy LED" version I guess. This one short by design the A-D pads and cannot work with TRS cables.

Closed 2019-10-18.

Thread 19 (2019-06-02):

Corne Classic v2.0 OLED Power?

taylorcoffelt, 2019-06-02:
I have the v2.0 boards of the Corne Classic, and I can't seem to get the VCC pin for the OLED to have power.
I have the top OLED jumpers soldered on both sides. I'm currently using the Elite-C, and the test keypresses do work. Following the traces on the board, KiCad design, and schematic, it _should_ have power.
 Anyone else have this issue?

foostan, 2019-06-03:
> I have the top OLED jumpers soldered on both sides

Maybe it's mistake. You should solder one side.
Please check [buildguide](https://github.com/foostan/crkbd/blob/master/corne-classic/doc/buildguide_en.md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).

taylorcoffelt, 2019-06-10:
My apologies, I was unclear in that statement.
I have soldered the OLED Jumpers on the top side of the PCB for both left and right boards, according to the instructions in the buildguide. I'm not seeing anything that is different in my setup, besides the fact that the buildguide is for v1.1 of the board, and mine is v2.0

foostan, 2019-09-30:
> Anyone else have this issue?

No, I have not see this issue.
Please show me your assembly.

Closed 2020-04-18.

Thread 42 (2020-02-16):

Design Review: Recessed RGB

NellyWhadsDev, 2020-02-16:
Hey there,

I'm working on a keyboard of my own and was wondering what your motivation was for recessing the RGBs into the board, as opposed mounting them on the surface. Was it mainly for building ease, so that builders don't have to fuss with actual SMD work, or was there another reason?

Also, if the LEDs are recessed into the board, does it affect their light distribution into the switch itself? I just can't seem to find a side-by-side comparison of how the light disperses into the switch on this board vs a non-recessed one (using the same camera, angle. etc.)

Thanks! And awesome keyboard you have here!

BenRoe, 2020-02-18:
I guess it‘s because if the per-key leds are surface mounted the switch wouldn’t fit.

<sub>Sent with <a href="http://githawk.com">GitHawk</a></sub>

NellyWhadsDev, 2020-02-21:
There are Keyboards with surface mounted LEDs which do fit underneath keys. Perhaps it was to support the different led position between MX and Choc switches?

foostan, 2020-02-22:
Crkbd forked from [Helix keyboard](https://github.com/MakotoKurauchi/helix) that has per-key LEDs(SK6812MINI). SK6812MINI is control RGB and brighting simply with serial cascade without other controller. But I and most of builder think assemble parts so difficult.

Do you know small LED that can control RGB and brightening without another controller?

foostan, 2020-02-22:
Maybe I will use [YS-SK6812MINI-E](https://yushakobo.jp/shop/ys-sk6812mini-e/) if re-design crkbd. It's like SK6812MINI and assembling to be easy.

NellyWhadsDev, 2020-02-23:
There seems to be some confusion on my end; My understanding was that most keyboards had LEDs installed on top of the board, like this: https://www.1upkeyboards.com/shop/controllers/1up-rgb-pcb-hse/

But upon further digging, it seems most of these 6812s are actually installed into the PCB when it comes to per-key implementations. My mistake.

BenRoe, 2020-02-23:
YS-SK6812MINI-E look promising. @foostan do they have a different pinout or why they are not compatible with the current pcb?

<sub>Sent with <a href="http://githawk.com">GitHawk</a></sub>

foostan, 2020-03-03:
YS-SK6812MINI-E is a not compatible with SK6812MINI.

Closed 2020-03-03.

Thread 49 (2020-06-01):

Support for Kailh Choc V2 Switches

connorbowden, 2020-06-01:
Kailh has released a second version of low profile switches, called Choc V2’s. From what I’ve read, the pin layout is different from both the other version of choc low profile switches and cherry’s low profile switch, which would require a new PCB layout. Will there be an update for Corne’s PCB to support these switches?

Edit: link to the switches  https://www.kailhswitch.com/news/kailh-choc-v-32057417.html

filoxo, 2020-06-11:
Duplicate of #41

connorbowden, 2020-06-12:
@filoxo Link to the first version release of Kailh's low profile switches: https://www.kailhswitch.com/mechanical-keyboard-switches/low-profile-key-switches/dark-yellow-switch.html

Link to the 2nd version of Kailh's low profile switches (the ones I referenced) : https://www.kailhswitch.com/news/kailh-choc-v-32057417.html

foostan, 2020-07-29:
I'm try prototyping for Choc V2.
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

MarkCampbell1970, 2020-10-29:
Hello, Did you have any luck with prototyping PCB. I actually bought some of the choc v2 switches thinking that they would fit on the regular Kailh PCB for low profile switches and obviously that didn't work out. I am not able to find any other board that supports it. I was just wondering if you still planning to making a prototype and if you plan to make it public.
Thank you!

CMorooney, 2021-04-28:
> Hello, Did you have any luck with prototyping PCB. I actually bought some of the choc v2 switches thinking that they would fit on the regular Kailh PCB for low profile switches and obviously that didn't work out. I am not able to find any other board that supports it. I was just wondering if you still planning to making a prototype and if you plan to make it public.
> Thank you!

Same here -- crkbd is my favorite layout/board and I am really looking forward to putting these switches on one! Any news on official compatibility?

keyboard-magpie, 2021-04-28:
Corne light in the main repository has support for choc v2 now @CMorooney https://github.com/foostan/crkbd/tree/master/corne-light

CMorooney, 2021-04-28:
ah, great, thanks @keyboard-magpie ! Perhaps this issue should be closed?

markstos, 2021-04-28:
I'm building a Corne Light with Choc v2 switches now. It's currently with a builder who is debugging some issue. I got my PCB from a Redditor who had several of the prototypes printed for himself and sold one to me. I don't think he has more. (And was located in Sweden, so the shipping cost to the US was about the cost of the PCB).

Closed 2021-10-30.

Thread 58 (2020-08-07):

RGB footprint pin marking is on 4 rather than 1

DaneEvans, 2020-08-07:
Standard engineering would have the marking on the footprint on pin 1 -

this works if you are using the build logs, but if you know what you are doing, and go to the data sheets, you end up realising that the geometry just doesn't work. Then you go looking at the build documents, and realise that for some reason convention was thrown out the window, and the pin 1 marking is actually on pin 4 - Vdd

Changing it now is probably not worth the additional headaches, and as I said, the geometry doesn't work, so it's unlikely to fry LEDs, this is more here in case someone else goes looking for an answer.

WernerFS, 2020-10-15:
I have been working in a fork version of this same keyboard and doing the BOM I discovered this. I almost lost my mind when I checked the documentation. I will correct the footprints when I have time and will upload in a personal fork :) this is an amazing keyboard that has a lot of potential.

WernerFS, 2020-10-15:
> I have been working in a fork version of this same keyboard and doing the BOM I discovered this. I almost lost my mind when I checked the documentation. I will correct the footprints when I have time and will upload in a personal fork :) this is an amazing keyboard that has a lot of potential.

Disregard this, I realize there are several footprints and the one in this datasheet **https://cdn-shop.adafruit.com/product-files/2686/SK6812MINI_REV.01-1-2.pdf** so I guess you should be careful when sourcing your components haha :D

DaneEvans, 2020-10-15:
That might explain the confusion, though that datasheet is an abomination.

The pin 1 index is visible on the diagram of the LED, yet that pin is
labelled pin 3.

This it the problem with knockoffs.
An alternative might be to add the notch on the silkscreen, as it appears
to be consistent.

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

agusdmb, 2022-10-12:
this is the same as #166

DaneEvans, 2022-10-13:
No it's not

On Thu, 13 Oct 2022, 8:47 am Agustin Marquez, ***@***.***>
wrote:

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

agusdmb, 2022-10-13:
> No it's not
> […](#)
> On Thu, 13 Oct 2022, 8:47 am Agustin Marquez, ***@***.***> wrote: this is the same as #166 <#166> — Reply to this email directly, view it on GitHub <[#58 (comment)](https://github.com/foostan/crkbd/issues/58#issuecomment-1276770277)>, or unsubscribe <https://github.com/notifications/unsubscribe-auth/AFIRN4OJ7JVWIPOOMCO2Q3DWC4WXRANCNFSM4PXS4RNA> . You are receiving this because you authored the thread.Message ID: ***@***.***>

:man_facepalming: you are right... i miss read this somehow... now i just read it again and realized it.. i deleted my comment to avoid having the links between the 2 separated issues

DaneEvans, 2022-10-13:
All good.
I figured it was something of the sort

On Fri, 14 Oct 2022, 2:10 am Agustin Marquez, ***@***.***>
wrote:

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

Closed 2023-11-11.

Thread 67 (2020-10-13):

CRKBD doesn't work

mralkofgihter, 2020-10-13:
Hello, have an issue with my corne keyboard.
I've got cherry v2.1 pcbs.

I soldered first PCB, flashed my pro micro board and the problem is, that pro micro doesn't work when plugged to pcb.

I've checked all the  soldered joints, diodes, but can't find what's the cause of it.

Maybe someone got the same problem? Help is strongly needed.

Today I'm going to solder the seconds pcb to check if the problem will appear again.

Thank you.

Also I'd like mansion, I tried to plug arduino with voltage connected. And arduino turns off after raw pin is connected.

keyboard-magpie, 2020-10-13:
Come join the pastry keyboard discord server (foostan's server) and we can talk through issues and see pics.

https://discord.gg/8tmn7p

foostan, 2020-10-21:
Thank you for building and your information.
Assembly problems are supported by the discord server.

Closed 2020-10-21.

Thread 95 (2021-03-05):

Corne Chocolate Top Plate drill layer vs outline issue

yourfate, 2021-03-05:
I'm about to have PCBs and plates for the corne chocolate produced by JLC, and I sent them the gerber files from the release page here:

https://github.com/foostan/crkbd/releases/tag/corne-chocolate-v2.1.0

Now I got the reply that there are cutouts in the drill layer that get cut off by the outline layer, see JLC email here:

```
Hi Sir,

Well got your order with many thanks~

Sorry to bother you, but there is an issue that we want to confirm with you before proceeding.

As shown below, the slots on the drill layer will be cut off by the slots on the board outline layer,

is it normal to cut them out per the board outline layer as non-plated slots?

Your early reply will be highly appreciated!

Thank you so much!

```

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

I have for now instructed them to just cut it at the outline as they suggested. We'll see how it turns out.

martinmunk, 2021-09-22:
Hi @yourfate
I'm considering trying my luck with making a Choch version as well, and maybe also use JLC.
Did you end up getting the issue resolved?

yourfate, 2021-09-22:
Hi @martinmunk, sorry for now following up on this issue.

Yes, they delivered the plates and they worked fine. You can see the result here:
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

I would recommend using thinner PCB for the plates than I did, as 1.6mm is too thick for the switches' clamps to reach below. It works, but it would be neater using 1.2mm.

Side note: You can specify "Remove Order Number" at JLC, I forgot to do that, and now have order numbers on my plates and PCBs.

pavel-rakhmanov, 2021-11-26:
Also faced with this issue while ordering corne-chocolate-v2.1.0 plates from JLC PCB but with a slightly different wording:

> As shown below, for all square slots we can only make them non-plated, is it ok？

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

saeedb3r, 2022-12-17:
Hello everyone
I am currently in the process of building a corn chocolate keyboard, and I have received a message from the PCB manufacturer regarding the top layer. I apologize for my lack of knowledge on the subject, but I was wondering if you could kindly help me understand what is required and how to respond to the manufacturer's message. Your expertise and guidance would be greatly appreciated.

-----------------------------------
our engineer has reviewed your file and order detail, here are questions to confirm :
1.For the square slot, should we produce as plated-slot?
2.For the slot size of drill layer, which is inconsistent with the Edge-cut layer, should we produce according to Edge-cut layer  or drill layer ?
-----------------------------------

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

Closed 2021-09-22.

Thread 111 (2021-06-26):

Board outline is missing or malformed.

waymond91, 2021-06-26:
Fine work! I love the project and I'm super excited to build my own.
I am trying to generate gerber using KiCAD 5.99 however I cannot get the edge cuts to close.
So that none of the 3d renderings by KiCad or manufacturers seem to come out correctly.
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

Any advice would be great :)

641i130, 2021-08-18:
They still haven't solved this huh.

foostan, 2021-08-24:
Thank you for reporting!
I fixed the classic, and cherry is no problem.
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

Rendering results from some PCB vendors may not display correctly. For example, the display of jlcpcb is different from the result of kicad.

LoyalPotato, 2022-02-10:
Hey, I'm still getting the pcb like the first picture in the issue.
I'm using kicad v6.0.1. When I open the plot menu, I get a
> Global solder mask minimum width and/or margin are not set to 0. Most board manufacturers expect 0 and use their own constraints for solder mask minimum width.

I'm not sure if it has anything to do with the issue (I don't really know what it means, because I'm new to this, just trying out).
I generate the drill files and then plot.
Then upload the .zip into jlcpcb and it still shows with filled areas, like so:

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

Closed 2021-08-24.

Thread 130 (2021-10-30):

Update the project for v4

foostan, 2021-10-30:
## Summary

Update a lineup

- Corne Cherry hotswaping type
- Corne Cherry soldering type
- Corne Chocolate hotswaping type
- Corne Chocolate soldering type

Corne Light and Corne Classic are about to be discontinued.
The concept of updates is

- Eliminate the Pro Micro and put the MCU(RP2040)
- PCBA support (this is left to each shop's policy, but we will try to make the parts layout PCBA-ready)
- Change the key pitch from 19mm to 19.05mm to make it more standard
- The original location of Pro Micro has been expanded to accommodate additional keys and rotary encoders.
- Not compatible with v3

## TODO

### Enhancement
- https://github.com/foostan/crkbd/issues/70
- https://github.com/foostan/crkbd/issues/131
- https://github.com/foostan/crkbd/issues/139
- https://github.com/foostan/crkbd/issues/135
- https://github.com/foostan/crkbd/issues/147
- https://github.com/foostan/crkbd/issues/150
- https://github.com/foostan/crkbd/issues/166
- https://github.com/foostan/crkbd/issues/33

### Fix
- https://github.com/foostan/crkbd/issues/123
- https://github.com/foostan/crkbd/issues/58
- https://github.com/foostan/crkbd/issues/36
- https://github.com/foostan/crkbd/issues/133
- https://github.com/foostan/crkbd/issues/129

foostan, 2024-03-16:
https://github.com/foostan/crkbd/releases is publish

Closed 2024-03-16.

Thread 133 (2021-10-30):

Larger M2 spacer hole on PCB to accomodate M2 Nylon Hex Type

saikocat, 2021-10-30:
Currently, the M2 spacer PCB hole can only accommodate brass type spacer (around 3.14mm diameter).

The nylon hex type (some people uses it for color coordination of black/white pcb/plate) like this one https://www.aliexpress.com/item/1005002263436936.html . This nylon spacer has 4.0mm diameter and can't go through the current hole size (4.3mm drill hole).

Even the Corne R2G edition has way larger hole for more spacer choices (https://groupbuys.mechboards.co.uk/wp-content/uploads/2021/07/HR2G_0000_20210603_112634.png).

Let me know where do you want to consolidate the discussion. Here or at https://github.com/foostan/crkbd/discussions/132

Cheers and thanks!

foostan, 2024-03-16:
already fixed at v4

Closed 2024-03-16.

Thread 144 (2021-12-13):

ambient LEDs (WS2812B) turn white on power on (Corne v3)

joric, 2021-12-13:
## Describe the issue

When I turn RGB off with an RGB toggle, the next power cycle (replugging the cable) turns the 6 ambient LEDs bright white. They can be turned off again by double RGB toggle but it's very annoying to do on each power on. Per-key LEDs are not affected.

## Expected behavior

Ambient LEDs supposed to stay off if RGB is disabled by the shortcut but they turn on.

## Hardware
Hardware is the original corne-cherry-v3.0.1 with 6 underside LEDs (WS2812B) and 21 per-key LEDs (SK6812MINI-E).

## Firmware
Firmware is the latest QMK, December 2021, default keymap (official builds including VIA builds are also affected).

## Additional info

* It looks like hardware issue because only WS2812 LEDs are affected, do I need decoupling caps there or something?
* I can't check if I have bad Pro Micro wifh a faulty/bad power circuit but it's a green one, I don't have another one.
* It also needs to set max brightness to 120 (it trips polifuse and hangs otherwise), stock firmware has that already.
* It may be unoriginal WS2812B LEDs I desoldered from an old RGB strip but they work fine except that one issue.
* It maybe can be fixed by turning LEDs off on startup but official firmware doesn't do that. Should we add that?

Related post on reddit: https://redd.it/p7dha4 both halves are affected so there's no random dry joints, it's rather QMK/LEDs.

foostan, 2021-12-26:
@joric Please join the discord server https://discord.gg/SHVc2crgw8 and you can get support here.

joric, 2021-12-26:
Oh I've been told they may be RGBW so I got to try adjusting the firmware to RGBW (or replacing them with RGB ones).

joric, 2021-12-26:
I tried #define RGBW 1 in config.h and it didn't fix the issue on WS2812b's but it severely broke the colors on SK6812MINI's, so this is still open. I'll get better promicros next week and I'll try them maybe it has something to do with the green promicros power scheme/voltage drop or something.

joric, 2021-12-29:
Nope, checked with Purple USB-C promicros, same behavior. Probably have to set them to black on init.

joric, 2022-01-15:
OK I replaced the LED's. Looks like init is different for the different chips, these things are complicated. It works now.

Video:

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

I desoldered the old ones from the old RGB strip:

Old LEDs: https://www.aliexpress.com/item/32808513592.html
New LEDs: https://www.aliexpress.com/item/32623583544.html

Rear side is also different:

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

Closed 2022-01-15.

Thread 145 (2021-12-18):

staggered pinky like kyria with kailh choc

rnyPlanet, 2021-12-18:
staggered pinky like kyria. it can turn out to take as a [basis](https://github.com/foostan/crkbd/blob/main/corne-light/doc/v2/buildguide_low_edition_en.md)?

will it be possible to use kailh choc without hot swap for [this keyboard](https://github.com/raychengy/fifi_split_keeb#fifi-keyboard--%EF%B8%8F) which is based on the crkbd (I would try to do it myself - but I have no knowledge) ?
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

and can you explain what these holes are for?
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

@foostan maybe it won't take you long

keyboard-magpie, 2021-12-18:
In your first picture, no, that will require redesign for choc specific sockets.

In your second picture, the 3 holes you have circled are for MX, Alps, and the rightmost is the extra leg for choc v2 switches.

rnyPlanet, 2021-12-18:
> In your first picture, no, that will require redesign for choc specific sockets.

Is it possible, on the basis of the second board, to make a staggered for the pinky as in the first photo? (no sockets - to solder the switch to the board)

keyboard-magpie, 2021-12-18:
It wouldn't be a crkbd then...

Its open source for a reason :) modify away.

rnyPlanet, 2021-12-18:
> It wouldn't be a crkbd then...

I wore here because I like crkbd) but I would like a little improvement

> Its open source for a reason :) modify away.

I have no knowledge (

keyboard-magpie, 2021-12-18:
I would invite you to come and talk on the low profile keyboards server, we have a #design channel [https://discord.gg/69UM9sQF8q](url)

rnyPlanet, 2021-12-18:
> I would invite you to come and talk on the low profile keyboards server, we have a #design channel [https://discord.gg/69UM9sQF8q](url)

oh, interesting. I'll take a look)

foostan, 2021-12-26:
@rnPlanet Thank you for sharing your design, I hole you challenge yourself to design your own 👍
@keyboard-magpie Thank you for everything 🙏

rnyPlanet, 2021-12-26:
> I hole you challenge yourself to design your own

thanks😁  could you look with one eye and tell me if it will work?) https://github.com/pashutk/chocofi/pull/2, @keyboard-magpie or maybe you have knowledge)

Closed 2021-12-26.

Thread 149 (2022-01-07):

Improved Bluetooth Support

cburg, 2022-01-07:
While the Corne supports the Nice!Nano, there isn't support for an on-off switch or a battery connector, and battery support is quite limited. I really do not like the idea of a permanently soldered battery.

I'm willing to attempt to make these changes myself, but I've never used KiCad before and my time is quite limited.

# LiPo Battery
- Recommendation: 301230 (3mm x 12mm x 30mm) --> 501235 (5mm x 12mm x 35mm) depends greatly on socketing / wire routing. Must be >= 100 mAh for the Nice!Nano.

The Nice!Nano comes with a 301230 (3mm x 12mm x 30mm) 110 mAh battery. This fits under the Nice!Nano if you socket it *with* a taller pin row. For reference I used the mill-max 335 low profile interconnect to get an extra 0.7mm to account for the LiPo wires.
https://www.mill-max.com/products/socket/335-xx-xxx-00-160000/335-40-132-00-160000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

A taller pin row (e.g. mill-max 800 interconnect) should accommodate a 4mm thick battery. And an even taller pin row (e.g. mill-max 350 interconnect) should accommodate a 5mm thick battery.

This allows for quite a larger range so people can source batteries easier. For example, the Nice!Nano comes with 301230, but in the U.S. it's easier to source a 401230 from adafruit.

One more possibility, would be to have a cut-out under the microcontroller to support routing a battery under the PCB for thicker cases. I think this is going to be questionable since hotswap sockets take 2 mm of space, and for soldered switches, you need space / protection to prevent the exposed pins from damaging the lipo battery skin. Accommodating that extra space will mean ~9.1mm between the bottom of the PCB and a desk (2mm hot swap + 3mm battery + 1.6mm bottom plate + 2.5mm bumper). Any additional shielding will increase that thickness. But, this would allow batteries that are > 500 mAh and should offer months between charges.

# Battery Connector
- Recommendation: Molex PicoBlade

For the battery connector, I think supporting the Molex PicoBlade system would be best. These are quite compact, and you can use one battery connector to connect to both board mount headers as well as cable to cable connectors. The board mount headers have both through-hole and surface mount and appear easy to hand solder. These connectors support 26-32 gauge wire with a single housing (two different crimp sizes though) and will cover the range of LiPo batteries I have come across that will fit on the Corne.
https://www.molex.com/molex/products/family/picoblade

# Power Switch
- Recommendation: 7 pin 3 terminal surface mount right angle slide switch.

These seem pretty commonly used in the mechanical keyboard market (e.g. Nice60 and Ferris Sweep). They are quite thin at only 1.42mm high which makes them thinner than the hot-swap sockets as well as rubber bumpers / foam pads. They are also quite easy to source.

# Placement of Parts
My main goal here is to keep the same form factor so existing cases will mostly fit. There are 2 layouts I'm thinking of. A Full Layout which retains full capabilities (e.g. one board for either bluetooth or wired), but has much tighter fits for components. A BLE only layout which removes unnecessary components (TRRS + OLED) for better spacing.

- LiPo:
  - **Full Layout**: Under the Nice!Nano. The board is 35 mm long if the LiPo goes under the USB connector as well or about 30 mm otherwise.

- Power Switch:
  - **Full Layout**: Bottom of the board under the USB connector. These switches are only 1.4mm and are thinner than the hot-swap sockets. This is the positioning used by the Ferris Sweep. Looking at pictures, this positioning should be compatible with the boardsource LP aluminum case (I have one on order and will test), and it may be compatible with the IMK case from keyhive. I don't have a good way to verify though. For bare plates with rubber bumpers or the foam pad there will be enough clearance as well.
  - **BLE Only Layout**: Layout which removes the TRRS jack and OLED headers. Power switch would then go next to the reset swtich.

- Battery Connector:
  - **Full Layout**: Move the OLED header to be flush with the TRRS jack, and place a PicoBlade right angle connector with the opening facing the microcontroller. This is going to be a very tight fit, but I think would work. This placement will only be compatible with 30mm long batteries, and the battery may also need to sit under the USB connector to avoid too much stress on the wires at the terminals.
  - **BLE Only Layout**: Layout which removes the TRRS jack and OLED headers. PicoBlade right angle connector will occupy the space where the TRRS and OLED headers were.

foostan, 2022-04-07:
@cburg I do not have Nice!Nano so I cannot verify this. Are there any other examples of implementations or published data that would be helpful?

cburg, 2022-06-20:
@foostan, there are a few references for wiring

* **Ferris Sweep** (switch under Nice!Nano)

    https://github.com/davidphilipbarr/Sweep/tree/main/Sweepv2.2

* **Keyboard Kitchen** (hacked switch onto TRRS pads, looks like what @ykz89  did on their build)

    https://keyboard.kitchen/2021/03/28/build-log-corne-chocolate-v2-1/

* **Nice!Nano Schematics**

    https://nicekeyboards.com/docs/nice-nano/pinout-schematic/

I'm partial to the Sweep's implementation since it will still allow a single USB design.

HubbeKing, 2022-06-20:
To be honest, if you put a power switch footprint on the board, there's not a ton of reasons to also add a battery jack. Routing the power switch to a pair of througholes for B- and B+, like the Ferris Sweep does, is perfectly fine. Replacing the battery should be a fairly uncommon occurrence, and desoldering a pair of wires to do that isn't too bad IMHO.

sungo, 2022-06-20:
@cburg I've been playing with some options and, regardless of height concerns, I think the bigger problem is the connectors themselves. JST-PH, picoblade, all of them are really tight fits for the battery cable itself. I worry about folks tearing off the connector while trying to unplug the battery. I've pulled the wires out of a jst or picoblade a few times. (Admittedly my grip slipped.)

To @HubbeKing 's point, if B-/B+ are exposed via through holes, folks can connect however they want. I can attach a jst-ph, you can attach a picoblade, other folks can direct connect.

it should be pretty easy to fit a pair of through holes in the v3. More challenging in the v2 based classic for choc folks but my understanding is that the v4 choc board will be based on the v3.

cburg, 2022-12-23:
So, I recently discovered this:

https://github.com/petejohanson/crkbd/tree/board/corne-ultralight/corne-ultralight/pcb

Looks like the creator of the ZMK firmware went and modded the corne-light board to not only support a JST battery connector and power switch, but also the new Nice!View display header which requires 5 pins instead of the standard 4:

https://nicekeyboards.com/nice-view/

I would still prefer a single board that could support both bluetooth and wired, but there's simply not enough space for both the JST header and TRRS connector.

At the end of the day, this is an excellent alternative.

Closed 2023-11-11.

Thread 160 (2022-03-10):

Question: Milling configuration for PCB production

DLFW, 2022-03-10:
Sorry for misusing the Issue tracking for a question, but I don't find an answer anywhere else.

For the tight cutout of the SK6812MINI-E footprint, what milling drill diameter is necessary for PCB production to have the LEDs fit into the cutout?

I saw that most PCB-manufacturers don't offer milling diameters below 1mm without extra costs. I guess that would not work with this footprint. What diameters have been used successfully?

BTW: PCB-production hints in the readme would be very helpful. :)

Thanks and thumbs up for the great board!

foostan, 2022-04-07:
@DLFW  I have ordered PCBs from various factories and have never had a problem with LEDs. I have never seen any similar reports, so I don't think there is any problem.

Closed 2022-04-17.

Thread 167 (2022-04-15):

About acrylic sheet thickness of corne-cherry

LuckyFishGeek, 2022-04-15:
PCB: corne-cherry
plates: common

What is the thickness of acrylic ? Sorry I'm a newbie asking very elementary questions!
Thanks for the help

kjunuh, 2022-04-15:
Generally non-acrylic plates are 1.5mm as that's what switches are normally designed to snap into, but for acrylic people normally recommend going with 3mm because 1.5mm acrylic cracks very easily. The trade off is that the switches won't snap into the plate if you go with 3mm. Either is viable but you do have to be extra careful with 1.5mm plates.

LuckyFishGeek, 2022-04-15:
> Generally non-acrylic plates are 1.5mm as that's what switches are normally designed to snap into, but for acrylic people normally recommend going with 3mm because 1.5mm acrylic cracks very easily. The trade off is that the switches won't snap into the plate if you go with 3mm. Either is viable but you do have to be extra careful with 1.5mm plates.

Thank you for your kind help and wish you a happy life

Closed 2022-04-15.

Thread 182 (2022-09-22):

Acrylic Upper Mid Plate Is Missing Space For Switch Teeth

alexmadeathing, 2022-09-22:
The [sandwiched upper mid acrylic plate](https://github.com/foostan/crkbd/blob/main/plates/cherry%2B/top-middle.ai) contains no space in the 14x14mm switch holes for the switch panel mount teeth to grip onto the FR4 top plate. So the switches may fall out, especially when removing keycaps.

I've hacked together an STL with some cutouts (Reviung plate shown below, but this applies to Corne too) which has enabled me to print my own upper mid plate, but sadly I don't have Illustrator, so can't submit a PR to correct the issue at source.

I'd like to suggest that something like the cutouts shown below is applied to the Corne upper mid plate, so that the switches can grip the FR4 correctly.

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

foostan, 2022-11-22:
I think your suggestion is correct, but I don't think middleware is needed for the FR4 sandswitch keyboard. The file you are referring to is not active. Thanks!

Closed 2022-11-22.

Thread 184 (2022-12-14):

Right part from crkbd wont work anymore.

Mariotpan, 2022-12-14:
Hi I was using my Corne Keyboard and it worked nicely, but after I tried to change some funcionalities on the software and flash it back to crkbd the right hand part stopped working.
The leds still turn on when I plug it into my computer but nothing happens when I press any keys from the right part.
I tried to flash a default software from VIA but the right part wont work anymore.
I have no clue of what can I have done wrong or how can I fix it, idk how could I maybe reset it or install a default and working flash
Help

cowboyliao, 2023-02-08:
I am making a corne-chocolate now, had done soldering chips work, then, I test the key by short with via website.
Here is issue I have, the left hand is typec, and the right hand is mircousb. But I found that when I connet the left, typec can be used, but the right hand did not respond. When I connet right, both sides can be used, but the left and right key positions are reversed.
I build the firmware myself defaultly, using Atmega32U4.
I thought it's the issuse by bootloader? but seller say he do the bootloader before.

What should I do?

cowboyliao, 2023-02-09:
I move to windows and flash the firmware by qmk toolbox with the default firmware you give, still the issue:
plug left, left work, right not work. plug right, left and right both work, but reversed.
how could I fix it?

waffle87, 2023-02-18:
The issue of right half not working when USB is connected to left, but both halves working when USB is connected to right is very strange. But the halves being reversed when the USB is connected to the right is expected, as the firmware expects the USB to be connected to the left half by default. You can change this by [setting handedness](https://docs.qmk.fm/#/feature_split_keyboard?id=setting-handedness) appropriately, then recompiling the firmware and reflashing both halves.

Aristolon, 2023-05-06:
I ran into a similar problem. Every time the keyboard works fine after plugging the typec back in, but after a while the right part doesn't work (the left hand is the main hand by default).

SozinovD, 2023-08-19:
This line should be added to `config.h` file
```
#define SPLIT_USB_DETECT
```
P.S. It took about 3 hours for me to figure this out. Please fix it in main repo
This link helped me a lot https://github.com/foostan/crkbd/issues/170#issuecomment-1104831554

enorfelt, 2023-08-31:
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

Hade the same issue. This worked for me! Thanks m8!

carl-ranson, 2023-10-06:
I'm having the same problem even with the firmware that @SozinovD  posted (as well as all the others I tried)
I'm thinking it might be a hardware fault in my case.

Can anyone shed some light on how the controllers know which side of the keyboard they're on? Its the same firmware on both, so either it's a master/slave setup or there's a pin on the mcu that is tied high/low or something.

foostan, 2023-11-11:
The board with the USB plugged in is master.

BrassBaron, 2023-11-26:
I have the same problem, and putting the line "#define SPLIT_USB_DETECT" in config.h does not help.
Catch is, that both halves worked and after making some changes in keymap (we all know, that this is a never ending evolution... ;) ), right half does not work anymore.  Separately they both behave like left half, that is if I change USB from one half to another, just that the right half is mirrored. I even flashed micro with some Arduino program, to make sure to erase old contents.  I changed the TRSS cable, did not help either. I guess there is some catch in communication protocol between both halves?
Any ideas?

foostan, 2024-03-15:
I'll close it because this issue is not related to design. If you have any concerns please continue at Discord https://discord.gg/aWCZWnS

Closed 2024-03-15.

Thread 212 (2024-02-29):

v4 questions

kuritonasu, 2024-02-29:
First things first, thanks for your awesome work foostan, I've been using my wireless Corne for almost a year now and I love every bit of its design and simplicity! It's my first ortho, first split keyboard and your design motivated me to solder and build it myself from scratch, even though I never soldered SMDs before.

I love the unified look of the v4, but I have a few questions regarding it, apologies if I missed any docs that answer them:

1. Does the v4 support wireless? I guess, firstly does it support a battery? And if yes, I guess the best place for it is where the two new keys are?
2. Secondly, ZMK & RP2040 don't support split wireless keyboards yet if I'm not mistaken, right?
3. Which PCB manufacturer are you using? Do you assemble the board yourself or choose to have the boards assembled?
4. Is it possible to solder the v4 with a soldering iron, or am I right to think that it would be very difficult, especially for parts like the RP2040?
5. Are the "v4 Soldering" versions close to release? No pressure!
6. Judging from the design, you are releasing the v4 only with a non removable RP2040, right? No plans for a removable MCU.

Thanks again, keep up the good work!
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

KacperNapierski, 2024-03-06:
Also will it be possible for new version to be both wireless and wired, as with previous version it wasn't recommended due to way TRRS provided power to other half while battery was built in .

keyboard-magpie, 2024-03-06:
The V4 PCB Foostan has published is wired only due to its on-board microcontroller.

kuritonasu, 2024-03-06:
> The V4 PCB Foostan has published is wired only due to its on-board microcontroller.

Doesn't the RP2040 support wireless? Or does that require components on the microcontroller's board/shield (which is not part of this design)?

keyboard-magpie, 2024-03-06:
The RP2040 on its own is not a wireless microcontroller. Boards like the Pi Pico W have a separate wireless module.

keyboard-magpie, 2024-03-06:
Furthermore to your original points, the v4 will not be hand assembly friendly, unless you have EXTENSIVE reflow soldering experience.

kuritonasu, 2024-03-06:
Thank you for the clarifications 🙏

foostan, 2024-03-08:
> 1. Does the v4 support wireless? I guess, firstly does it support a battery? And if yes, I guess the best place for it is where the two new keys are?

Wireless is not supported. There are no plans to support it in the future. In Japan, there are strict laws regarding wireless, and it is not possible to use the module freely. Since this is an open-source project, I hope that some people will use it as a basis for the wireless version, as was the v3.

> 3. Which PCB manufacturer are you using? Do you assemble the board yourself or choose to have the boards assembled?

Files for the JLCPCB we be available

> 4. Is it possible to solder the v4 with a soldering iron, or am I right to think that it would be very difficult, especially for parts like the RP2040?

Basically, I expect to do PCBA.

> 5. Are the "v4 Soldering" versions close to release? No pressure!

I'll create after release v4.

> 6. Judging from the design, you are releasing the v4 only with a non removable RP2040, right? No plans for a removable MCU.f

Yes. There is no plan for a removable MCU.

WillPower3309, 2024-03-15:
Will 3x5 cases be added?

foostan, 2024-03-15:
I plan to create the case for 3x5

0n3W4y7ick3t, 2024-03-16:
can I use the case for v3?

foostan, 2024-03-16:
No, v4 is not compatible v3

foostan, 2024-03-30:
I'll close this issue. If you have any question and concern, please create a new issue.

Closed 2024-03-30.

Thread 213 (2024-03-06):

four switches on the pcb of the left hand not working

OneCrazyman, 2024-03-06:
I am making a keyboard called corne v3 cherry.

After attaching diode and produino, short circuit all switch parts directly. Left and right both work well, but the four switches on the pcb of the left hand not working. When seen with the naked eye, all are soldered.

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

OneCrazyman, 2024-03-06:
![Uploading KakaoTalk_20240307_023304217.jpg…]()

foostan, 2024-03-08:
The problem with one vertical row not moving is in the connection with ProMicro. Try re-soldering it cleanly.

foostan, 2024-03-15:
I'll close it because this issue is not related to design. If you have any concerns please continue at Discord https://discord.gg/aWCZWnS

Closed 2024-03-15.

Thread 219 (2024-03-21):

Schematic Cleanup + PCB stackup considerations

fabianmuehlberger, 2024-03-21:
Hi,

Since I am looking for a new keyboard, I came across this project.
Looking at the board design files for the Corne chocolate from the main branch, I would suggest a rearrangement of the schematic symbols to a more functional layout.

The schematic should follow general guidelines like:
- Symbol naming/numbering from left top to right bottom,
- Upper left Power, IO
- right side MCU, peripherals (flash, crystal)
- do not cross lines if possible
- PWR labels always Up, GND labels always down
- labels on symbols should sit on the line

see example:
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

I have not checked if the left and right side have significant functional differences, if so, making hierarchical sheets for duplicates would be suggested too, e.g. keys, LEDs, MCU on separate sheets and references to them for left and right side if the components are the same.

Regarding the PCB, I would suggest switching to a 4 layer PCB. Since ground pour is only on the top side with a high number of traces on the top and bottom, as well as layer changes of signal lines, current return paths are VERY restricted. A 4 layer PCB with 2 ground inner layers would make routing easier and improve the board overall.

I made some example changes in the corne chocolate schematic on my [fork](https://github.com/fabianmuehlberger/crkbd)
Please let me know if you are interested in a redesign, if there is interest, I am happy to contribute.

Best Fabian

foostan, 2024-03-21:
Thank you for your suggestion. Please provide evidence to evaluate the validity of your proposal. thank you.

fabianmuehlberger, 2024-03-21:
What do you mean with validity? PCB design is mostly based on guild lines rather than fixed rules.
The parts I mentioned are pretty basic and would apply to most simple PCBs with one populated side.

I found [this guide](https://www.pcbway.com/blog/PCB_Design_Tutorial/How_to_make_clear_and_well_organized_schematics.html) with basic recommendations for the schematic.

[Elegant schematics](https://resources.altium.com/p/creating-elegant-and-readable-schematics)
[schematic checklist](https://resources.altium.com/p/schematic-review-checklist)

A best practices regarding ground can be found [here](https://resources.altium.com/p/pcb-ground-plane-best-practices-your-multilayer-stackup)

foostan, 2024-03-21:
Thank you for sharing. I'll confirm the guide and fix them.

About 4 layer, could you tell me your opinion more. Could you share Pros/Cons?

fabianmuehlberger, 2024-03-22:
Hey, It's not about the guide, these enhancements can be separately applied.

1. Schematic rearrangement/refactor is to make it more concise. The goal is to make it easier to read and debug if there are problems.  Following basic guidelines will help adapt and improve the design in the future and make it more portable.

2. PCB stackup is a big topic itself, and I am not an expert. But 4 layer PCBs are the norm nowadays and have gotten cheap to produce; therefore we can get the advantages over a 2 layer board with basically no downsides. I see no reason for not using a 4 layer board
These are:
- Inner ground layers: generally speaking, you want all traces separated by a ground layer. This helps with **crosstalk** and gives provides a solid **current return path**. With 2 layers, this is only possible when using one side for traces and the other for ground. Obviously, this can only be done on low density boards  (low component count; space for routing).
- Easier Routing: With a 4 layer board, it is much simpler since you can use the 2 inner layers for GND and the PWR bus and use the outer layers for the signal traces. This makes routing easier, since you simply have more space to do so.
- EMI: For commercial products in the EU an EMI/EMC test is mandatory. So far, I have not produced a PCB for the market, but it's a big topic. Following the industry norm wherever you can helps comply with those standards.

Best

foostan, 2024-03-28:
Thank you for sharing. I'll read the docs you shared.

fabianmuehlberger, 2024-03-30:
From your answer, I assume that you are not interested in me contributing to the project.
I close this issue then.

fabianmuehlberger, 2024-11-18:
Since there is an ongoing discussion regarding EMI problems, [#265 ](https://github.com/foostan/crkbd/issues/265#issuecomment-2480519959)  I decided to reopen this issue.
It seems that the concerns in this issue are directly related with the current issues of the hardware.

foostan, 2025-02-09:
I'm currently prototyping with 2 layers at https://github.com/foostan/crkbd/tree/v4_1_1. If this proves stable enough, It'll continue with 2 layers. If this doesn't work, I may redesign with 4 layers as 4.1.2.

fabianmuehlberger, 2025-02-09:
Hey @foostan great to see you are making progress!

I will take a look at your design, maybe I can help improve it here and there.
One thing that I noticed first was the VLED and LED traces intersecting the board south->north and running parallel to the USB lines. There are 2 things to note here. I highlighted those traces.
I took a look at the LEFT board, but the same principle applies to the right side

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

1. Crosstalk: High-speed signal lines can have crosstalk on parallel signal traces. Since you have some USB issues, you might want to reduce the chance as much as possible.
2. Current return path. Since your USB Connection and therefore your GND is in the upper-right corner (left board), you want a current return path from your IC to that area, that is not intersected by traces.

VLED: you could try routing the VLED from the down and left. Making a circle clockwise around the board instead of cutting through the middle,
LED: I am not sure if the order of attached LEDs is important: if not, you could do the same for the LED line, instead of routing top to bottom, you could try to attach the LEDs from the left side.

This would give you a chance to have a solid copper GND from the IC to the USB port, as well as a solid ground layer under the USB lines. Which should help with the EMI issues you are experiencing.

Best

foostan, 2025-02-09:
@fabianmuehlberger Thank you for your suggestion! I'll check later and update it 👍 Thank you!

foostan, 2025-02-11:
@fabianmuehlberger

> This would give you a chance to have a solid copper GND from the IC to the USB port, as well as a solid ground layer under the USB lines. Which should help with the EMI issues you are experiencing.

Is the mean of the VLED and LED improvement proposal pointed out above? I understand it is not good that these lines are in the center of the board and separate GND?

foostan, 2025-02-11:
It's difficult to solve this issue by 2 layer for me. I may use 4 layer for it.

fabianmuehlberger, 2025-02-15:
The reason for the proposed improvements are, as mentioned, for a good current return path. You can read about this in this article.  https://www.protoexpress.com/blog/current-return-path-signal-integrity/ or if you prefer a video https://www.youtube.com/watch?v=lv8CZSc0o-c&t=180s. A lot of what I know is from the altium academy.

To sum it up: Every signal has some (maybe small) current. It follows a path from the power supply to components and then to the ground plane or layer. Some return current will be induced into the ground plane as displacement current!
 Every signal that is not a simple DC signal with some frequency is an RLC circuit (it has a resistance, capacitance and inductance part to it). You can imagine it as a cupping between the signal line and the ground.  This determines the return path of the return current. With high-frequency signals, the return current tends to follow the signal line.

Very loosely spoken: When you "cut" the ground layer with other traces holes, vias etc., you are making it harder for the return current to follow its desired path.

Regarding the USB lines: The second reason for a solid ground is, that not only the coupling between the USB and the GND layer is better. But it also shields the lines from other signals. Your LEDs are also a high-speed signal that can couple with the USB lines and introduce noise.

I highly recommend watching this video https://www.youtube.com/watch?v=VRJI0X-6yTg&t=120s it is an excellent primer for the design of High-speed signals.

Closed 2024-03-30.

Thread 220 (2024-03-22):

Corne Cherry v2 detailed manual needed

set-st, 2024-03-22:
Is any v2 flashing manual exist? I trying found instructions about enabling oled displays. Of course im add `#define USE_I2C` and separate halfs is working well, but then i try connect it by wire and screens not works, and on right side nothing works exept backlight. And will be exelent to be got some details about resistors and jumper to data pin which detached by default.

foostan, 2024-03-28:
- Where did you get the PCB?
- Did you build firmware yourself? (Normally you don't need to change anything)
- Is the cables broken?

set-st, 2024-04-12:
I found short cut on one of i2c pin and data, so it can't work properly. Now i order official pcb.

foostan, 2024-08-04:
It will be closed as there have been no comments for some time. Reopen if necessary.

Closed 2024-08-04.

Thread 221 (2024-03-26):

Add indicator LEDs

jradtilbrook, 2024-03-26:
Can I first just say, the recent v4 release is absolutely awesome. I've been using a corne for about 6 months now and love it! I came here looking to build my own one from scratch and see about a few mods. I love that the MCU is onboard now and that there is the option of 4 more switches. It's exactly what I wanted - just slightly more keys to reduce the layers/tap-dance/etc 👏

I think the only thing holding this back from being the perfect keyboard for me is the addition of some LED indicators. Then there is little need for a display and we can add 4 extra switches 🙌

Is that something you would be open to a PR with?

jradtilbrook, 2024-03-26:
Some extra info that would be useful:
- I suppose adding a mcp23018 to one or both sides (so it allows for left/right master)
  - this is similar to how other keyboards do it
- add a cutout to the top plate so they are visible. I haven't looked closely but perhaps above the outermost thumb switch

foostan, 2024-03-28:
Thank you for your suggestion.

However, I don't plan on adding an indicator because I want to keep the design as simple as possible.

I recommend you fork it and proceed with it as your own project.

jradtilbrook, 2024-03-29:
Thanks for your response. Okay I'll do that 👍

Could you explain a little how to set up kicad for modifying it? Do I need to use the `./pcbs/common` folder to import into kicad somewhere for extra footprints?

Otherwise, how can I start with trying to modify the corne cherry?

jradtilbrook, 2024-03-29:
Oh and another question @foostan; I've looked at the schematic already for the corne and it looks like each switch is wired directly to a RP2040 pin. I thought most keyboards use a matrix for the switches so that they didn't have to use so many IO pins from the MCU. Is my finding correct or am I misunderstanding the schematic?

And if that is correct, are there no more spare pins on the RP2040 to use for indicator LEDs?

jradtilbrook, 2024-03-29:
Okay doing a bit more research it does appear to use "direct wiring"

foostan, 2024-03-30:
> And if that is correct, are there no more spare pins on the RP2040 to use for indicator LEDs?

Ah, yes.

Closed 2024-03-30.

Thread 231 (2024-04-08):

How to order? / Wrong parts placement when ordering from jlcpcb

MaxWinterstein, 2024-04-08:
Love your work, and currently typing this on an old corne <3

I tried to upload the files to jlcpcb but somehow the parts are mostly wrong rotated or misplaced. This happens for both cherry as well as choc. E.g. USB port is floating.

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

There are others on Reddit having this issue too: https://www.reddit.com/r/crkbd/comments/1budyel/comment/kxuc1wx/

Thanks!

foostan, 2024-04-08:
I answered the same question on my server
https://discord.com/channels/715899960327012423/742781449731702824/1225199804477472858

> I don't know the details, but it may be a compatibility issue between the jlcpcb system and the data generated by kicad. The jlcpcb engineers will check and adjust the data, so there is no problem with the way it is.

MaxWinterstein, 2024-04-08:
Thanks, will try to get them to adjust the data.

Sadly, the headphone jack is not in stock, probplaby since a few days already. Do you know any compatible alternative?

foostan, 2024-04-10:
There is no alternative. If you want to change, you need to change the footprint. I'm waiting to be stocked.

RodolfoBar, 2024-04-13:
In my case the engineer is asking me to confirm the placement of the parts. So I was thinking, would it be easier to have a diagram in the documentation/build guide that has the correct placement of the parts so that you can maybe avoid these questions in the future?

RodolfoBar, 2024-04-13:
I'm having a similar issue with JLCPCB. I was wondering if there was any way that I could confirm the orientation and placement of the parts. I realise this might be a bit of a request, however the images that are on the README.md in the root are quite low resolution and I don't have that much knowledge with circuitry to really understand it. Thank you!

Xartos, 2024-04-20:
I'm currently looking at creating a fork that uses [PJ-606-6A](https://jlcpcb.com/partdetail/Korean_HropartsElec-PJ_6066A/C145806) as the audio jack instead. However since @foostan wrote that there's no alternative I'm wondering if there's anything that I'm missing with it that makes it incompatible, of if that was meant that there's no alternative with the same pinout. Because other than the pinout they seem to have similar footprint so only minimal changes to the pcb is required.

foostan, 2024-05-06:
I released https://github.com/foostan/crkbd/releases/tag/v4.1 for the connector issue.

MaxWinterstein, 2024-05-27:
Thanks, I was able to order 4.1 from jlcpcb. They placed all parts correctly - but IIRC I checked and payed all boxes that involved production file verification and confirmation.

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

New connector works fine, currently typing on a v4.1. Thanks for the awesome work!

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

Just had do use white switch holders, the black ones where out of stock at that moment.

kijewskimateusz, 2024-06-03:
Thanks for great discussion there. When ordering my pcb, I have also been asked whether polarities of the components C5149201 are correct or not. (SMD-LED)

Could you please help me understanding if it is correctly applied by the JLCPCB team? Bellow I'm attaching render shared by the team.
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

MaxWinterstein, 2024-06-03:
@kijewskimateusz

Attached the file I accepted for comparison.

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

Even I made MX style, and yours is choc, it can be compared. By looking at the LEDs it looks good to me, as the little triangle needs to be in the marked corner. The real LEDs have some little cutout.

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

giograno, 2024-06-04:
Hei @MaxWinterstein, I am also trying to order the v4.1 with jlcpcb. The sockets and the trrs connectors are rotated/misplaced. As far as I understood, in your case jlcpcb itself managed to correct them, right?

mhanberg, 2024-06-12:
@kijewskimateusz I am facing a similar issue with JLCPCB.

My switches in the mockup they sent look like yours, but i'm wondering, are they upside down? Did you end up getting assembled board and confirmed that that is correct?

Closed 2024-05-06.

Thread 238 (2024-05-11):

Corne V4.1 PCB question.

notPrivate-care, 2024-05-11:
Hey, I am a newbie, don't know anything about pcb, embedded systems, not even pressed a mechanical switch in my life. I have been wanting to use a minimal and split keyboard like Corne since a long time, but money and lack of knowledge has always stopped me. I have a few questions about Corne V4.1:

1) If I am correct, this hotswappable version allows me to order pcb, which has all the components soldered, allowing me to use the keyboard without soldering anything myself, and by just putting the switches and keycaps.

2) Why cant I upload the production files to a local pcb manufacturer? Jlcpcb requires to order at least 5 pcb, and 2 assembly service, which is really really expensive, and I only need 1 keyboard.

Thank you!

foostan, 2024-05-11:
1. Yes, you don't need solder yourself if you order as PCBA and all components will be soldered.

2. What do you mean? I uploaded files for JLCPCB as a sample. So you can order it anywhere.

notPrivate-care, 2024-05-12:
Thank you for your reply!

1. For example, I want to order one keyboard (both left and right) from https://www.pcbpower.com/ . What settings do I have to write? I have no idea.

2. Is a case and plate necessary? if so, where can I order them?

3. I think I should do the cherry mx build as they are widely available and cheaper. Is this correct?

foostan, 2024-05-13:
1. Please read the documentation of pcbpower
2. You can order at jlcpcb or others, but I am not sure about other services.
3. It's depends on you.

foostan, 2024-05-22:
I'll close this issue. Please reply if you have any concerns or questions.

notPrivate-care, 2024-05-26:
> I'll close this issue. Please reply if you have any concerns or questions.

Is it necessary to use plate and case? Can I use with just pcb with rubber feet?

Still-Here-0, 2025-02-15:
Nether of those are necessary (not even the rubber feets). However they will ensure quality and a longevite.

PS: if you do not use plates in your build its keys will be kinda wobbly

Closed 2024-05-22.

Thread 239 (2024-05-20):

microcontrollers

LucasSantos52, 2024-05-20:
Hi, I'm a keyboard enthusiast, I started looking into the subject a few months ago, and in all the customizable keyboards I find on the internet, some type of microcontroller is always soldered onto the board, however, looking at the model on JLCPCB I noticed that on the In the microcontroller region, there is no drilling for the pins, which are usually soldered.

What type of microcontrollers can I use in this version 4?

If I'm not wrong, I need to solder one to the board, right?

I looked through the zip files but wasn't able to find anything

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

Eingin, 2024-05-20:
The [V4 release](https://github.com/foostan/crkbd/releases/tag/v4.0) info answers your question.

The board no longer uses a promicro and instead has a soldered RP2040. This is located near the center of the board by the bottom row.
If you want a 4v, you will most likely have to order it as a PCBA as soldering the microcontroller plus the supporting components is tricky.

foostan, 2024-05-22:
I'll close this issue because it looks already solved.

Closed 2024-05-22.

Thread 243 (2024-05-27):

Killed the rPi by first time powering up with connected TRS cable?

MaxWinterstein, 2024-05-27:
I ordered 5 PCB pairs. 4 Work great, but 1 is missing any signs of life.

When I tested them, I accidentally powered one factory new PCB pair with a connected TRS cable. Is it possible to fry the chip when doing this? Like a brand new chip contains some firmware that has voltage where there shouldn't be any?

gpmontt, 2024-05-28:
Maybe you need to secure the TRS cable. Some diodes can be helpfully here

defekkt, 2024-06-05:
had the same issue, might have been a voltage spike when connecting TVRS cable *after* connecting USB.
turned out it killed the V-USB-> 5V Diode. might be worth checking for you too ;-)

MaxWinterstein, 2024-06-06:
@defekkt can you give me more information on that? Not sure where this diode is, and how to check it. Thx :)

defekkt, 2024-06-16:
1.grab a multimeter, put it in diode mode
2. on a known-working/good board/diode measure the diode in both directions
3. then check it on the faulty board, compare the values (should be different depending on the direction).

here is the diode, next to the usb-connector
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

Closed 2024-10-19.

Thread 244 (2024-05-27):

v4.1 version left part issue

vadimkorzik, 2024-05-27:
hello @foostan
Thanks for the great project.
I am facing a problem.
I have assembled two sets of the keyboard version 4.1 and both have the same problem with the left part. it is correctly recognized as a drive to write a firmware but doesn't work correctly as a keyboard. Windows says "USB device not recognized". Both right parts work fine. The left part connected to the right via trrs doesn't work either. Looks like it is a software issue as it starts showing some info on oled but after a second "hangs" and does not respond to key presses. Flashed via firmware supplied and tried to build it myself with via and default km. Really appreciate your help.

foostan, 2024-05-28:
It is possible to write firmware, right? After writing the firmware, it doesn't get recognized as a keyboard. I'm using the same data and it works fine.

vadimkorzik, 2024-06-03:
hi. turns out it was most likely my fault, i reflowed chips on both plates and they work now. looks like i overheated rp2040 while soldering.

ShionSumeragi, 2024-10-29:
> hi. turns out it was most likely my fault, i reflowed chips on both plates and they work now. looks like i overheated rp2040 while soldering.

Can you tell what temperatures you used? I seem to have made the same mistake

Closed 2024-06-03.

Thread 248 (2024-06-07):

Corne v4: what components to buy?

mhanberg, 2024-06-07:
Hi!

I am new to building keyboards from scratch, so apologies if these are silly questions.

I have purchased some Corne v4.0 PCBs (not pre assembled, and still need to solder on the components, like keyswitch sockets, LEDs, etc.

I was under the impression that I would need to buy some surface mount diodes, but on the PCB, I'm not sure where they would go.

So, that leads me to ask the blanket question: what components are required for this build?

Thanks!

jnfengke, 2024-06-07:
No diodes needed. It uses direct wiring. Everything is listed in the BOM. The TRRS connector might be hard to source. Soldering QFN would be challenging if you aren't very experienced.

Thank you

Ke Feng
________________________________
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

foostan, 2024-06-08:
[RP2040](https://jlcpcb.com/partdetail/RaspberryPi-Raspberry_PiRP2040/C2040) is not assembled too? If yes, you need to prepare the reflow soldering environment.

mhanberg, 2024-06-11:
Due to my inexperience with building keyboards from this level, I didn't realize that the new design wasn't really DIY friendly.

So, I went ahead and put in a PCBA order from JLCPCB.

Thanks for the help!

Closed 2024-06-11.

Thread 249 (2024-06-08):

Corne v4.1 3x5 Chocolate with OLEDs

a-manumohan, 2024-06-08:
I am planning to build a corne with the following parameters.

- Latest version(currently 4.1)
- 3x5 Layout
- Kailh choc switches
- **OLEDs**

I haven't seen any samples of v4 or v4.1 with OLEDs anywhere on the internet yet. The changelog from v3 to v4 mentioned continued support for OLED and I noticed the pin headers on the PCB. But I can't find a top plate GERBER with a cutout for OLED displays. 2 Given options are for mini choc corne and extended choc corne with the cutout for the additional 2 switches.

I do not know PCB design or how to work with kicard. So my questions is

**Do you have any plans to add designs for a top plate that supports OLED?**

kijewskimateusz, 2024-06-14:
@brujoand could you please elaborate about the difficulty of soldering the OLED to the PCB? I think it may be worth opening an issue to add socket for the OLED.

brujoand, 2024-06-14:
@kijewskimateusz there are a couple of challenges, one being that I'm no expert on soldering.

First I learned that I had to trim the legs of the OLED PCB so that it just sit's a couple of mm out from the through hole on the Corne PCB. If not then it's really difficult to get the soldering iron into an angle where it doesn't touch (and melt) the minijack.

The other challenge is that the connecting ring you're supposed to solder the OLED PCB legs to are so thin that it's difficult to heat them properly. This causes solder to only attach to the OLED PCB leg, and this is probably where I broke my board by over heating the PCB while trying to heat the connector.

I tried both with the stock tip and the smallest tip from my Pinecil soldering iron. Maybe someone will have better luck with more professional hardware, or better soldering skills.

foostan, 2025-02-09:
This issue looks to be resolved so I will close it.

Closed 2025-02-09.

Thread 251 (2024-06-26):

Replace the TRRS connectors with USB C connectors

plainoldcheese, 2024-06-26:
The TRRS connectors commonly used on split keyboards are not ideal for their purpose and the PJ-320A connectors are often difficult to find.  There is a possibility to short GND and VCC when disconnecting the TRRS cables while the keyboard is powered  (though smaller with the TX in the middle as on the current layout). USB-C works both directions and the parallel nature of the connections allow for safer connecting and disconnecting.

This is a quick proof of concept. This USB-C connector's footprint ([DX07S016JA1R1500](https://www.jae.com/en/connectors/series/detail/product/id=91780)) allows for the OLED screen to stay where it is and for the location of the connector to stay the same as where the TRRS connector was.

Using the same USB-C that is used at the top of the board would be ideal, but the footprint would overlap with the OLED unless the position of either the OLED header pads or the connector is moved. I was hesitant to move the OLED or position of the connectors as that would make current cases incompatible.

I do think the streamlined look of the dual USB-C connectors with the edge cut at the top of the board looks cool though and that would be ideal for these as well.

I'd be happy to work on a pull request.

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

foostan, 2024-08-04:
This change will not be accepted, as the cases will no longer be compatible. If I had to do it, I would do it in v5. And if I do it, I want to use the type-c parts the same as others. In that case, the OLED will not be compatible.

PaulRopel, 2025-03-07:
Hi,

I am banging my head arround the firmware, I have also replaced the trrs with usb but do have different pins for rx and tx on both halfs and cannot get the connection to fly, any advice:

https://github.com/PaulRopel/kbd_firmware/blob/main/keyboards/crkbd/qmk/qmk_firmware/rev4_1/config.h

br
Paul

PaulRopel, 2025-03-09:
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

all good I was missing the #define SPLIT_USB_DETECT and I realized that I can only assign the pins at compile time not at runtime...

Closed 2024-08-16.

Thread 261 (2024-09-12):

Q : what is bill of material for v4 ?

sadtab, 2024-09-12:
This is my first attempt to build a keyboard, so the question may be n00b.

In the v4 docs : https://github.com/foostan/crkbd/blob/cb4c15542148ac573c55c0e14038ed77c69ca50b/docs/corne-cherry/v4/buildguide_en.md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

What is PCB : it sounds like an assembled  PCB with all diodes, LEDs, controller, sockets etc.

In v2 doc, all these components are listed https://github.com/foostan/crkbd/blob/cb4c15542148ac573c55c0e14038ed77c69ca50b/docs/corne-cherry/v2/buildguide_en.md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

Should I assume BOM of v2 and v4 are the same?

PS : I'm pretty sure github issues is not the right place to ask this question, where is the community forum?

Peace

jfpcarson, 2024-09-12:
BOM is something new for v4, in previous builds you bought it all and soldered it using the guide. The BOM is located here, for the Corne Chocolate: https://github.com/foostan/crkbd/tree/main/pcbs%2Fcorne-chocolate%2Fhotswap%2Fjlcpcb%2Fproduction_files

You upload that alongside the Gerber files.

Discord is here:
https://discord.gg/6qSGrxq7

marleydepew, 2024-09-13:
I'm thinking there is actually an issue with the BOM or CPL. I'm getting an error when I try to upload the Cherry copy to JLCPCB. I noticed the BOM file lists one kind of MX sockets but the CPL lists three different kinds (1u, 1.5u, 1u/rotary). Not sure if this is causing the error.

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

sadtab, 2024-09-16:
Me too

marleydepew, 2024-09-16:
I created a new issue for the errors, since it's a little different from your question.

https://github.com/foostan/crkbd/issues/262

Closed 2024-09-16.

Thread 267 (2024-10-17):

Documentation is really hard for beginners

divad1196, 2024-10-17:
Hi,

First, thank you for the keyboard, it seems really nice.

I have been looking at the documentation and forums for hours but I am not able to understand:
- In the `buildguide_en.md` for V4, I don't see the controller I am supposed to use.
- In the release, with have `pcbs/` and `plates/` folders, but in the `plates/3x6/` folder I also have the `pcb/` folder next to the `svg/`.
  What does that mean ?  If I understand correctly:
  - The SVG files in `svg/`are not used at all (I tried to pass them to my 3D print slicer but I don't think I am supposed to print it from the SVG)
  - I need to pass the GERBER files under `pcb/` to a site like jlcpcb as if it was a PCB, but isn't it really a 3D print ? There are no circuit on it. Is there a reason to make it a PCB ? I guess that the pcb works for both left and right?
  - I am confused with the available files: there is 1 `bottom` file that match all the `top` files ? What is the difference between `cherrymx` and `cherrymx-ex` ? It seems that in the other github's issues, the response is always to use the "cherry" one (the `ex` or the other one?)
  I have a 3D print at home, if possible, I would prefer to print it myself than order it.
- It would be nice to have a link to where we can buy the different components.
- Also (really not that important) why is the `cases` folder missing in the release ?

NOTE: The controller and plate questions are really the main ones.

I see many of these questions in the issues, but I am still not able to understand what needs to be done.
Maybe putting these in a FAQ file would make it easier?

Sorry for all these questions, and I understand that many people here don't need these answers as they are already experienced, but any help would be really appreciated.

Have a nice day.

waffle87, 2024-10-23:
> In the `buildguide_en.md` for V4, I don't see the controller I am supposed to use.

This is because v4 uses an integrated microcontroller (RP2040). This is not something most users solder themselves and I would say is out of the scope of the build guide — it is mostly for general assembly.

If you're looking for a DIY keyboard (soldering a development board style microcontroller like a Pro Micro, and other components like diodes), v4 probably is not right for you — you should look at v3 PCBs.

> The SVG files in svg/are not used at all (I tried to pass them to my 3D print slicer but I don't think I am supposed to print it from the SVG)

Correct. SVG files are not 3D printable — you would need to convert to them to STL files that your slicer understands.

> I need to pass the GERBER files under pcb/ to a site like jlcpcb as if it was a PCB, but isn't it really a 3D print ? There are no circuit on it. Is there a reason to make it a PCB ? I guess that the pcb works for both left and right?

It is not a 3D print. The plates under `crkbd-4.1/plates/3x6/pcb` are if you would like an FR4 plate — it is the same material PCBs are made of and a pretty decent keyboard plate material.

> there is 1 bottom file that match all the top files ?

The `plate-bottom.*` file is a back plate for the keyboard. (Google "FR4 sandwich keyboard" if this doesn't mean anything to you)

> What is the difference between cherrymx and cherrymx-ex ?

`plate-top-cherrymx-ex.*` is if you would like the extra two keys you can optionally install on the v4 PCBs.

`plate-top-cherrymx.*` does not contain the extra keys, and is only the 3x6+3 layout.

> It would be nice to have a link to where we can buy the different components.

Assuming you're referring to v4 PCBs, most of the components are electronic components that you will likely source from the PCB manufacturer for them to be assembled with the PCBs.

divad1196, 2024-10-23:
Hi @waffle87

Thank you very much for responding in details and to all my questions. I was already sorry for asking newbie questions but I realize I was completely off..

Understood, there are no additional control as it is already on the PCB. I am not looking for anything special, I just thought that the controller had to be added manually afterward.

I am wondering: is there any downside to using the RP2040? Like maybe the ease during development? The price difference is so huge.

I didn't find much on "FR4 samdwich keyboard", but I think I understand the idea from the Corne's pictures.

The "-ex" is the version with the knobs? Or is it possible to put additional keys?

For the last part: at the time I wrote my questions, I already found out the BoM and PCL files. I was refering to things likr the M2 spacers.

About the BoM and PCL files:
- when I upload them, I always get a warning that they don't match
- the hotswap connector for hailh choc isn't available anymore and they are not able to obtain a quote from their provider so they refunded me. It does not seem to be any valid alternative on jlcpcb. I am now trying it with the MX version.

foostan, 2024-11-15:
> I am wondering: is there any downside to using the RP2040? Like maybe the ease during development? The price difference is so huge.

I have discontinued ProMicro because it can be simplified and compacted. The changes in v4 are available at https://github.com/foostan/crkbd/releases/tag/v4.0.

The RP2040 chip is cheaper than the one used in ProMicro. The PCBA process makes it more expensive. However, it also becomes cheaper if you make a large number of them. It is true that it is more expensive if you make a small number of them. I would like to find a way to make them cheaper, even in small quantities, at some point.

> The "-ex" is the version with the knobs? Or is it possible to put additional keys?

It's for both versions.
Please confirm the data.

> when I upload them, I always get a warning that they don't match

It's the same as https://github.com/foostan/crkbd/issues/272 and you can ignore it.

> the hotswap connector for hailh choc isn't available anymore and they are not able to obtain a quote from their provider so they refunded me. It does not seem to be any valid alternative on jlcpcb. I am now trying it with the MX version.

It's correct. I don't suggest using JLCPCB now; they do not have hot-swap parts.

zsoltkacsandi, 2025-02-21:
> It's correct. I don't suggest using JLCPCB now; they do not have hot-swap parts.

Do you have any other suggestions what PCB assembly service should we use?

I am a beginner and trying to build a Corne keyboard but I am having a hard time what should I do exactly and with which files.
If you can help, I am more than happy to contribute back into the documentation.

divad1196, 2025-02-22:
Hi @zsoltkacsandi ,
There are other companies like [PCBWay](https://www.pcbway.com/) . The files you get from this repository would work in many of these platforms. They will also provide you with alternatives (Sometimes).

I was finally able to get my keyboard done by JLCPCB. I used the connector from another brand that was also waaay cheaper. But honestly, beware the costs. You cannot ask for less than 5 PCB, you cannot order the components from them without getting it assembled for you. (But you can ask to assemble only one PCB). They made a mistake in my order and I got invoiced a lot more than expected, and I got charged additional customs by DHL because it was made in China.

I also personally struggle to find the components I needed (especially M2 spacers and screws, TRRS cable, ...)
The whole thing costed me around 250CHF. To that, I need to add the switches and keycaps that are really expensive (I 3D printed the case). Now, I need to find what to do with the 4 other assemble PCB, probably finish them and try to sell them.

Good luck.

Closed 2025-02-22.

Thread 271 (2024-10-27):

kailh CPG151101S11-16 & kailh CPG135001S30 unavailable. Alternatives ?

divad1196, 2024-10-27:
Hi,

I tried to place order for the Choc version then the MX version.
In both cases, the "Mechanical Keyboard Shaft ROHS" was not available in sufficient quantities and I had to pre-order them.

The issue is: they are unable to re-order them.
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

I found www.lcsc.com that looks similar to the shop in JLCPCB and found this component:
[HanElectricity CPG151101S11-16 ](https://www.lcsc.com/product-detail/Mechanical-Keyboard-Shaft_HanElectricity-CPG151101S11-16_C41430893.html) that is similar to [Kailh CPG151101S11-16](https://www.lcsc.com/product-detail/Mechanical-Keyboard-Shaft_Kailh-CPG151101S11-16_C5156480.html) but available and a almost 5 times cheaper. It also appears in [JLCPCB' shop but without any price](https://jlcpcb.com/partdetail/Hanelectricity-CPG151101S1116/C41430893).

Would it be a valid alternative, or is there any alternative product I could use?

foostan, 2024-10-27:
I saw [HanElectricity CPG151101S11-16](https://www.lcsc.com/product-detail/Mechanical-Keyboard-Shaft_HanElectricity-CPG151101S11-16_C41430893.html) for the first time, but looks compatible. Also, you can buy from other shops such as [kbdfans](https://kbdfans.com/products/mechanical-keyboard-switches-kailh-pcb-socket?variant=39678399381643), other keyboard vendor shops, aliexpress and more.

dahmwern, 2024-11-01:
They're available on Amazon. I just bought 50 here: https://www.amazon.com/dp/B0BVH6M5FP?ref=ppx_yo2ov_dt_b_fed_asin_title&th=1

divad1196, 2024-11-02:
@dahmwern they are way more expensive than what they were on jlcpcb, which is also way more expensive than the alternative here..

I just received the following question from JLCPCB:
> Since we are not so sure about the polarities of [C5149201](https://jlcpcb.com/partdetail/OpscoOptoelectronics-SK6812MINIE/C5149201) are correct or not. Could you please kindly check if the polarities and placements of the components are correct in the attached picture?
> 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

I don't know anything about the polarity.. but the placement seems to match the shapes and intended final result.

NOTE: The piece [C5149201](https://jlcpcb.com/partdetail/OpscoOptoelectronics-SK6812MINIE/C5149201) is the rgb led.

dahmwern, 2024-11-02:
That's the correct polarity. You can check polarity in KiCAD (free) using the files provided by Foostan on git.

foostan, 2024-11-15:
As @dahmwern says, it looks correct.

Chell-M, 2024-12-05:
@divad1196 did you proceed with the alternative HanElectricity CPG151101S11-16?

if so can you confirm they indeed work as needed?

divad1196, 2024-12-06:
> @divad1196 did you proceed with the alternative HanElectricity CPG151101S11-16?
>
> if so can you confirm they indeed work as needed?

"As needed" I guess yes.
At least, my keys are all responding.

But I am not actively using it for various reasons, so I cannot tell if they are good or not and if they will break in a few weeks.

foostan, 2025-02-09:
This issue looks to be resolved so I will close it.

Closed 2025-02-09.

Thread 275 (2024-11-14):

< 0.1mm track spacing on v4.1 choc

petermarks, 2024-11-14:
I'm trying to get some boards manufactured by PCBWay. The uploaded gerber fails their checks. They say it has track spacing less than 0.1mm and provide the following image:

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

Are you aware of this, or any other issues when uploading to PCBWay?

I'll try to fix it over the weekend and will submit a patch if you like.

foostan, 2024-11-15:
Thank you for sharing. You can fix it, but connecting it to the circuit is no problem. It may be possible to manufacture it as is.

gr8h, 2025-02-19:
@petermarks did you manage to fix this?

petermarks, 2025-02-19:
I had a quick look, but I'm not a kicad user, so didn't get anywhere without some investment in learning the tool. JLBPCB doesn't complain about it and the boards I had made by them work perfectly. As @foostan says, it isn't a problem as both tracks could be connected.

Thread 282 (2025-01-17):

Keyboard not working properly (one side is off with jack cable)

AndresMarronP, 2025-01-17:
Hello,

I purchased this keyboard three weeks ago, and I’ve recently encountered an issue with the interconnection cable. **One side of the keyboard stops working when connected via the double jack cable.**

I’ve tested the double jack cable with my headphones, and it seems to work fine, so I find it strange that this issue has arisen so soon after purchase. Also, the keyboard is working fine if we connected each part with a different USB Cable.

I hope this is just a software bug or a minor issue that can be resolved, as I’m quite disappointed. Additionally, I noticed another problem with the phone compatibility, which I wasn’t informed about at the time of purchase.

I’d appreciate your assistance in resolving this matter.

foostan, 2025-01-26:
I have not tested the operation with a double jack cable or stated that it is compatible. If other people also require a double jack cable, I will prioritize investigating it, but at this stage, I am not particularly considering it.

AndresMarronP, 2025-01-30:
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

I am referring to this middle cable (the one that connects both parts). As you can see, the other side is not working properly through this cable.

Jufralice, 2025-02-04:
Hello,

I have the same issue.
I have this keyboards since a few weeks now, and two days ago when I plugged in the keyboard into my computer, the two haves were not communicating anymore (just like explained @AndresMarronP ).
I did not flash any of the two halved recently, so I suspect that it's more an hardware issue than software...
Same as for @AndresMarronP, the two part works independently. But apparently no data pass through the serial cable anymore.
I also tested with another cable and that doesn't fix the problem.
My next step will be to disassemble the keyboard and check the welding of the jack connectors I guess...
then I'll try to test if a signal pass trough the jack connector using a voltmeter... somehow...
Any advice on how I should test/investigate this problem?

Thank you.

foostan, 2025-02-09:
> My next step will be to disassemble the keyboard and check the welding of the jack connectors I guess...
then I'll try to test if a signal pass trough the jack connector using a voltmeter... somehow...

@AndresMarronP @Jufralice

I think this approach should be good.
Could you tell me your version? 4.1?

If you have just purchased the item, please contact the store. There is a possibility that the item is defective.

Jufralice, 2025-02-09:
Hello,
Thank you for your response.

Yes I use the rev4_1/standard version

I guess that as it worked and then suddenly stopped working the day after without having flash it in the meantime, we can conclude that it's an hardware issue and not software?

Thanks.

Jufralice, 2025-02-09:
I took pictures of the jack connectors on the two parts.
I have the impression that some soldering might be a bit weak but I think that the contact should be done anyway...
But I'm not an expert at all... do you maybe see obvious soldering issues?

Thanks a lot.

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

Jufralice, 2025-02-16:
Hello,

Here are the following on my investigations

I tested the TRS cable connections using a voltmeter.
The connections seems ok:
- I mesure no resistance between each 3 pairs (tip to tip, ring to ring and slave to slave)
- I mesure infinite resistance (no short) between all other combinations (tip to ring, tip to slave, ring to slave,....)

I then measured the voltage when the keyboard is plugged-in (master half connected to the computer and the two halves connected to each other with the TRS cable):
- I mesure 3.3V between the ground and the ring of the TRS => even when I mesure it from the ground of the master half to the ring of the slave half, or the other way around
- I mesure 5V between the ground and the tip of the TRS => even when I mesure it from the ground of the master half to the tip of the slave half, or the other way around
- and I mesure 3.3V on all the switches (keys) (between the ground and the other switch pin) => Even on the slave half of the keyboard (the one that is not connected to the computer).

I then conclude that the 'power' do go through the slave half via the TRS cable
But for some reasons the 'signals' (for the leds and on keypresses) are not going through....

I guess that I am supposed to mesure a voltage variation between the ground and the ring or the tip of the TRS cable when I press a key right?
Because I do not mesure any voltage variation at all...

When I run the 'debug' mode I get these logs:
foostan:Corne v4:1: SPLIT: receiving handshake failed
foostan:Corne v4:1: Failed to execute slave_matrix
foostan:Corne v4:1: Target disconnected, throttling connection attempts

Do you confirm that it's normal that we have 3.3V on the ring of the TRS and 5V on the tip of the TRS?

Do you have any idea of what could be the problem? Could it still be a soldering issue even though I get these voltages?

Any idea of what I could investigate next ?
Or should I stop the investigation and return it to the shop?

Thanks for you help

foostan, 2025-02-17:
Thank you for confirming.

> Do you confirm that it's normal that we have 3.3V on the ring of the TRS and 5V on the tip of the TRS

It’s normal.
This is probably a hardware problem. The path from the TRS to the RP2040 may be broken or the RP2040 may be broken. It seems that it may fail if the TRS cable is unplugged and plugged in while the power is on.

> Any idea of what I could investigate next ?
Or should I stop the investigation and return it to the shop?

If you have another pair you can determine which one is broken. I am not a seller, so please decide whether or not to contact the shop.

Hlanden, 2025-06-11:
Hi,

I have the exact same issue as described by @Jufralice above. It most likely happened because I unplugged the TRS when the USB was powered on.

My investigations also shows that both LDOs seems to work just fine. I have stable 3.3 V and 5 V.
Both boards work when connected directly to USB.

So that leaves the TX line between the two RP2040s. Is this a correct assumption? Do you have any suggestions on how to fix this, or is it the internals of the MCU that are fried for the TX pin...? @foostan

Closed 2025-03-28.

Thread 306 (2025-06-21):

Touble with corne v4.1

ilyasilkin27, 2025-06-21:
my board is:

```
UF2 Bootloader v3.0
Model: Raspberry Pi RP2
Board-ID: RPI-RP2
```

i used this [guide](https://github.com/foostan/crkbd/blob/main/docs/firmware/rev4/firmware_en.md) to flash firmware. it worked nice for like month, no issues at all. But today i have problem out of nowhere, that left part  can't communicate with right part. individually they are work

may someone help me please, idk what to do at all in this situation (my first split keyboard)

in video i show how right part start glitching when i connect them by wire

[video on google drive](https://drive.google.com/file/d/1Ho4052TIJMYA3eiu1BZcnMM_5iRadtqx/view?usp=sharing)

foostan, 2025-06-22:
- Does it work properly when only the right side is connected to a PC?
- Is the TRRS cable OK?
- Is the TRRS connector damaged?

foostan, 2025-06-22:
Plugging and unplugging the TRRS cable while the power is on may cause a malfunction. This may have caused hardware failure.

ilyasilkin27, 2025-06-22:
I didn't really touch the TRRS cable much, meaning I flashed it once and then didn't touch the wires at all after that. So in the end, does this mean the keyboard won't work via the TRRS cable?

foostan, 2025-06-24:
In the video you shared, you plugged in and unplugged the TRRS cable while the keyboard is still connected to the PC, which can cause a malfunction.

Closed 2025-06-25.

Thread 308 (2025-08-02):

Questions about corne-cherry v2.1 PCB

sahand291, 2025-08-02:
I want to build cherry-corne v2.1. but since I could not found SK6812MINI in Iran market and its hard to buy from outside. Want to change on PCB design to SK6812MINI-ER. and then print. and maybe add a switch since want to make it wireless.

but I have a question.

1. When i run design rule checker (before changing anything) shows me hundreds of errors. Are these OK? or is just something wrong with rules and they have to be customized to fit with this design?.

2. and is there footprint library of parts? i did not found anything in v2.1 tag.

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

thank you for you great design. :)

foostan, 2025-08-02:
Most errors should be fine, but since it's old data, some problems may remain. One reason is that the Kicad version has been updated and the number of design checks has increased.

Please search footprint data from https://github.com/foostan/kbd. v2 parts may have changed now.

sahand291, 2025-08-02:
thanks for the respond. i will change the led to SK6812-ER and try to add battery socket and switch. hope it work. and will share about my experience in discord server :)

I'm closing this issue.

Closed 2025-08-02.

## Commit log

2018-04-10 Add pcb
    [crkbd.kicad_pcb, crkbd.sch]
2018-04-10 Fix LED pads
    [crkbd.kicad_pcb]
2018-04-10 Add case
    [crkbd.dwg]
2018-04-14 Update ProMicro
    [crkbd.kicad_pcb]
2018-04-14 Add i2c pin
    [crkbd.kicad_pcb, crkbd.sch]
2018-04-14 Update Mounting holes
    [crkbd.kicad_pcb]
2018-04-16 Reset lines
    [crkbd.kicad_pcb, crkbd.sch]
2018-04-16 Add vcc lines
    [crkbd.kicad_pcb]
2018-04-18 Add underground leds
    [crkbd.kicad_pcb, crkbd.sch]
2018-04-19 Add VCC and GNC lines for LED
    [crkbd.kicad_pcb]
2018-04-19 Add lines for LEDs
    [crkbd.kicad_pcb]
2018-04-19 Add col and row lines
    [crkbd.kicad_pcb]
2018-04-20 Add lines for ProMicro
    [crkbd.kicad_pcb]
2018-04-20 Fix hole size
    [crkbd.kicad_pcb]
2018-04-22 Release v1.0
    [crkbd.dwg, crkbd.kicad_pcb]
2018-05-14 Update for publish
    [crkbd.kicad_pcb]
2018-05-14 Reverse underground leds
    [crkbd.kicad_pcb]
2018-05-14 To throw holes
    [crkbd.kicad_pcb]
2018-05-14 To Mask desc
    [crkbd.kicad_pcb]
2018-05-26 Fix key holes
    [crkbd.dwg]
2018-05-28 Add gerber
    [crkbd.kicad_pcb]
2018-05-28 Export case data
    [crkbd.dwg, crkbd.dxf]
2018-06-03 Update frames of case
    [crkbd.dwg, crkbd.dxf]
2018-06-09 Resize hole and replace lines
    [crkbd.dwg, crkbd.dxf]
2018-06-20 Update holes of switches
    [crkbd.dwg]
2018-06-21 Update case files
    [crkbd.dxf]
2018-06-25 Update case holes
    [crkbd.dwg, crkbd.dxf]
2018-08-02 Add new lineups
    [crkbd.dwg, crkbd.dxf, crkbd.kicad_pcb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]
2018-08-10 Replace footprints for double hotswapable
    [crkbd-mix.sch]
2018-08-21 Add dxf files
    [crkbd-B.Cu.dxf, crkbd-B.Mask.dxf, crkbd-B.SilkS.dxf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]
2018-08-24 remove unused projects
    [crkbd-mix-2018-08-10-14-27-32.sch, crkbd-mix.kicad_pcb, crkbd-mix.sch]
2018-08-24 Rename crkbd to corne classic and some fix
    [corne-classic.kicad_pcb, corne-classic.sch, crkbd-B.Cu.dxf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]
2018-08-24 Rewrite case files by illustrator
    [crkbd.dwg, crkbd.dxf]
2018-08-24 Setup corne cherry
    [corne-cherry.kicad_pcb, corne-cherry.sch]
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2018-08-31 Update LED foot prints
    [corne-classic.kicad_pcb]
2018-08-31 Update corne-cherry
    [corne-cherry-bottom-plate.kicad_pcb, corne-cherry-top-plate.kicad_pcb, corne-cherry.kicad_pcb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]
2018-08-31 Fix plate directories
    [corne-cherry-bottom-plate.kicad_pcb, corne-cherry-top-plate.kicad_pcb]
2018-08-31 Setup prot
    [corne-cherry-bottom-plate.kicad_pcb, corne-cherry-top-plate.kicad_pcb, corne-cherry.kicad_pcb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]
2018-09-12 Update refs in pcbnew
    [corne-classic.kicad_pcb, corne-classic.sch]
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2018-10-13 Remove corne-cherry and update README
    [corne-cherry-bottom-plate.kicad_pcb, corne-cherry-top-plate.kicad_pcb, corne-cherry.kicad_pcb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]
2018-10-18 Publish corne-cherry
    [corne-cherry-bottom-plate.kicad_pcb, corne-cherry-top-plate.kicad_pcb, corne-cherry.kicad_pcb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]
2018-11-14 Update switch hole size and gnd pattern
    [corne-cherry-bottom-plate.kicad_pcb, corne-cherry-top-plate.kicad_pcb, corne-cherry.kicad_pcb]
2018-11-15 Fix version
    [corne-cherry-top-plate.kicad_pcb, corne-cherry.kicad_pcb]
2018-11-16 Copy cherry to chocolate
    [corne-chocolate-bottom-plate.kicad_pcb, corne-chocolate.kicad_pcb, corne-chocolate.sch]
2018-12-09 Update to v2.1
    [corne-chocolate.kicad_pcb]
2018-12-09 Remove unnecessary files
    [corne-chocolate-bottom-plate.kicad_pcb]
2018-12-09 Update top-plate
    [corne-cherry-top-plate.kicad_pcb]
2018-12-09 Clean common files
    [corne-cherry-bottom-plate.kicad_pcb, corne-cherry-top-plate.kicad_pcb, corne-cherry.kicad_pcb]
2018-12-09 Update holes
    [corne-cherry.kicad_pcb]
2018-12-09 Add CherryMX_MidHeight_Choc_Hotswap and fix holes
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2018-12-31 Some updates
    [corne-cherry-top-plate.kicad_pcb, corne-cherry.kicad_pcb]
2018-12-31 Fix acrylic plate size
    [corne-classic-tent.dxf, corne-classic.dxf]
2018-12-31 Add corne-light
    [corne-light.kicad_pcb, corne-light.sch]
2019-02-10 Update tent plate
    [corne-classic-tent.dxf]
2019-02-10 Rename acrylic_plates
    [tilting-tenting.dxf, top-bottom.dxf]
2019-02-10 Update lines
    [corne-cherry.kicad_pcb]
2019-02-15 Brashup righ hand
    [corne-light.kicad_pcb, corne-light.sch]
2019-02-19 Update light
    [corne-light.kicad_pcb, corne-light.sch]
2019-02-19 Update cherry
    [corne-cherry.kicad_pcb]
2019-02-22 Update buildguide_tilting_tenting_plate_jp.md
    非対応分を明確に修正
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2019-10-02 Move acrylic_plate
    [tilting-tenting.dxf, top-bottom.dxf]
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2019-10-02 Add plate for mini
    [top-bottom.dxf]
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2019-11-17 Update corne-right to rev1.1.1
    [corne-light.kicad_pcb]
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2019-11-26 Add top-plate for light
    [corne-light.kicad_pcb, corne-top-plate.kicad_pcb]
2019-12-13 fixed typo
    [corne-cherry.kicad_pcb, corne-chocolate.kicad_pcb, corne-classic.kicad_pcb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]
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2020-02-11 Move case/acrylic_plate to plates
    [imk_top-bottom.dxf, tilting-tenting_top-bottom.dxf, top-bottom.dxf]
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2020-04-13 Add kailh low profiile
    [corne-light.kicad_pcb]
2020-05-19 Add tenting mini crkbrd version
    [top-bottom.dxf]
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2020-08-04 Update cuts and footprints
    [corne-light.kicad_pcb, corne-light.sch]
2020-08-08 Add release gerber files GitHub Actions workflow
    [corne-bottom-plate.sch, corne-top-plate.sch]
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2020-09-05 Update corne cherry to v3.0
    [corne-cherry.kicad_pcb, corne-cherry.sch]
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2020-09-27 Update corne-cherry to v3.0.1
    [corne-cherry.kicad_pcb]
2020-10-13 Update libs of corne-light
    [corne-light.kicad_pcb, corne-light.sch]
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2020-11-03 Add try mount plate
    [corne-top-plate-tray-mount.kicad_pcb]
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2020-11-13 Create or Update plate data for corne-light
    [corne-top-plate-alps.kicad_pcb, top-bottom.dxf]
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2020-11-13 Update corne light plates
    [corne-top-alps-plate.kicad_pcb, corne-top-alps-plate.sch]
2020-11-14 Add add holes for mini
    [corne-light.kicad_pcb]
2020-11-30 Fix spacer length and screw length
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2021-01-23 Update buildguide_en.md typo fix
    Minor cleanup commit fixing a typo wholes -> holes) in the English build guide.
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2021-08-24 Fix the outlines of classic
    [corne-classic.kicad_pcb]
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2021-11-07 Update README.md
    https://forum.kicad.info/t/warning-avoid-all-links-to-kicad-pcb-org-use-kicad-org/31521
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2022-04-07 Fix the PCB outline of chocolate
    [corne-chocolate.kicad_pcb]
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2023-09-23 Fix pin number
2023-09-23 Squashed 'pcb/kbd/' changes from 8cc619e..b354fc0
    b354fc0 Fix pin number
    git-subtree-split: b354fc02b871ef1c24bf8d03fd3ff7a7ee5d9545
    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
2023-09-30 Squashed 'pcb/kbd/' changes from 3a51036..1e68599
    1e68599 Fix positions
    git-subtree-split: 1e6859946104ea7de8c202f10c3c8eddc143db14
    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
2023-09-30 Squashed 'pcb/kbd/' changes from 1e68599..a1a5b18
    a1a5b18 Fix pad positions
    git-subtree-split: a1a5b18d8f7a5969aae8d740563d380ecc7f5430
    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
2023-09-30 Fix footprint type
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2023-09-30 Squashed 'pcb/kbd/' changes from a2fdf46..148d932
    148d932 Fix footprint type
    git-subtree-split: 148d9328eeec21db74b07cd60d3d3c1f7de27ad5
    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
2023-09-30 Fix some errors
    [corne.kicad_pcb]
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2023-09-30 Squashed 'pcb/kbd/' changes from 043d4bd..affd835
    affd835 Fix some errors
    git-subtree-split: affd835c5e016fcd3ccc134c3d0e4198a99b2d4d
    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
2023-10-04 Squashed 'pcb/kbd/' changes from affd835..fe5de30
    fe5de30 Add parts area
    0f5ea3b Fix attr
    git-subtree-split: fe5de303769462056fd0c544a8fa1ca451ca1390
    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
2023-10-05 Fix the `nerdyscout/kicad-exports` schema args
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2023-10-07 Fix footprints
2023-10-07 Squashed 'pcb/kbd/' changes from 41976fe..7d74185
    7d74185 Fix footprints
    git-subtree-split: 7d741855d240a547847f258a2e0e18a2b7158eb2
    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
2023-10-07 Squashed 'pcb/kbd/' changes from 7d74185..53b71bc
    53b71bc Fix ref size
    git-subtree-split: 53b71bc4bfd7a9b551b3a8283b9c1c7a54f56529
    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
2023-10-16 Squashed 'pcb/kbd/' changes from 53b71bc..b377b10
    b377b10 Fix position
    git-subtree-split: b377b107aabd5b0266aa88b4489bf3631e9000c8
    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
2023-11-06 Update footprints and sch
    [left.kicad_sch, right.kicad_sch]
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2023-11-09 Fix pcb for jlcpcb policy
2023-11-11 Fix the thumb key for alps pcb plate
    [corne-top-alps-plate.kicad_pcb]
2023-11-11 Update pcbs fix to creatable
    [BOM-corne-cherry.csv, BOM-corne-chocolate.csv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]
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2023-11-12 Fix choc footprints
2023-11-12 Squashed 'pcb/common/kbd/' changes from 51de1d9..52290c7
    52290c7 fix gateron low profile
    e24354d Fix choc footprints
    d3325a6 Update
    e87945a Update footprints for crkbd4
    git-subtree-split: 52290c77f0f5b70e980768bd36c01103892abc8f
    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
2023-12-20 Fix fixed pin
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2023-12-20 Update choc v2 fixed pin
    [BOM-corne-chocolate.csv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]
2024-01-26 Update pcb plate files
    [plate-top-alps-ex.kicad_pcb, plate-top-alps.kicad_pcb, plate-top-cherrymx-ex.kicad_pcb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]
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2024-03-18 Fix for footprints for choc v2
    [CPL-corne-chocolate.csv]
2024-03-18 Add the mini case
    [left.step, right.step]
2024-04-19 Fix GND/VCC for mini version
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2024-04-24 Squashed 'pcbs/common/kbd/' changes from a74626e..c53bf51
    c53bf51 Fix pin name
    git-subtree-split: c53bf519ed9e0a498869ab56d44385f89ec54b36
    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
2024-05-30 ファームウェアのリンク切れを修正
    おそらくV4が出たことにより、ファームウェアのリンクが切れていたので、urlの修正を提案させていただきます。
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
